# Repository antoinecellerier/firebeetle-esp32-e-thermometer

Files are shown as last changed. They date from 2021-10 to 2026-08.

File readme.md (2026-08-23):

A low power ESP32 based thermometer with an ePaper display

| Prototype | Custom board |
|---|---|
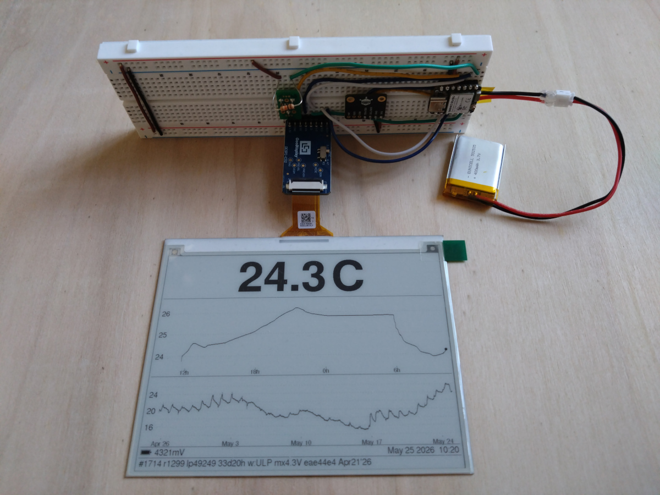
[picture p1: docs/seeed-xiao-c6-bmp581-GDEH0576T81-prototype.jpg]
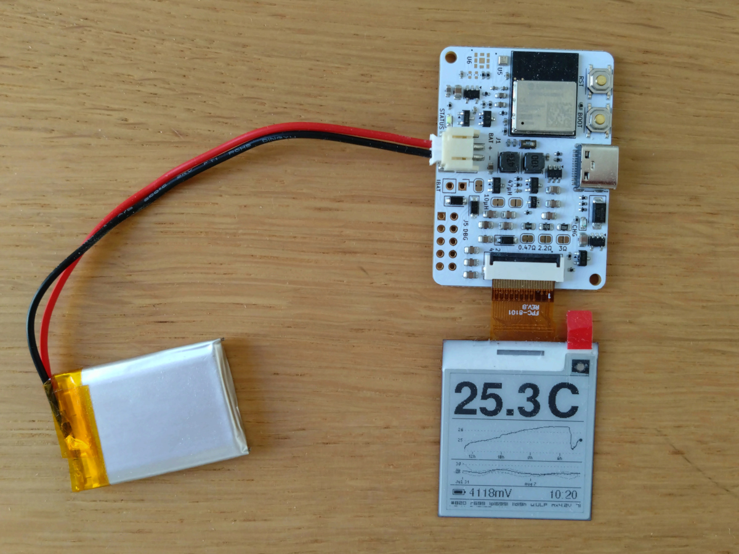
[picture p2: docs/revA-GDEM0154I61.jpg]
|||

See [docs/wiring.md](docs/wiring.md) for prototype wiring information and [hardware/thermometer-c6/](hardware/thermometer-c6/README.md) for the custom board. More pictures [lower down](#prototypes-in-action).

# Power consumption

Measured with a Nordic PPK2 on pure ESP-IDF firmware; full traces, dates and
methodology in [docs/notes.md](docs/notes.md). Figures are config-specific —
panel, sensor and board all matter.

**Read the node tag on every figure.** `@3V3 rail` is the load alone, with the
board's input tree bypassed; `@4V2 bat` is the whole deployment path, regulator
and charger leakage included. They are not interchangeable, and the battery
figure is not simply the larger one.

| Setup | Deep-sleep floor | Sensor wake | Wake + refresh |
|---|---|---|---|
| Firebeetle ESP32-E + BMP390L + GDEH0154Z90 via DESPI-C02 (FDN340P gate) | 19–20 µA `@3V3 rail` | ULP bit-bang I2C every 5 s, avg ≈0 | ~112 mC `@3V3 rail` (was ~600 mC before light sleep — the Z90's ~21 s refresh used to spin-wait) |
| XIAO ESP32-C6 + BMP581 + GDEH0576T81 via DESPI-C02 (FDN340P gate) | 15.5–16 µA `@3V3 rail` | LP core I2C every 60 s: ~1 mA × 3 ms | ~45 mC `@3V3 rail` — **superseded, re-measure** (see below) |
| XIAO ESP32-C6 + BMP581 + GDEW029I6FD via Seeed ePaper Driver Board (no gate) | ~25 µA `@3V3 rail`<br>**21.7 µA `@4V2 bat`** | LP core I2C every 60 s: ~1 mA × 3 ms | 12.2 mC `@3V3 rail`<br>**10.05 mC `@4V2 bat`** |
| thermometer-c6 rev A + BMP581 + GDEM0154I61 (on-board gated booster) | **18.3 µA `@4V2 bat`** | LP core I2C every 60 s | **~24.3 mC `@4V2 bat`** |
| thermometer-c6 rev A + BMP581 + GDEH0576T81 (on-board gated booster) | **19.05 µA `@4V2 bat`** | LP core I2C every 60 s | **36.77 mC `@4V2 bat`** |

The XIAO's GDEH0576T81 figure is **superseded**: it was taken while the panel ran
its coldest waveform LUT, which cost 48% of panel busy time. The last row is the
deployment configuration on the corrected waveform — daily budget and derivation
in [docs/notes.md](docs/notes.md).

A buck draws *less* current at 4.2 V than its load does at 3.3 V, which is why
~25 µA at the rail reads 21.7 µA at the battery (~90 % efficient). An LDO runs
the other way, ~1.15× the charge for the same work — so the custom board beating
the XIAO by 3 µA at the same 4.2 V is a real win, not a topology artefact. Its
wake figures include LED blinks, left on for observability. Blank cells are
unmeasured, not zero; both are on the PPK2 backlog.

The main CPU only wakes on a ≥0.1 °C delta or a safety-net tick, so a display
refresh is the dominant event on a typical day. At one refresh per hour that puts
long-term averages in the **~16–51 µA band depending on rig and refresh cadence**
— load-only runtime of roughly **1–3 years on a 400 mAh LiPo**, with the
deployment configuration measured at the bottom of that band (~2.3–3.8 C/day,
~380–620 days; derivation in [docs/notes.md](docs/notes.md)). But at this
current level LiPo self-discharge (a few %/month ≈ 15–25 µA equivalent) rivals
the load itself, so **expected runtime is on the order of a year**, and a
2600 mAh 18650 will age out before the load meaningfully drains it. Not yet
confirmed against a full-length run.

Two gotchas worth surfacing (the adapter-leakage ones are under Hardware below):
- **XIAO ESP32-C6 battery operation has a hard floor at ~3.6 V**: its 3.3 V rail is a pure buck (SGM6029C), which below VOUT + ~245 mV starves its bootstrap and lets the rail sag ~a VTH below VBAT — deep sleep survives, but wakes collapse into 0.5–0.9 A brownout-restart storms. Firmware shuts down at 3.7 V (~12–15 % of Li-ion capacity abandoned); full regime map in [docs/notes.md](docs/notes.md). LiFePO₄ cells (3.2 V nominal) are unusable on this board. The custom board uses an LDO and shuts down at 3.5 V instead.
- **Don't use the Seeed ePaper Driver Board's JST battery connector**: its ETA9740 charger/boost idles at ~330–500 µA — ~20× the whole system's sleep floor, flattening a 400 mAh cell in ~7 weeks doing nothing — and it double-converts BAT→5 V→3.3 V. Solder the battery to the XIAO's underside BAT pads instead, JST empty, switch off.

The Arduino-era ~20 mA deep-sleep USB CDC gotcha is gone: the pure-IDF
USB-Serial-JTAG console doesn't hold the port active.

For context: the original 2021 prototype (wake + refresh every 60 s, no ULP) ran a 2600 mAh cell flat in 8.5 days at ~12.6 mA average — the ULP/LP-core redesign is ~700× more efficient.

# Hardware

Looking to replicate this? Easy to start with options are tagged **[start with this]** below.

## Controller boards
- thermometer-c6 — the custom board this project builds towards, replacing the
  dev-board rigs below: ESP32-C6-MINI-1 + BMP581, a universal 24-pin FPC panel
  interface with the Good Display booster on-board and P-FET-gated, USB-C charging,
  an LDO 3.3 V rail, a GPIO-switched battery divider and a 32.768 kHz crystal.
  Schematic, PCB and rationale: [hardware/thermometer-c6/](hardware/thermometer-c6/README.md)
- Seeed Studio XIAO ESP32-C6 https://wiki.seeedstudio.com/xiao_esp32c6_getting_started/ **[start with this]**
- (Early 2021 prototype) Firebeetle ESP32-E https://wiki.dfrobot.com/FireBeetle_Board_ESP32_E_SKU_DFR0654
  - ESP32 datasheet https://www.espressif.com/sites/default/files/documentation/esp32_datasheet_en.pdf
  - ESP32-WROOM-32E datasheet  https://www.espressif.com/sites/default/files/documentation/esp32-wroom-32e_esp32-wroom-32ue_datasheet_en.pdf
  - TP4056 battery charger IC (onboard) https://dlnmh9ip6v2uc.cloudfront.net/datasheets/Prototyping/TP4056.pdf https://www.best-microcontroller-projects.com/tp4056.html

- ESP32 getting started https://docs.espressif.com/projects/esp-idf/en/latest/esp32/get-started/index.html
- ESP32 power consumption https://diyi0t.com/reduce-the-esp32-power-consumption/

## Temperature sensor (multiple options)
- BMP390L I2C interface:
  - datasheet https://www.bosch-sensortec.com/media/boschsensortec/downloads/datasheets/bst-bmp390-ds002.pdf
  - breakout board https://wiki.dfrobot.com/Fermion_BMP390L_Digital_Barometric_Pressure_Sensor_SKU_SEN0423
- BMP581 / BMP585 I2C interface (Bosch next-gen pressure sensors, ~0.5 µA deep-standby)
  - BMP581 https://www.bosch-sensortec.com/products/pressure-sensors/bmp581/
  - BMP585 https://www.bosch-sensortec.com/products/pressure-sensors/bmp585/
  - Fermion breakouts:
    - SEN0667 (BMP581) https://wiki.dfrobot.com/sen0667/ **[start with this]**
    - SEN0666 (BMP585) https://wiki.dfrobot.com/sen0666/
- (Early 2021 prototype) DS18B20-PAR OneWire interface
  - datasheet https://datasheets.maximintegrated.com/en/ds/DS18B20-PAR.pdf

## Display (multiple options)
- Good Display GDEW0154M09 black and white, 200x200, 1.54" fast full refresh https://www.good-display.com/product/206.html
- Good Display GDEW0213M21 black and white, 212x104, 2.13" DES screen https://www.good-display.com/product/354.html
- Good Display GDEW029I6FD black and white flex, 296x128, 2.9" (UC8151D, partial updates) https://www.good-display.com/product/209.html
- Good Display GDEM0154I61 black and white flex, 200x200, 1.54" (driven via GDEY0154D67 SSD1681 driver) https://www.good-display.com/product/535.html
- Good Display GDEH0576T81 black and white, 920x680, 5.76" HD (SSD2677, partial updates) https://www.good-display.com/product/702.html **[start with this]**
- (Early 2021 prototype) Adafruit 1.54" Tri-Color eInk / ePaper 200x200 Display with SRAM - SSD1681 Driver
https://www.adafruit.com/product/4868
https://learn.adafruit.com/adafruit-1-54-eink-display-breakouts?view=all
  - uses Good Display GDEH0154Z90 https://www.good-display.com/product/285.html

Good Display panels are driven through one of two adapters (same Good Display reference booster on both — panel compatibility notes in [docs/wiring.md](docs/wiring.md)):
- Good Display DESPI-C02 (switchable RESE 0.47/3 Ω) https://www.good-display.com/product/516.html
- Seeed ePaper Driver Board for XIAO (fixed RESE 0.47 Ω, ETA9740 charger — see gotcha above) https://www.seeedstudio.com/ePaper-breakout-Board-for-XIAO-V2-p-6374.html — wiki: https://wiki.seeedstudio.com/xiao_eink_expansion_board_v2/ **[start with this]**

The DESPI-C02's boost converter leaks ~534 µA in deep sleep, which an FDN340P P-channel MOSFET on the adapter's 3.3 V line eliminates; the Seeed board's ungated standby measured only ~9 µA, so it runs without a gate.

## Other components
- FDN340P P-channel MOSFET (SOT-23) — power-gates DESPI-C02 3.3 V during deep sleep
- AO3400A N-channel MOSFET (SOT-23) — switches the XIAO C6 battery voltage divider so it doesn't draw ~10 µA continuously

## Battery
- Current builds: PR502535 single-cell LiPo pouch, 400 mAh https://www.gotronic.fr/art-accu-lipo-3-7-vcc-400-mah-pr502535-5812.htm **[start with this or equivalent]**
- Original prototype: RS Pro 18650 26H Li-ion, 2600 mAh https://fr.rs-online.com/web/p/batteries-taille-speciale/1449406/

## Prototypes in action

### 2026 - ultra low power custom board

Custom rev A board (with BMP581), GDEM0154I61 & 400mAh battery

Thermometer C6 rev A board & GDEM0154I61 (2026)

Custom rev A boards (with BMP581), GDEH0576T81 & 400mAh battery

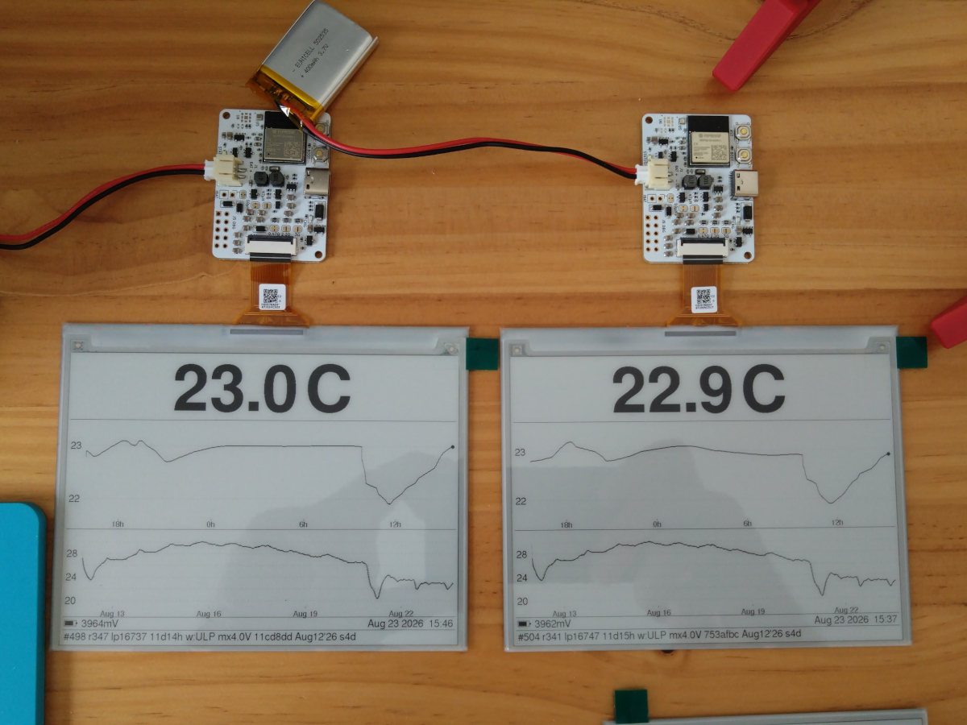
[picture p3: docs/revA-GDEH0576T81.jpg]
Thermometer C6 rev A boards 2 and 4 & GDEH0576T81 (2026)


### 2026 - ultra low power prototypes

Seed Xiao C6, BMP581, GDEH0576T81 & 400mAh battery

Seeed Xiao C6, BMP581 & GDEH0576T81 (2026)

Seeed Xiao C6, e-Paper Driver Board, BMP581, GDEW029I6FD & 400mAh battery

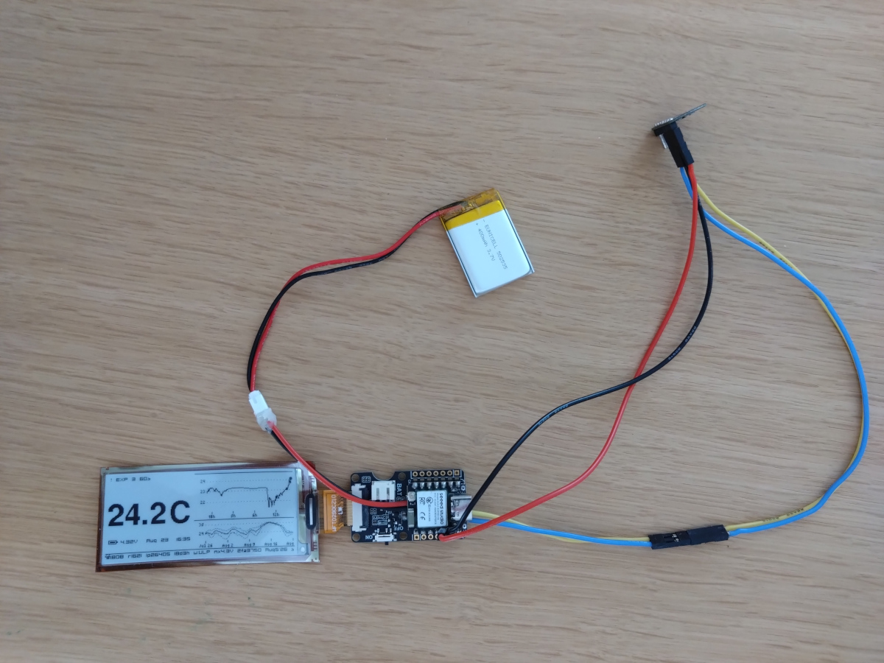
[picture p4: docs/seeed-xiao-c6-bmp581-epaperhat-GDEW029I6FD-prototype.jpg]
Seeed Xiao C6, e-Paper Driver Board, BMP581 & GDEW029I6FD (2026)


Firebeetle ESP32-E, BMP390L, GDEH0154Z90 & 400mAh battery

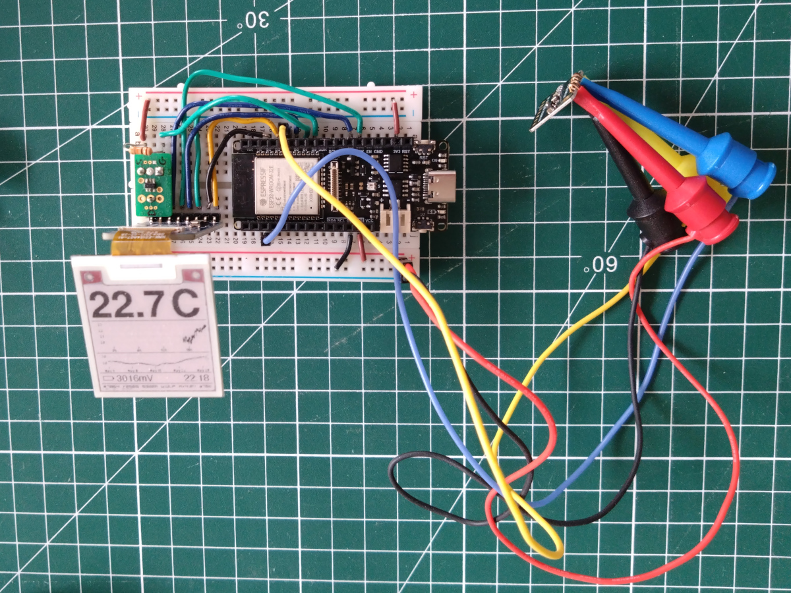
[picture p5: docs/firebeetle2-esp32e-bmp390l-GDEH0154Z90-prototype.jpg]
Firebeetle ESP32-E, BMP390L & GDEH0154Z90 (2026)


### 2021 - first prototype
Firebeetle ESP32-E, DS18B20, GDEW0213M21 & 2600mAh battery

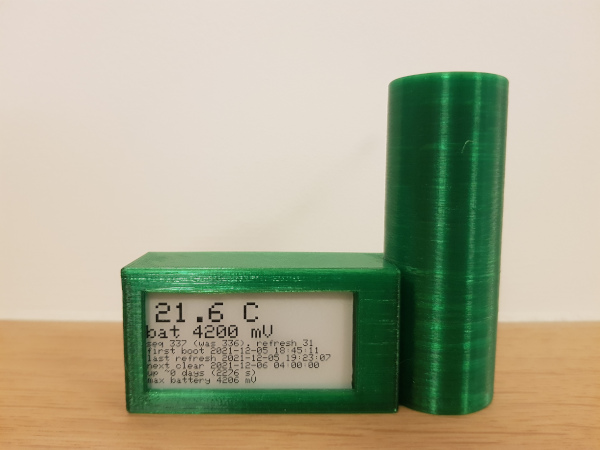
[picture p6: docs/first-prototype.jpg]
Assembled first prototype (2021)


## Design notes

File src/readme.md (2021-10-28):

A low power FireBeetle ESP32-E based thermometer with an Adafruit ThinkInk 1.54" ePaper display

# Hardware

## Controller board
- Firebeetle ESP32-E https://wiki.dfrobot.com/FireBeetle_Board_ESP32_E_SKU_DFR0654
- ESP32 datasheet https://www.espressif.com/sites/default/files/documentation/esp32_datasheet_en.pdf
- ESP32-WROOM-32E datasheet  https://www.espressif.com/sites/default/files/documentation/esp32-wroom-32e_esp32-wroom-32ue_datasheet_en.pdf
- TP4056 battery charger IC https://dlnmh9ip6v2uc.cloudfront.net/datasheets/Prototyping/TP4056.pdf
 https://www.best-microcontroller-projects.com/tp4056.html

- ESP32 getting started https://docs.espressif.com/projects/esp-idf/en/latest/esp32/get-started/index.html
- ESP32 power consumption https://diyi0t.com/reduce-the-esp32-power-consumption/

## Temperature sensor
- DS18B20-PAR datasheet https://datasheets.maximintegrated.com/en/ds/DS18B20-PAR.pdf

## Display
- Adafruit 1.54" Tri-Color eInk / ePaper 200x200 Display with SRAM - SSD1681 Driver
https://www.adafruit.com/product/4868
https://learn.adafruit.com/adafruit-1-54-eink-display-breakouts?view=all

## Battery
- RS Pro 18650 26H Li-ion Battery Pack https://fr.rs-online.com/web/p/batteries-taille-speciale/1449406/

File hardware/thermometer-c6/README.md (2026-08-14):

# thermometer-c6 — custom ultra-low-power e-paper thermometer board

Custom PCB replacing the XIAO-C6/FireBeetle dev-board rigs. ESP32-C6-MINI-1 +
BMP581 + universal 24-pin EPD interface with on-board gated booster, USB-C
charging, LDO power tree. Design driven by the PPK2 measurement campaign in
[`docs/notes.md`](../../docs/notes.md) (repo root).

Thermometer C6 rev A board & GDEM0154I61 (2026)

**Status: rev A built and working.** Ordered 2026-07-20
([`archive/order-2026-07-20/`](archive/order-2026-07-20/); landed €273.93 ≈
€68.50/assembled board, breakdown in [`ORDERING.md`](ORDERING.md)). Board 1
passed bring-up Phases 0–2 on 2026-07-29 ([`BRINGUP.md`](BRINGUP.md)): first
render, LP-core survival, and a measured 18.3µA @ 4.2V deployment-path sleep
floor over a full field interval (docs/notes.md 2026-07-29) — vs 21.7µA at
the same 4.2V on the XIAO buck rig, validating the LDO tree. **Phase 3 is under
way on board 2, not board 1**: the GDEH0576T81 panels arrived 2026-08-11 and
board 2 took one plus a battery, so the phase is no longer gated on board 1
leaving its soak (still running since 2026-07-31; harvest before resetting it).
Closed on board 2 that day: the deployment configuration's power figures
(19.05µA floor, 36.77mC wake+refresh `@4V2 bat`), the boost rails under the
heaviest waveform the panel can be given (no sag — this is the evidence the
rev B bridge deletion was waiting on), the VBAT_ADC point (−24mV at 4.2V, 2mV
from board 1), the battery-floor sweep, and the WiFi resync charges. Board 2
went straight to flash on the strength of board 1's pass, worked first time,
and is both the bench board and now the Phase 3 vehicle; boards 3–4 are still
in the bag. The board is 48×35mm
2-layer, hand-routed, DRC-clean at full severity; fab export is `make fab`
(gerbers/drill + CPL/BOM zip, git-hash+date stamped, gated by
`verify/check_fab.py`); pre-order schematic sign-off (requirements proven
against primary sources, findings + dispositions):
[`SCHEMATIC-VERIFICATION.md`](SCHEMATIC-VERIFICATION.md).

## Why these choices (measurement rationale)

| Decision | Measurement behind it |
|---|---|
| LDO (not buck) 3.3V rail | XIAO's SGM6029C buck: razor-sharp dropout cliff at 3.545V → 0.5–0.9A brownout storms; forces 3.70V firmware shutdown, wasting ~12–15% of pack (notes.md 2026-07-05) |
| P-FET-gated EPD booster | DESPI-C02 leaks ~534µA with panel asleep; FDN340P gate mod → ~18µA (notes.md) |
| Switched 100k/100k battery divider | Always-on 200k divider ≈ 10µA (~⅔ of the sleep floor); 1M/1M biases the C6 SAR ADC low (~300ns sample window) (wiring.md) |
| High-side divider switch | Low-side switch leaves the sense node at VBAT through the top 100k → pin ESD diode clamps into 3V3 above ~3.7V (~5µA at 4.2V) |
| Load-sharing USB path | Without it, no-battery USB operation is limited to the 100mA charge current — EPD refresh peaks at ~465mA |
| Reverse-battery P-FET (Q6) | JST vs Adafruit pigtail polarity is a real supply-chain trap; MCP73831 abs-max is −0.3V — one AO3401A makes it survivable |
| EPD gate soft-start (R24/C28) | GPIO14 slamming Q2 on charge-shares 10µF against the rail faster than the LDO loop — ~100µs ramp kills the brownout risk |
| VBUS sense (R22/R23 → GPIO4) | Firmware needs to know USB is present: VBAT_ADC reads the charger CV node while charging, and SoC logic must ignore it; zero draw with USB absent |
| Jumper-selected inductor (JP5/JP6) | 10µH proven on all panels; 47µH per the GDEH0576T81 datasheet (with 2.2Ω RESE) — jumpers sit on the switch-node side so the unselected coil idles on the DC rail |
| 32.768kHz crystal | C6 on internal RC runs hours fast over weeks (memory: project_c6_clock_drift) |

## Reference transcription: DESPI-C02 V1.0 (Good Display, 2018-07-06)

Transcribed from `hardware/DESPI-C02_SCH V1.0.pdf` (visual + embedded netlist),
2026-07-07. This is the booster we replicate (with EPD_VCC gating added).

### 24-pin 0.5mm FPC panel pinout (P1, "FPC24(0.5MM)")

| Pin | Name | DESPI connection | Pin | Name | DESPI connection |
|---|---|---|---|---|---|
| 1 | NC | — | 13 | SCLK | host SPI SCK |
| 2 | GDR | Q1 gate + R1 10k→GND | 14 | SDI | host SPI MOSI |
| 3 | RESE | Q1 source + Rsense→GND | 15 | VDDIO | 3.3V |
| 4 | VGL | C1 4.7µF/25V→GND | 16 | VCI | 3.3V |
| 5 | VGH | C2 4.7µF/25V→GND | 17 | VSS | GND |
| 6 | TSCL | — (touch variant only) | 18 | VDD | C7 1µF/50V→GND |
| 7 | TSDA | — (touch variant only) | 19 | VPP | C8 1µF/50V→GND |
| 8 | BS | R4 3Ω→GND (= tied low, 4-wire SPI) | 20 | VSH | C9 4.7µF/25V→GND |
| 9 | BUSY | host | 21 | PREVGH | C5 4.7µF/25V→GND + D3 cathode |
| 10 | RES | host + R5 10k→3.3V pull-up | 22 | VSL | C10 4.7µF/25V→GND |
| 11 | D/C | host | 23 | PREVGL | C11 4.7µF/25V→GND + D1 anode |
| 12 | CS | host | 24 | VCOM | C12 1µF/50V→GND |

### Booster topology (all diodes MBR0530; orientation by function, not pin #)

- L1 10µH/1A: 3.3V → SW node
- Q1 Si1308EDL N-FET: gate=GDR (R1 10k bleed to GND), drain=SW, source=RESE
- RESE → Rsense → GND. DESPI: slide switch selects R3 0.47Ω or R2 3Ω.
  **This board: three parallel legs, each Rsense in series with a solder
  jumper: 0.47Ω (default-bridged) / 2.2Ω / 3Ω.**
- D3: anode=SW, cathode=PREVGH (boost rectifier)
- Negative charge pump: SW → C3 4.7µF/25V → X node; D2 anode=X, cathode=GND;
  D1 anode=PREVGL, cathode=X
- 3.3V rail bulk: C4 4.7µF/25V. (On this board the whole block hangs off the
  gated EPD_VCC rail, and the RES pull-up goes to EPD_VCC — never 3V3.)
- There are **no** PREVGH↔PREVGL/VCOM bridge caps in the real reference
  (the abandoned draft in `hardware/kicad/` invented them).

## ESP32-C6 pin map

| GPIO | Function | Notes |
|---|---|---|
| 0 / 1 | XTAL_32K_P / N | FC-135 32.768kHz + 20pF; R9 10M bias DNP — the C6's 32k oscillator amplifier runs at very low gm, so startup margin depends on crystal ESR spread (≤70kΩ allowed, rises when cold) and stray C; the parallel bias resistor (Espressif HDG checklist) gives the inverter a DC feedback path if a given board/batch won't start |
| 2 | VBAT_ADC (ADC1_CH2) | sense node of switched divider; 0V when divider off |
| 3 | VDIV_EN | 100k pull-down → divider hard-off in deep sleep |
| 4 | VBUS_SENSE (100k/100k from VBUS) | USB-presence detect; divider is dead (0V, zero drain) with USB unplugged |
| 5 | spare → J5 debug header | strap-adjacent (SDIO clock-edge only at default eFuses) — keep high-Z |
| 6 / 7 | LP I2C SDA / SCL | fixed by silicon; BMP581; 4.7k pull-ups to 3V3 |
| 8 | spare → J5 | STRAP: must be free to pull high for download boot — header only |
| 9 | BOOT button | strap, its intended use; 10k pull-up |
| 12 / 13 | USB D− / D+ | native USB-Serial-JTAG via USBLC6-2SC6 |
| 14 | EPD_PWR_EN (P-FET gate) | chosen because it is NOT in the SDIO strap group (GPIO18–23 can toggle during early boot, esp-idf #11975); 10k pull-up → panel off at reset/sleep |
| 15 | Status LED | safe: JTAG_SEL strap ignored at default eFuses |
| 16 / 17 | UART0 TX / RX → J5 | module pins TXD0/RXD0 |
| 18–21 | EPD MOSI/SCK/CS/DC | SDIO-group boot toggles drive an unpowered panel — harmless |
| 22 | EPD RST | 10k pull-up to **EPD_VCC** (gated) |
| 23 | EPD BUSY (input) | |

## Debug header J5 (2×5, DNP — GND-first, no VBAT)

The silk carries only a `DBG` marker (no room for a per-pin legend at ≥0.8mm),
so the pinout lives here. Standard 2×5 numbering, pin 1 = the marked corner:

| Pin | Signal | | Pin | Signal |
|---|---|---|---|---|
| 1 | GND | | 2 | +3V3 |
| 3 | EN (reset) | | 4 | DBG_TX (UART0 TXD0, GPIO16) |
| 5 | DBG_RX (UART0 RXD0, GPIO17) | | 6 | VBUS_SENSE (GPIO4) |
| 7 | DBG_IO5 (spare GPIO5) | | 8 | DBG_IO8 (spare GPIO8, strap) |
| 9 | GND | | 10 | GND |

DNP by default — solder a header only if you need wired debug/UART. **BOOT is
not on J5** (it's the SW2 button only); only EN is exposed here.

## Charging rule (product decision, 2026-07-07)

**Charge indoors only (0–45°C).** The MCP73831 has no thermistor input;
charging LiPo below 0°C plates lithium. The board carries this on back silk
(`CHARGE INDOORS 0-45°C`). Related: don't leave USB permanently attached — the
charger float-cycles the cell between ~3.95V and 4.2V indefinitely.
Firmware should also refuse to advertise "charge OK" below 0°C using the
BMP58x temperature (belt and braces; it cannot stop the charger).

## Inductor solder jumpers (JP5/JP6) — bridge exactly one

| Bridge | L | Pair with |
|---|---|---|
| JP5 (default) | L1 10µH | RESE 0.47Ω or 3Ω — the proven DESPI-C02 config for all six panels |
| JP6 | L2 47µH | RESE 2.2Ω (JP3) — the GDEH0576T81 datasheet booster spec |

## RESE solder jumpers (JP2/JP3/JP4) — bridge exactly one

| Bridge | Rsense | Panel family |
|---|---|---|
| JP2 (default) | 0.47Ω | GDEW/GDEY (UC81xx): GDEW0154M09, GDEW0213M21, GDEW029I6FD, GDEM0154I61; proven with GDEH0576T81 too (DESPI-C02 heritage) |
| JP3 | 2.2Ω | GDEH0576T81 per its datasheet (bridge JP6 to select L2 47µH with it) |
| JP4 | 3Ω | GDEH/GDEM SSD16xx: GDEH0154Z90 (tri-color), GDEH0154D67, GDEH0213B73, GDEH029A1 |

## Bench procedures

- **PPK2 source-mode power, deployment path (used for all published board-1
  figures)**: feed J1 through a Dupont-into-JST harness, JP1 untouched. Q6
  and the MCP73831 VBAT-pin leakage are in the measurement by construction —
  true battery-terminal figures. `tools/ppk2.py` rail id: `reva-j1` (also
  what `ppk2.py sweep` sweeps for the battery-floor regime map).
- **IBAT break — battery-current (series) measurement**: cut JP1 open and
  insert a PPK2 (or any ammeter) across J2 (the 2-pin header silk-labelled
  `IBAT`, DNP by default — solder one in). Battery in JST as usual. JP1
  ships as a factory copper bridge: knife-cut it the first time, re-close
  with solder afterwards (wicking only applies to a soldered re-bridge).
- **PPK2 source-mode at J2**: feed J2 pin 2 + GND, JST empty, JP1 open.
  Pin 2 is VBAT — the charger output node, not VSYS (VSYS has no TP or
  header; probe D2's cathode pad). Powers the LDO tree + charger but
  excludes Q6. `tools/ppk2.py` rail id: `reva-j2`.
- **Do NOT back-feed the 3V3 test pad**: RT9080 abs-max forbids VOUT > VIN
  + 0.3V, and its EN=0 active-discharge (~80Ω) would fight the source.
  TP4 (3V3) is probe-only.
- Charge current: R3 10k → 100mA (0.25C for a 400–500mAh pouch). 4.99k →
  200mA if a bigger pack is fitted.
- C29 (10nF ADC reservoir on VBAT_ADC) is populated by default: enable the
  divider ~5ms before reading (τ = 50k × 10n = 0.5ms).
- BMP58x INT pins are unconnected: firmware must configure int_en=1,
  int_od=0, pad_int_drv=0 per the Bosch datasheets.
- Battery thresholds are board-scoped in Thermometer.cpp: **3550 warn /
  3500mV shutdown** (applied 2026-07-31 from the sweep + BOD-probe
  measurements, notes.md 2026-07-30 — droop at the refresh peak ≈300mV, so
  3500 keeps ~200mV of rail margin over the C6's 3.0V spec floor). That
  recovers most of the ~25% of pack capacity the buck-era 3700mV cutoff
  stranded; the cold and real-cell BOD-probe runs decide whether 3450
  (~5-8% more, OCV estimate) is safe.
- The first-article measurement list lives in [`BRINGUP.md`](BRINGUP.md)
  Phase 3 (VGH/VGL spec at refresh, EPD_VCC soft-start ramp, 3V3 sag →
  threshold re-derivation, boost ILIM transient, 32k crystal cold start,
  SS14 warm-floor leakage, VBAT_ADC sweep, charging self-heat). The 32k crystal
  is proven running warm on board 1 (no RTC fallback warning); cold start
  remains open.
- While charging, the board self-heats slightly — BMP581 temperature reads
  high until it cools; log accordingly.

## BOM

Generated at `bom/thermometer-c6-bom.csv` (JLCPCB columns) from circuit.py.
Notable parts: ESP32-C6-MINI-1-N4 (C5736265), RT9080-33GJ5 (C841192),
MCP73831-2 (C424093), Si1308EDL (C469327, low stock — fallback Si1304BDL
clone C7419947), MBR0530 TWGMC (C5204746), FPC-05FB-24PH20 dual-contact
(C2856831), SWPA4030S100MT (C38117), FC-135 (C32346), BMP581 (C5362283 —
**restocked at LCSC as of 2026-07-17** (3,675 pcs); the fab BOM populates
U5 by default. Re-verify stock at order time like everything else).

DESPI-C02 §4.5 requires an FPC socket with "contact at up side or both
side" — hence the dual-contact FPC-05FB (the bottom-contact-only
FPC-05F-24PH20 C2856805 must NOT be substituted). **Rev B anti-regression
note — this became a measured requirement on 2026-08-11, not a paper one.**
The GDEH0576T81's FPC carries its contacts on the REAR face (away from the
screen); every other panel bench-tested here — GDEM0154I61, GDEY0213M21,
GDEH0154Z90, GDEW029I6FD — has them on the FRONT. A single-side socket would
therefore have worked on every panel used during bring-up and failed on the
one panel this board is being built for. It is exactly the line item a
cost-down pass reads as unnecessary margin; it is not. J4 uses the hand-drawn
`local:XUNPU_FPC-05FB-24PH20` footprint, transcribed from the XUNPU
FPC-05FB-NPH20 manufacture drawing (pads 0.3×1.2 @0.5mm, tabs 2.0×1.8 at
±7.3/+1.625 center-to-center) and cross-checked against the EasyEDA/JLC
C2856831 land pattern — the two agree exactly. The FPC-05FB is a rear-flip
connector: the SMT contact tails / pad row sit at the REAR (actuator) face,
and the mouth / cable entry is on the far side, 4.95mm from the pad centers
(body depth 5.40 = the XUNPU drawing; VERTEX_POINT-only STEP bbox,
`out/j3-land/` §7 2026-07-20 — the earlier 6.55 came from bounding-boxing
raw CARTESIAN_POINTs, which include LINE/AXIS2_PLACEMENT_3D entities that
own no geometry). On the board J4 is placed at rot 90 with the tail/pad
column WEST (x41.45) and the mouth EAST at x46.40, so the panel cable
approaches from the east edge. The mouth sits 1.60mm inboard of the edge
rather than flush — harmless for an FPC (the cable bottoms out inside the
housing either way) and it leaves the body fully supported. Pad 1 = panel circuit 1 sits at the NORTH end (the footprint pads are
numbered to keep pin 1 north despite the rear-flip geometry; the pin-1 silk
dot marks it). Pin-1 direction is verified against the DESPI-C02 manual
photos (P1 silk: "1" and "24" end markers, "24" at the P1-refdes end); note
the DESPI "P1" silk next to the pin-24 marker is the connector refdes, not
pin 1.

## Alternate sensor: BMP585 (U6, DNP by default)

The board carries footprints for BOTH BMP581 (U5, LGA-10 2×2) and BMP585
(U6, LGA-9 3.25×3.25, media-resistant — suitable for outdoor/weather-exposed
builds; gel-protected port under the metal lid, keep the Ø2.2mm opening
unobstructed in the enclosure). Same LP I2C bus, same 0x47 strapping
(CSB+SDO→VDDIO), same register map — the firmware BMP58x driver reads the
chip-ID (0x50=581, 0x51=585) and works with either unchanged.
**Populate exactly one**: both strap to address 0x47.
BMP585 = LCSC C18184976. Its datasheet
requires a 10Ω supply series resistor only for supply ramps <10µs — not
applicable here (always-on 3V3 rail, never GPIO-gated).

## Regenerating

```
make check   # generate + ERC + netlist golden check + invariants + footprints
make pdf     # out/thermometer-c6.pdf for review
```

The `.kicad_sch` is generated by `generator/generate.py` from
`generator/circuit.py` (nets/parts) + `generator/layout.py` (placement and
drawn wire routes) — edit those, never the .kicad_sch. Connectivity is
verified three ways: generator geometric checks (cross-net coincidence =
build error), `kicad-cli` ERC at zero tolerance, and exact netlist matching
against circuit.py (anonymous `~` nets matched by pin set).

## Open items (user sign-off) — all dispositioned

1. **BMP581 sourcing** — RESOLVED 2026-07-17: restocked at LCSC (3,675
   pcs); the ordered boards populate U5 BMP581. The BMP585 (C18184976)
   remains the U6 populate-one alternate (outdoor/media-resistant builds,
   or if the 581 dries up again).
2. **Si1308EDL stock thin** — RESOLVED by the order: C469327 is on the
   boards; the fallback Si1304BDL-clone C7419947 was never needed.
3. **Reverse-polarity protection** — RESOLVED: Q6 AO3401A P-FET at the
   JST is fitted (see "Why these choices"); a reversed cell is blocked,
   MCP73831's −0.3V abs-max is respected. Proven on board 1: body diode
   0.4259V diode-mode pass ([`BRINGUP.md`](BRINGUP.md) Phase 0). Keyed JST
   + silk remain the first line of defense.
4. **EPD SPI/control series resistors omitted** — CLOSED by construction,
   no veto: boards fabbed without them, firmware floats the pins when the
   panel is gated off (src/Display.cpp), first render passed on board 1.
   Disposition recorded in [`SCHEMATIC-VERIFICATION.md`](SCHEMATIC-VERIFICATION.md).
5. **JST-PH polarity** — RESOLVED 2026-07-29 on hardware: DMM on the loose
   plug, red wire / + contact mates with J1's `+`-marked pad
   ([`BRINGUP.md`](BRINGUP.md) Phase 0). JST vs Adafruit convention still
   differs — re-check any new pigtail.
6. **FPC footprint** — DONE and hardware-verified: hand-drawn
   `local:XUNPU_FPC-05FB-24PH20` (see BOM section), respun 2026-07-19
   after a numeric STEP proof (`out/j4-proof/`), body depth corrected to
   5.40 on 2026-07-20. Placement verified pre-order (75/75 placements,
   [`archive/order-2026-07-20/`](archive/order-2026-07-20/)); J4 pin-1 north
   / mouth-east confirmed by continuity on board 1
   ([`BRINGUP.md`](BRINGUP.md) Phase 0).
7. **32k crystal populated by default** — CONFIRMED: on the ordered boards
   and proven oscillating on board 1 (no RTC fallback warning in the boot
   log); cold start remains a [`BRINGUP.md`](BRINGUP.md) Phase 3 item.
8. **Old Copilot draft** — MOOT as originally written: `hardware/kicad/`
   was never merged and exists only on the unmerged branch
   `hardware/custom-esp32c6-pcb`. Nothing in the tree to delete; the
   remaining call is whether to delete that branch.

## Follow-up phases

- PCB layout (2-layer) — **DONE**: booster switch loop tight, RESE sense
  short, no-copper zone under BMP581, antenna keep-out per Espressif HDG,
  JLCPCB gerbers/drill + CPL/BOM via `make fab` (order per
  [`ORDERING.md`](ORDERING.md)).
- Firmware — **DONE**: `THERMOMETER_C6_BOARD` variant (`thermometer_c6_*`
  envs in platformio.ini): EPD on GPIO18–23 + gate GPIO14 with float-on-off,
  battery divider GPIO2/3, VBUS sense GPIO4 (suppresses SoC shutdown on USB),
  LED GPIO15, 32k crystal via `sdkconfig.defaults.thermometer_c6`.
- Fab order — **DONE** (2026-07-20,
  [`archive/order-2026-07-20/`](archive/order-2026-07-20/); landed cost
  breakdown in [`ORDERING.md`](ORDERING.md) §8).
- Bring-up Phases 0–2 — **DONE** on board 1 (2026-07-29,
  [`BRINGUP.md`](BRINGUP.md)); measured numbers in the
  [`docs/notes.md`](../../docs/notes.md) power logbook.
- **NEXT** (hardware): [`BRINGUP.md`](BRINGUP.md) Phase 3 first-article
  measurements. Board 1 has been on battery soak since 2026-07-31 and most of
  Phase 3 waits on it. Boards 3–4 need bringing up, but not the full Phase 0–1
  checklist — board 2 skipped it and worked; only board 4's flagged U5 skew
  wants the Phase 2 sensor detect run early.

## Routed-copper census (rev A final vs the pre-connector-fix board)

`python3 verify/copper_stats.py --vs 9100758` — baseline `9100758` is the last
commit before the J4 mouth-east respin, the J3 datum/land fork and the R2.2
corners. Tracks and vias only; pours are regenerated fill, not authored copper.

```
segments   977 ->  906     -71  (-7.3%)
vias       189 ->  154     -35 (-18.5%)
F.Cu mm  756.1 -> 643.5  -112.5 (-14.9%)
B.Cu mm  840.6 -> 736.2  -104.4 (-12.4%)
total   1596.6 ->1379.7  -216.9 (-13.6%)
nets shorter 40   longer 2   ~unchanged 18   (of 60)

vias by region   FPC/east x>36  36 -> 27      USB/north y<9  51 -> 28
                 west x<20      84 -> 72
```

Putting both connectors on their true datums made the board measurably
simpler rather than merely correct: the USB/north region shed 45% of its vias
and CHG_STAT/EPD_SCK/VBUS/VBAT each lost 12–19mm. Routing style is
deliberately free-angle (≈48% of copper length off the 45/90 grid) — that is
a choice, not drift.

## Rev B candidates

Deliberately NOT taken for rev A — each is real but none justifies a respin
of a board that is otherwise order-ready.

- **Panel readback (SDO) — open, and per-controller.** Whether the panel can
  answer the host at all depends on its controller, not on this board, so there
  is no single answer to carry forward.
  **UC8151 works on the wiring as built**: probed 2026-08-05 on board 2 with a
  GDEY0213M21, `0x70` → `01 0e`, `0x71` → `13 13`, `0x40` → `d2 00`, each byte
  identical whether the input was pulled up or down (i.e. actively driven), while
  foreign SSD168x commands floated — that contrast is the control.
  **SSD2677 (the T81) is untested, and no longer "unlikely".** An earlier note
  here said it could not reply because the FPC carries no SDO. That was wrong:
  `SSD1677.pdf` names `SDI`/`SDO` as separate **chip** pins in 4-wire mode, but
  the T81 module bonds a single `SDA` to FPC pin 14 — exactly like every other
  panel here, none of which exposes an SDO either. Its module datasheet calls that
  pin an input and documents no read procedure, which was equally true of the M21
  before the M21 answered. **Probe a T81 before concluding anything.**
  **It has never been asked, only never listened to.** `_Init_Full` reads the
  controller temperature to pick a waveform LUT and gets 0, but GxEPD2's
  `_readData()` samples the line in software and works only in bit-banged mode,
  and this build runs hardware SPI — so no wiring conclusion follows from the 0.
  **This stopped being a board question on 2026-08-11.** The LUT consequence is
  fixed in firmware (upstream's guarded 20–30 °C fallback, then the BMP581 value
  fed in directly), and feeding a calibrated ambient reading beats any readback
  of a self-heating die — so neither 3-wire mode (a 9-bit protocol GxEPD2's
  4-wire path does not implement) nor an SDO on the FPC buys anything a rev B
  should pay for. A probe is now worth running for the cross-check alone:
  `display_probe_readback()` behind `EPD_PROBE`.
  **What is readable is narrow, and per-controller.** On the UC8151 only three
  registers answer — `0x70` REV, `0x71` FLG, `0x40` temperature — and they answer
  identically before and after GxEPD2's init. `0x61` TRES and `0x00` PSR **float**,
  so resolution cannot be read back: the datasheet calls TRES a host-set override
  anyway, and probing before init confirmed it is not merely being overwritten.
  Resolution would in any case only ever **falsify** a match, never confirm one —
  two different 200x200 panels agree on it. The one panel-intrinsic value on offer
  is `0x70`'s `LUT_REV`, sourced from OTP address `0x001`, since a waveform LUT is
  tuned to its glass. Caveat before trusting it as an ID: our bytes (`01 0e`) do
  not match the datasheet's documented `CHIP_REV` of `1101b`, so the framing (a
  dummy first byte on OTP reads, or bit alignment) is unresolved — the values are
  stable and repeatable, so they serve as an opaque fingerprint, but should not be
  reported as "the chip revision" until that is settled. And nothing here
  transfers: an SSD168x command set floats entirely on a UC8151, so every panel
  family needs its own probe table.

- **Shrink the board east (48×35 → 47×35 or further).** J4's mouth is at
  x46.40, already 1.60mm inboard of the east edge, and there is no copper
  east of x46.0 (easternmost feature: the GND via at (45.60, 28.25)). The
  binding constraint on the 48.0 edge is **H1**, not J4: a ⌀2.2 hole at
  (45.8, 2.2) with the R2.2 corner arc concentric with it, giving a uniform
  1.100mm ring of FR4 around the corner. Shrinking means moving H1 west with
  the edge and re-centring both east corner arcs — the FR4 ring survives at
  1.100mm, but H1's ⌀4.993 screw-head keepout then overlaps Q1's courtyard
  by 0.806mm. No fab saving (1680 → 1645mm² is the same JLC tier), so this
  is only worth doing as part of a placement pass that gives Q1 somewhere to
  go. Study, scripts and renders: `out/east-shave/`.
- **Q1 clears H1's ⌀4.993 screw-head keepout by only 0.105mm** on the
  current board (nearest Q1 courtyard corner (43.345, 3.062) is 2.602mm from
  H1's centre). Independent of any shrink; worth a deliberate look in a rev B
  placement pass.
- **USB connector-segment symmetry.** `USB_D+`/`USB_D-` (U3→U1) are matched
  to 0.024mm, but the connector segment is not: D+ is daisy-chained *through*
  B6 to A6 (a series node, not a tap) while D- gets a balanced tee, so
  end-to-end skew is +2.31mm (B-row mated) or +5.21mm (A-row). 1.90mm of
  that is pure USBLC6 pinout — pins 1 and 3 sit 1.90mm apart on the same
  SOT-23-6 edge — and would vanish for free by swapping which (symmetric)
  channel carries which polarity. Irrelevant at the C6's 12 Mbps full speed
  (~31ps against an 83,333ps bit period, 4–20ns edges); it would start to
  matter only if this path ever carried High Speed.
- **Sensor placement against the board's heat sources — open, and not the swap
  it first looks like.** Edge-to-edge courtyard gaps:

  | heat source | → U5 (fitted) | → U6 (DNP alt) |
  |---|---|---|
  | U1 ESP32-C6 module | 2.25mm | 4.25mm |
  | U2 RT9080 LDO | 4.90mm | 3.00mm |
  | U4 MCP73831 charger | 36.8mm | 38.0mm |

  Populating U6 instead of U5 gains 2.0mm from the module and gives back 1.9mm
  to the LDO, so as a thermal move it is close to a wash — the obvious "put the
  default sensor at the far site" is not obviously an improvement.

  Which source matters depends on the mode, and duty cycle dominates the
  arithmetic (all figures below are calculated, none measured):
  - **Charging**: (5.0−3.7)V × 100mA ≈ **130mW continuous** at U4 for the whole
    CC phase — much the largest steady source, and 37mm from both sites, so it
    reaches the die as whole-board bulk warming through the pour rather than as
    a local gradient. **Sensor placement cannot fix this one**; a thermal moat,
    a lower charge current, or suppressing/flagging readings while charging are
    the levers.
  - **Deployed on battery**: the CPU is awake ~1s per wake, so ~100mW while
    awake time-averages to single-digit mW, and the LDO is sub-mW. Nothing here
    needs fixing — this is the mode the device actually lives in.
  - **Parked on USB** (the new service window, `docs` in `BRINGUP.md` Phase 3):
    the CPU is continuously awake, ~100mW at 2.25mm, plus ~50mW at the LDO
    (1.7V drop at ~30mA) 3–5mm away. This is the mode where local placement
    would actually pay, and it is a bench mode, not a deployment one.

  The no-pour keep-outs under both sensors already remove the plane coupling
  (Bosch thermal-fidelity guidance) but buy no distance.

  **There is no usable measurement yet.** Board 1's 33.9°C-vs-29.8°C is not
  evidence: it mixes bench sun, USB self-heat and the operator's fingers on the
  board (it decayed afterwards). Get a clean equilibrium delta per mode before
  anyone moves a footprint — `BRINGUP.md` Phase 3.

  If placement is revisited, the target is a site far from **both** U1 and U2 —
  the south/south-west edge — not U6's slot. Note a literal U5/U6 coordinate
  swap is infeasible anyway: U6's courtyard is 3.5mm square against U5's 2.2mm,
  and the northern slot has 0.45mm of headroom with the antenna keep-out and C12
  boxing it in, so it wants a re-flow of the sensor picket (U5/U6 +
  C12/C13/C26/C27), which is also what would let both move away from the LDO.
  Rev A can still bound the U1-proximity term on its own: the sites are
  populate-exactly-one and the driver reads the chip ID (0x50/0x51), so building
  one of boards 2–4 with U6 gives an A/B on the same rig (confounded by the
  different package and die-to-pad path). Needs a BMP585 (C18184976) in the next
  order.
- **No GND reference under the USB path.** Opposite-layer pour coverage is
  16.8% / 0.0% / 2.4% / 0.0% across the four USB nets against 28%/40%
  board-wide — the 0.5mm zone clearance starves the pour out in the dense
  x18–27, y6.7–15 window. The long D+ vertical crosses six foreign nets on
  B.Cu in 4.9mm and the two western signal vias have no GND stitch within
  4mm. Acceptable at full speed and the EPD boost switching nodes are not
  among the crossings, but it is the condition the path runs in.
- **Add key presses on silkscreen.** It would make it obvious how to recover.
  Especially: download mode, restarting firmware, as those are not softare
  defined. The shutdown sequence would be interesting as well but might not be
  a good idea as it could change.

### Cost reduction (researched 2026-07-22)

Baseline: the €204.94 qty 5 PCB / 4 assembled itemised quote in ORDERING.md
§8. The order landed at €273.93 (€211.93 JLC invoice 2026-07-27 + €62.00
DHL) ≈ €68.50/assembled board — breakdown in ORDERING.md; the per-unit
analysis below reasons from the quote. Three structural facts frame
everything: **Economy PCBA is unreachable
regardless of PCB options** (U1 and U5 are Standard-PCBA-only parts, both
locked; Economy is also single-sided-placement, ≤50pcs), **X-Ray is
mandatory** for U5's LGA and U1's shield (tiered per inspected piece —
$1.57/pc at 1–10; the €11.46 ≈ 2 parts × 4 boards — so it scales with
quantity, it is not a flat order fee), and **no wireless SoC or
environmental sensor exists in the JLC Basic tier at all** (verified
2026-07-23: Basic-filtered library probes for ESP32/ESP8266/nRF/BL602/
W800/CH57x/CC25xx/RTL87xx all return zero) — so feeder-fee optimisation is
small-bore and the real levers are POFV, quantity, and BOM-line count.
Tier/stock facts below re-verified 2026-07-23 against JLC's own part API
(`getComponentDetail`); fee-policy facts against jlcpcb.com's live
assembly-price page. The order dialog remains ground truth at order time.

- **Drop POFV in a rev B re-route: −€44.07/order, the single largest line.**
  Not a touch-up: a full via audit of the committed board found **81 vias in
  solderable pads** (independently reproduced 2026-07-23 with a pcbnew
  script: 84 via centres in mask-open SMD pads, 81 excluding the JP2/3/5
  copper-jumper pads) — via-in-pad is the board's core 2-layer escape
  strategy.
  ~50 have a legal dog-bone spot against today's copper (FPC-east fanout
  column, central EPD-driver discretes, all GND stitches); **26 are
  hard-boxed** with no clear spot within 1mm — dominated by 12 ESP32-C6 QFN
  pins (0.4mm pads narrower than the 0.6mm via), the 32k crystal pair, the
  sensor pins, and the USB-C VBUS/CC joints. J4 (0.5mm FPC) and U5 (LGA)
  are already via-in-pad-free, so nothing is geometrically impossible.
  Opportunity cost: days — grow the outline (free up to JLC's 100×100mm
  tier), re-place the west/QFN cluster, re-route essentially from scratch,
  full-severity DRC again, and a fresh first-article risk. Best bundled
  with the Q1/H1 placement pass above and the production-copper trim below
  (the freed bench-pad corridors are exactly where the dog-bones must go).
  Before committing to it, confirm POFV is a flat charge vs qty (quote at
  5/10/20) — if flat, large orders amortise it and weaken the case. The
  scaling is not documented anywhere public (checked 2026-07-23: JLC's
  extra-charges article doesn't list POFV; the only official pricing fact
  is that POFV is free on 6–20-layer boards, paid on 2/4-layer), so the
  quote calculator is the only oracle.
- **Panel-lock BOM collapse: −€3–9/order.** Locking the panel family to the
  proven 10µH/0.47Ω config deletes L2 (47µH, Extended), R15 (2.2Ω) and R16
  (3Ω) plus their placements; JP2–JP6 are copper-only and can stay.
  Opportunity cost: the board loses the GDEH0576T81-datasheet booster
  option (47µH + 2.2Ω RESE) and the 3Ω SSD16xx leg — fine iff the panel
  choice is final; the copper jumpers keep a hand-solder escape hatch.
  **The evidence this was waiting on landed 2026-08-11: no sag.** PREVGH
  (C5) +20.031 V and PREVGL (C11) −19.380 V, means repeating to 20 mV and
  73 mV across refreshes, both flat for the whole ~3.03 s drive of the
  **LUT 235 waveform** — the heaviest the T81 can be given — on the factory
  JP2/JP5 bridges with nothing reworked. A pump short of the load would
  decay across that window; neither rail does. With GDEM0154I61,
  GDEY0213M21 and now the T81 all working on the universal config, the
  datasheet pair is margin nothing has needed. Numbers and the two limits
  (measured ahead of the panel's internal regulation; 10 Hz sees nothing
  under ~100 ms) in `../../docs/notes.md`.
- **MBR0530 → B5819W (C8598) confirmed-Basic swap: −~€2.75/order.** Same
  SOD-123 package, 40V/1A vs 30V/0.5A. Verified 2026-07-23 via the JLC
  part API: **Basic tier, 621k stock, $0.029** (MBR0530 C5204746 confirmed
  Extended). Vf 600mV@1A vs 500mV@500mA costs a hair of refresh
  efficiency; reverse leakage is irrelevant (the whole booster hangs off
  gated EPD_VCC). Caveat: the −€2.75 assumes the per-Extended-line feeder
  billing the 2026-07-20 quote exhibited — under JLC's *documented*
  Standard-PCBA policy ($1.50 × every unique line, Basic included) the
  swap is feeder-neutral and saves only pennies of part cost. Resolve the
  feeder question (ORDERING.md §3/§4) before counting this saving.
- **C98192 (4.7µF/50V, 9 placements, one Extended line) → C440198
  candidate Basic swap: −~€2.75/order, same caveat.** There is no Basic
  4.7µF ≥50V 0805 (verified 2026-07-23; the only Basic 4.7µF 0805 is
  25V), but **C440198 10µF 50V X5R 0805 is Basic** with 2.4M stock.
  Doubling the pump/reservoir caps (C16–C24) and the VBUS-side C5/C6
  needs booster re-validation (startup surge, pump timing) — try only
  with a bench board to compare against, and mind X5R DC-bias derating
  at the ~22V rails is similar for both parts.
- **Production-copper trim (dev board → production board): −~€1–6/order,
  but mainly routing room.** The board already carries its debug features
  as DNP/copper-only (J5, J2, JP1–6, all TPs, R9, U6), so they cost
  nothing at assembly. What a production variant can still cut: SW1/SW2 →
  tweezer-shortable pads (keeps the unbrick path — USB-Serial-JTAG download
  works but the device deep-sleeps ~99% of the time, so a physical
  BOOT-at-power-on path is worth keeping in some form) and D3 (status is
  the EPD's job). Keep D1: CHG_STAT reaches no GPIO, so it is the only
  charge indication. The real value is deleting TP/J5/J2/U6 copper in the
  same pass — TP7 alone pinches the B.Cu channel south of the booster to a
  0.30mm slot, and the bench pads impose 2.1mm HV keepout walls — which is
  exactly the room the POFV dog-bones need. Opportunity cost: the PPK2
  bench procedures above stop working on that variant; only strip after
  the rev-A first-article campaign is done.
- **Quantity is the dominant per-unit lever, no design change needed.**
  ~€78/order is fixed (setup 22.32, feeders 46.75, stencil 7.17, confirm
  fees 1.30); X-Ray (€11.46) is tiered per inspected piece so it shrinks
  per-board with volume but never disappears. At qty 4 assembled that is
  ~€20–23/board of pure overhead. Qty 15–20 takes unit cost from ~€51 to
  ~€20–25 with the design untouched (modulo how POFV scales — see above).

Ruled out, with reasons (don't re-research):

- **SoC alternatives — U1 stays.** Requirements bar (docs/notes.md): hold
  the 14–16µA system deep-sleep floor, sample I2C every 60s in deep sleep
  at ~50nA average without booting the HP core (LP core), 32.768kHz XTAL,
  WiFi. ESP32-C3/C2/ESP8685/ESP8266/BL602/W800 all fail the LP-sampling
  bar (no LP/ULP coprocessor; ESP8266 also ~20µA floor) and save ≤€1.
  Nordic nRF52x has best-in-class sleep and a CPU-off TWIM sampling path
  but is BLE-only — fails WiFi outright. Bare ESP32-C6FH4 saves ~$0.5 and
  costs antenna design + modular RF certification. No wireless part is
  Basic tier, so there is no feeder-fee escape either.
- **Sensor alternatives — U5 stays.** BMP581 is ~$1.44 at LCSC ($2.35–3.03
  through JLC assembly) — already the cheapest pressure-capable part that
  passes the power bar (~0.5µA standby, ~3µC/forced reading). BMP390L costs *more* (~$5) despite the
  existing driver; BMP280 saves pennies and is equally Standard-only.
  SHT40 is the standout if pressure were expendable (80nA, ~2.4µC, ±0.2°C,
  ~$1.3) but its Economy-capability is moot (U1 forces Standard) and it
  drops pressure. AHT20/21 fail per-reading energy (~80ms conversions);
  MCP9808 (~50µC/reading at 0.1°C res), STTS22H (1.75µA standby), LM75B
  (±2°C) all fail the bars. An NTC divider (~$0.01, GPIO-gated → zero
  standby, like the battery divider) passes the power bars trivially but
  is ±0.5–1°C uncalibrated (±0.2–0.3°C with single-point cal), needs C6
  SAR ADC characterisation to reach 0.1°C resolution, and drops pressure.
- **ENIG stays** (€14.84): the locked 0.5mm-pitch LGA and FPC sit at JLC's
  0.20mm HASL clearance floor, and dropping it cannot unlock Economy
  anyway. **X-Ray stays**: mandatory for LGA. **D1, USBLC6, Q6, Y1 stay**:
  charge indication, ESD, reverse-battery survival and timekeeping are
  functionality, and each saves pennies at best.

Net: cheap wins (panel lock + diode swap + production trim) ≈ €15–25/order
with rev-A-class effort; the POFV rev B adds ~€44/order more but is a real
re-layout; quantity halves unit cost on its own.

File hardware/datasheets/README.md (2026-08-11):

# Panel datasheets

Module- and controller-level docs for the e-paper panels the rigs drive. They
live here rather than under `../thermometer-c6/` because the panels are shared
across every rig — FireBeetle, XIAO, the Seeed hat and the custom board. That
board keeps its own parts' datasheets beside it, but **untracked** — including
the SSD1677 doc referenced below, which is not in the repo and has to be fetched
again from Solomon Systech.

| File | Panel | Controller | Rig |
|---|---|---|---|
| `GDEH0154Z90.pdf` | 200x200 tri-colour | SSD1681 | `firebeetle` |
| `GDEY0213M21.pdf` | 212x104 (as GDEW0213M21) | UC8151D | `revA-213m21` bench spare |
| `GDEW029I6FD.pdf` | 296x128 flexible | UC8151D | `xiao-hat` |
| `GDEH0576T81.pdf` | 920x680 | SSD2677 | `revA-bigscreen`, `xiao-bigscreen` |
| `UC8151D.pdf` | — | UC8151D chip-level | the two UC8151 panels above |

No chip-level SSD2677 doc. The SSD1677 datasheet is a relative, not the part, and
taking its pinout for the module's cost a wrong conclusion once (below).

## What they settle: panel readback

Whether a panel can answer the host is a property of its **controller**, not of
any board, so there is no single answer. Established 2026-08-05:

**Every one of these modules exposes a single serial data pin and no SDO** — M21
and I6FD call it `SDIN`, the Z90 and T81 call it `SDA`. Readback, where it
happens, is the controller driving that same pin back.

| Controller | Module data pin | Readback | Identifier |
|---|---|---|---|
| UC8151D | `SDIN`, single | **measured working** on board 2 | `0x70` REV → `LUT_REV` from OTP `0x001` |
| SSD1681 | `SDA`, single; 4-wire read procedure documented | expected working | **`0x38`: 10-byte User ID in OTP** |
| SSD2677 | `SDA`, single | **returns 0 over hardware SPI** (2026-08-11, board 2 + T81); panel capability still untested | unknown |

An earlier version of this table called the T81 doubtful "because the FPC carries
no SDO". That was wrong: `SSD1677.pdf` names `SDI`/`SDO` as separate **chip**
pins in 4-wire mode, but the module bonds a single `SDA` to the FPC, exactly like
the other three. The T81's position is therefore identical to the M21's before it
was probed — one data pin, a module datasheet that calls it an input and
documents no read — and the M21 answered anyway. Untested, not unlikely.

`0x38` matters most: the SSD1681 drives *both* 200x200 panels (the Z90 and the
GDEM0154I61 behind the GDEY0154D67 driver), so a User ID is the only thing that
tells them apart — resolution cannot, and resolution can in any case only
falsify a match, never confirm one.

**The T81 read is now known to return 0 on this rig — but that is a verdict on
the host, not on the panel.** GxEPD2's `_readData()` samples the data line from
software and is documented to work only in bit-banged mode; this build runs
hardware SPI, so nothing samples the line at all. Measured indirectly on
2026-08-11: `_Init_Full` selected the ≤5 °C waveform on a ~26 °C panel, which is
the `temp == 0` path and no other. So the panel has still never been asked; it
has only never been listened to.

That no longer costs anything, which is why the row above stops short of a
board-level conclusion. The waveform consequence is fixed twice over in firmware
— upstream guards the failed read with a 20–30 °C default (worth −48.4 % of panel
busy time, `../../docs/notes.md`), and feeding the BMP581 reading in is strictly
better than any readback: calibrated, ambient rather than a self-heating die, and
write-only so it needs no SPI-mode juggling. What a successful probe would still
buy is a cross-check of the controller's own sensor and an `SSD2677` row here
that says something. It is diagnostics now, not a fix, and it was never a board
change — see [`../thermometer-c6/README.md`](../thermometer-c6/README.md), Rev B
candidates.

## Caveats before trusting any of this

- **Module docs understate it.** GDEW0213M21 Table 3-1 lists only `SDIN` and
  documents write procedures only, yet the panel demonstrably reads back. The
  capability is the chip's; the module vendor does not promise it, so it could
  vary between batches.
- **Nothing transfers between families.** An SSD168x command set floats entirely
  on a UC8151 and vice versa — measured both ways. Every family needs its own
  probe table.
- **These PDFs carry a diagonal "GOOD DISPLAY" watermark** that text extraction
  interleaves into the tables as stray `OD`/`AY`/`PL`/`IS`/`D`/`G` tokens. It
  reads convincingly as a column — it briefly looked like an open-drain pin type
  on the T81's `SDA`. Check any pin attribute against the rendered page.
- **The UC8151 framing is unresolved.** Reads give a stable `0x70` → `01 0e`,
  but the datasheet's `CHIP_REV` is `1101b`, and it notes OTP reads return a
  dummy first packet. Usable as an opaque fingerprint; not as "the revision".

Firmware probe: `display_probe_readback()` in `src/Display.cpp`, behind
`EPD_PROBE`. It reads every command twice, against a pulldown and a pullup — a
floating line follows its pull, a driven one does not, so each run carries its
own control.

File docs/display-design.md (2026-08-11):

# E-Paper Display Design

## Overview

Dashboard-style layout with a large, distance-readable temperature as the primary element,
two trend charts (24-hour Catmull-Rom sparkline and 30-day spline curves), battery/time info,
and a compact debug footer. The layout adapts to all supported display sizes via proportional
zone computation -- no hardcoded coordinates per display.

## Display Sizes

| Panel | Resolution (after rotation) | Layout | Rotation |
|---|---|---|---|
| USE_290_I6FD (2.9") | 296x128 | Landscape | 1 |
| USE_213_M21 (2.13") | 212x104 | Landscape | 1 |
| USE_154_Z90 (1.54" 3-color) | 200x200 | Stacked | 2 |
| USE_154_M09 (1.54") | 200x200 | Stacked | 2 |
| USE_154_GDEY (1.54") | 200x200 | Stacked | 2 |
| USE_576_T81 (5.76") | 920x680 | Stacked | 0 |

## Layout Zones

The layout is determined by aspect ratio: `landscape = (width > height * 1.5)`.

### Landscape (296x128, 212x104)

```
+----------------------------------+------------------------------------------+
|                                  |  23 .....  .  .  .  .     .              |
|         22.3 C                   |                 .  . .  . . .            |
|                                  |  18                                      |
|                                  +------------------------------------------+
|                                  |  25  ~max~     ~avg(dotted)~    ~min~    |
|  [bat] 3.84V          13:42     |  16                                      |
+----------------------------------+------------------------------------------+
| #847 r203 12d w:ULP 4.20V Mar10                                            |
+----------------------------------------------------------------------------+
```

- **Temperature**: left 45% width, full content height
- **Sparkline**: right 55% width, top 62% of content height
- **Monthly chart**: right 55% width, bottom 38% (skipped if content height < 110px)
- **Info bar**: embedded at bottom of temp zone (compact Org_01 font)
- **Footer**: bottom 10px, full width

The temperature font is sized from this zone's dimensions, not picked by a
height threshold — see Typography.

### Stacked (200x200, 920x680)

```
+-------------------------------+
|           22.3 C              |
+-------------------------------+
| 23 .....  .  .  .     .      |
|              .  . . . .       |
| 18                            |
+-------------------------------+
| 25  ~max~  ~avg(dotted)~ ~min~|
| 16                            |
+-------------------------------+
| [bat] 3842mV          13:42  |
+-------------------------------+
| #847 r203 12d w:ULP 4.20V    |
+-------------------------------+
```

Stacked zone proportions (large display, remaining height >= 400px after info + footer):
- **Temperature**: 25%
- **Sparkline**: 42%
- **Monthly chart**: 33% (remainder)
- **Info bar**: 30px fixed
- **Footer**: 24px fixed

Stacked zone proportions (small display, remaining < 400px):
- **Temperature**: 38%
- **Sparkline**: 38%
- **Monthly chart**: 24% (remainder)
- **Info bar**: 22px fixed
- **Footer**: 12px fixed

## Typography

All text is rendered at `setTextSize(1)` -- no integer scaling, no aliasing artifacts.

The temperature font is **generated per panel**, not chosen from this table.
`scripts/generate_font.py` recomputes the point size from the temperature zone's
own dimensions — height constraint fills ~80% of the zone at ~1.4px per pt, width
constraint fits `XX.X C` at ~4.8px per pt, whichever is smaller, capped at 80pt by
`GFXglyph`'s `int8_t yOffset`. It emits `include/generated/font_config.h`, and the
renderer looks the panel up in it via `get_temp_font(w, h)`. Sizes that land on a
library font (9/12/18/24pt) reuse it; the rest are generated. So the point size for
a given panel is whatever the generator last computed — read `font_config.h`, don't
assume. `tools/sim` runs the generator with `--all` so one binary carries every
panel's font.

Everything else comes from this table:

| Element | Font | Condition |
|---|---|---|
| "C" suffix | Same font as temperature digits | always matches the big font |
| Sparkline Y labels | FreeSans12pt | large zones (chart_h >= 100) |
| Sparkline Y labels | TomThumb | small zones |
| Sparkline X labels | FreeSans9pt | large zones |
| Sparkline X labels | TomThumb | small zones |
| Monthly Y labels | FreeSans12pt | large zones (chart_h >= 80) |
| Monthly Y labels | TomThumb | small zones |
| Monthly X labels | FreeSans9pt | large zones |
| Monthly X labels | TomThumb | small zones |
| Info bar (battery, time) | FreeSans12pt | large (w >= 600) |
| Info bar (battery, time) | FreeSans9pt | normal (160 <= w < 600) |
| Info bar (battery, time) | Org_01 | compact (w < 160, landscape embed) |
| Footer | FreeSans12pt | large (zone w >= 600) |
| Footer | Org_01 | small |

## Data Points

### Temperature Zone
- Current reading centered with "C" suffix (same big font as digits, 12px gap)
- Vertically and horizontally centered in zone
- No trend arrow, no delta, no min/max -- just the number

### 24-Hour Sparkline
- Fixed 24h time window, readings plotted at true timestamps
- Catmull-Rom spline interpolation for smooth curves
- Line breaks at gaps > 4 hours
- Y-axis auto-scaled with 15% proportional padding (minimum 0.3), 1 degree C minimum range
- Current reading marked with filled dot (radius 4 large, 2 small)
- Thicker line (2px) on large displays (chart_h >= 100)
- Spline resolution: 16 steps/segment large, 8 medium, 4 small
- Adaptive gridline step: 1 degree when chart_h >= 100 and range <= 8, else 2; on small charts `max(2, range/2)`
- Dotted gridlines (8px spacing large, 5px small)
- X-axis labels at 6-hour wall-clock marks (0h, 6h, 12h, 18h), shown only when chart_h > 30

### 30-Day Monthly Chart
- Two rendering paths based on display width:
  - **Large displays** (chart_w >= 400, e.g. 920x680): hourly resolution showing all 720 HourlyEntry
    points as three Catmull-Rom splines — avg (solid thick), max (arc-length dotted), min (arc-length dotted).
    Daily temperature cycles and transient events are visible.
  - **Small displays** (chart_w < 400): daily summaries derived from hourly data at render time.
    Three splines — avg (solid thick), max (arc-length dotted), min (arc-length dotted) on large zones
    (chart_h >= 60); single avg spline on small zones.
- Arc-length dotted lines use `draw_spline_dotted` (~2px spacing) for envelope (min/max) curves
- Thick lines (2px) on large zones (chart_h >= 80)
- Skipped entirely if zone height < 20px
- Y range: overall min/max with 0.5-degree padding, 1 degree C minimum span
- Adaptive gridline step: same logic as sparkline
- Y labels suppressed near bottom edge to avoid overlap with X-axis date labels
- X-axis date labels every 7th day in "Mar 7" format (month abbreviation + day number)
- Date labels shown only when chart_h > 20 and total_pts > 7

### Info Bar
- Battery icon with proportional fill level (3000-4200mV range, nub on right end)
- Three tiers based on zone width:
  - **Compact** (w < 160, landscape embed): 12px wide icon, voltage as "X.XXV", Org_01 font
  - **Normal** (160 <= w < 600): 18px wide icon, voltage as "NNNNmV", FreeSans9pt
  - **Large** (w >= 600): 28px wide icon, voltage as "NNNNmV", FreeSans12pt
- Date and time right-aligned, longest variant that fits the space left by the
  battery text: `Mon D YYYY  HH:MM`, then `Mon D  HH:MM`, then `HH:MM` alone.
  The date is skipped entirely pre-NTP (year < 2024), so a bogus clock never
  prints a bogus date.
- Icon and text vertically centered in zone
- Low battery: icon and voltage drawn in EPD_RED (falls back to black on non-3-color panels)

### Footer
- Separated from content by 1px horizontal line
- Same field set on every display size. `build_footer_text()` is the source of
  truth — it has gained fields more than once, so read it rather than trusting a
  format string here. In emission order:
  - `#N` -- boot count
  - `rN` -- display refresh count
  - `lpN` -- LP core wake count (always present; structurally 0 on ULP FSM boards,
    which don't populate it)
  - `eN` -- LP error count, omitted when zero
  - `uN` -- ULP reinit count, omitted unless > 1
  - `Nd` or `NdMh` -- uptime in days (hours appended only when non-zero)
  - `w:X` -- wake cause: `ULP`, `TMR`, `USB`, or `?`. An unmapped cause prints the
    raw bitmap as `?<hex>` so a new wake source is identifiable off the panel
  - `mxV.VV` -- max battery voltage ever seen (as `mx%.1fV`)
  - `b27:N` -- bad pin27 count, omitted when zero
  - the git hash of the build
  - first boot date as `MonDD'YY`, omitted until NTP has synced
  - `sN` -- age since the last successful NTP sync (`45m`/`7h`/`21d`), which is how
    a silently failing resync shows up
- Narrow footers clip. `render_status_indicators()` measures the footer up to and
  including the hash, and re-emits the hash as a badge when that already overflows
  the zone — so the build stays identifiable even when the tail is cut. On 200x200
  the line ends around `mx`, which means the date and sync age are **not**
  panel-readable there; don't send a reader to the footer for them.
- FreeSans12pt when the footer zone is >= 600 wide, Org_01 otherwise

## Mock Data

Compile-time flag `MOCK_DISPLAY_DATA` fills history buffers with synthetic data.
Defined in `include/MockData.h` (shared between device and simulator):

- **24h sparkline**: Piecewise linear indoor profile (20 control points) with
  variable reading density -- clustered during morning warmup and evening cooldown,
  sparse during stable daytime periods. Small deterministic noise added.
- **30-day hourly**: 720 HourlyEntry values generated from a gradual spring warming
  profile (+0.08 degrees C/day) with a cold snap (days 12-16), weekend warmth bump,
  realistic ~3 degree C daily ranges. Includes in-progress hour accumulator.
- **DisplayStats**: Pre-filled with boot_count=847, refresh_count=203, 12-day uptime,
  ULP wake cause, 4200mV max battery.

## Architecture

```
include/
  Display.h            -- TempReading, HourlyEntry, DisplayStats structs
  DisplayRenderer.h    -- Layout/Rect structs, render function declarations
  MockData.h           -- Shared mock data generation (device + simulator)

src/
  DisplayRenderer.cpp  -- All rendering logic (shared by device + simulator)
  Display.cpp          -- GxEPD2 display driver wrapper, calls render_dashboard()
  Thermometer.cpp      -- RTC history management, data collection

tools/sim/
  sim_main.cpp         -- Host simulator, renders into a GFXcanvas16
  Makefile             -- Builds render_display binary
  stubs/               -- Host-side shims (Arduino.h/Print.h, the Adafruit bus
                          headers, and a generated/ that pins the rig)
```

`render_dashboard()` in `DisplayRenderer.cpp` is the single entry point. It takes an
`Adafruit_GFX&` reference, computes the layout via `compute_layout()`, then calls each
zone renderer in sequence: `render_temperature`, `render_status_indicators`,
`render_sparkline`, `render_monthly_chart`, `render_info`, `render_footer`. The device
passes the GxEPD2 display object; the simulator passes a GFXcanvas16 — 16-bit so the
tri-color red path is visible. Same rendering code, pixel-perfect output.

Individual zone renderers are also declared in `DisplayRenderer.h` for direct testing.

## RTC Memory Budget

`sizeof(time_t)` is 8 bytes on both ESP32 (Xtensa) and ESP32-C6 (RISC-V), which is
why the sparkline stores its own timestamp rather than a `time_t`.

**TempReading** = `uint32_t` (unix time, good until 2106) + `int16_t`, packed:
- Both platforms: 4 + 2 = 6 bytes per entry — 320 entries in the same 1920
  bytes that 192 entries needed with a `time_t` timestamp.

The sparkline buffer is a linear array (oldest first), not a ring. When full,
`TempHistory.h` drops the oldest point if it's outside the 24h window (the
common case in stable periods); otherwise it drops the interior point with the
smallest Visvalingam triangle area, so noisy periods lose redundant wiggle
detail instead of truncating the chart's 24h span.

**IMPORTANT:** RTC slow memory (8KB at 0x50000000) is shared between `RTC_DATA_ATTR`
variables and the ULP program/data. `ULP_DATA_BASE` must be set past the end of all
`.rtc.data`/`.rtc.force_slow` sections — the post-build script `post_build_check_rtc.py`
verifies this automatically.

**HourlyEntry** = 3 x `int16_t` = 6 bytes (both platforms).

**BMP390LCalib** = 3 x `float` = 12 bytes.

The two buffers dominate and are fixed by their own geometry: `temp_history[320]`
at 6 bytes each is 1920 bytes, `hourly_history[720]` at 6 bytes each is 4320. The
rest is scalars, and there are enough of them now — drift telemetry, crash
forensics, USB-window state — that enumerating them here only produces a total that
disagrees with the binary.

**For the actual figure, read the RTC column of `docs/footprint.md`**: it is measured
from `firmware.elf` per stage and per board, so it cannot silently drift. Adding an
`RTC_DATA_ATTR` variable is not free — it shifts `historical_data` and eats
`ULP_DATA_BASE` headroom, which has run tight on ESP32-E. `post_build_check_rtc.py`
prints the remaining margin on every build; `.claude/rules/rtc-state.md` has the rules
for changing any of it.

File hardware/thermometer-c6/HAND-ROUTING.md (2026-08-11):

# Hand placing & routing workflow (KiCad GUI → generator harvest)

The generated `thermometer-c6.kicad_pcb` is never hand-edited. All GUI work
happens on a copy; results flow back into `generator/pcb_layout.py` and are
re-rendered. Worklist: whatever `verify/drc_summary.py --gate` and
`verify/hand_diff.py` report. (It used to be `out/stragglers.txt`, but that file
is written only by the retired `make route`, and the board has been
0-unconnected since the J4 fanout harvest.)

**Division of labour:** steps 1–2 (and 4's GUI half) are the human part.
Steps 3, 5, 6 and the PLACE mirroring are mechanical — tell Claude which
nets you routed / which refs you moved and where the copy lives (default
`out/hand/`), and it ports everything back, gates, and commits.

## 0. Preconditions

```bash
make check          # must be fully green
make pcb            # fresh render of placement + checked-in routes
```

## 1. Make the working copy

```bash
make hand
```

Open `out/hand/thermometer-c6.kicad_pcb`. Same basenames = the GUI DRC
enforces the real rules (0.2mm netclass clearance, HV 0.3mm, 0.18mm inside
the `fpc-fanout` area, 0.5mm power widths). `out/` is gitignored.

The target copies the `.kicad_dru` along — **do not skip it.** Without it the
GUI, and any `kicad-cli pcb drc` run from that directory, silently drops every
scoped waiver rule and reports violations the real board does not have (68 vs
7, observed 2026-07-20).

It also symlinks `local.3dmodels/` into the copy, so the local STEP models
(MINI-1, USB-C, FPC, JST, both Bosch LGAs, the switch) render in the GUI's 3D
viewer. The board stores model paths as `${KIPRJMOD}/local.3dmodels/…`, and
`KIPRJMOD` resolves to whatever directory holds the `.kicad_pro` — so without
the link those parts show as bare pads in `out/hand/` while looking fine at
the top level.

`make hand` refuses if the existing copy is newer than the generated board,
since that means un-harvested GUI edits; `make hand FORCE=1` discards them.

## 2. Route in the GUI

- Targets: whatever the gate reports unrouted. Ignore GND ratsnest —
  it waits for the M6 pour.
- Route the NE-gate cluster (`EPD_CS`/`EPD_DC`/`EPD_RST`/`EPD_BUSY`/
  `~EPD_VPP`) in one sitting: the five contend for the same gate, partial
  harvests there invalidate each other.
- You may rip and re-route existing copper, but nothing regenerates it: since
  M5 `pcb_routes.py` **is** the copper, so anything you rip has to come back
  through the step 3 harvest. Treat *authored* copper as expensive to move (see
  `verify/net.py NET` — authored islands are listed with their `pcb_layout.py`
  line numbers).

## 3. Harvest tracks/vias back into the generator

Since M5 the whole board is hand-routed and `pcb_routes.py` is the copper
source of truth — harvest wholesale:

```bash
python3 generator/extract_tracks.py out/hand/thermometer-c6.kicad_pcb --all \
    -o generator/pcb_routes.py
python3 generator/pcb.py     # re-render, then gate (step 5)
```

Always use `-o` (atomic write) — **never a shell `>` redirect**, which
truncates `pcb_routes.py` before the harvester's own imports run.
Anonymous nets are renamed to their `~` names automatically (needs
`out/netlist.net`; run `make netlist` once if missing). Per-net mode
(`... NET [NET ...]`, prints entries for pasting) still exists for
surgical work.

## 3.5. Audit unharvested edits

`extract_tracks.py` mirrors only signal copper (GND excluded). Everything
else — placement, GND vias/tracks, silk, copper graphics, outline — is
hand-mirrored and easy to forget. Audit the whole round-trip:

```bash
python3 verify/hand_diff.py            # must exit 0 before the gate
python3 verify/hand_diff.py --apply    # mirror placement + STITCH vias
```

`--apply` writes the moved-footprint `PLACE` tuples and added/removed GND
`STITCH` vias into `pcb_layout.py` (unique line match required, atomic
write), then tells you to regenerate. GND tracks, silk, copper graphics and
signal-copper sync are report-only — harvest them per the report's hints.
hand_diff must exit 0 (fully mirrored) before step 5's gate.

## 4. Placement tweaks (two traps)

- Nothing harvests placement automatically. `hand_diff` catches this — its
  A section reports every moved/rotated/flipped footprint and `--apply`
  writes the `pcb_layout.PLACE` tuple for you. By hand the entries are
  `(x, y, rot[, "B"])` in **board-relative mm, origin (100,100)** — subtract
  100 from each KiCad-shown absolute coordinate; rotation is
  `SetOrientationDegrees` semantics (what the GUI shows).
- Authored TRACKS/VIAS are absolute coordinates and do **not** follow a
  moved component. hand_diff catches this too: its A section WARNs when a
  move orphans authored copper (a TRACKS vertex, VIA or STITCH via) inside
  the old courtyard. Moving anything inside a hand-authored cluster (FPC
  fanout, booster core, NE-gate copper, EPD_VCC spine) orphans that copper
  and it must be re-authored. Cheapest tweaks are in the all-A* west/center
  signal field; the east side is expensive.
- Known negative result: moving C10/R9 does NOT free `XTAL_32K_P` — its box
  is +3V3's authored elbow (PATHFINDER-NOTES Stage-2 acid test).

## 5. Gate every iteration

```bash
make check
python3 verify/hand_diff.py            # exit 0 = every GUI edit mirrored
python3 verify/drc_summary.py --gate   # REAL=0 required
python3 verify/check_pcb.py            # trunk width, keep-out intersects
```

Unconnected items must be GND-only (the M6 pour owns GND). Beware stale
`out/drc.json` — regenerate before reading it. (`make route` is retired:
it aborts on the HAND_ROUTED sentinel.)

## 6. Commit

Commit `pcb_layout.py` + regenerated `pcb_routes.py` + board file together
(one cluster per commit, imperative message). If a pass leaves dangling
authored copper on a *routed* net, the router bypassed your stub — delete it.

Then refresh the working copy from the freshly rendered board (step 1's `cp`
again) so the next GUI session starts from the generator's truth. Do it only
once hand_diff has nothing left to report but differences the harvest is
*meant* to absorb — pcb.py drops copper the GUI left redundant (a segment
lying wholly inside a longer collinear one on the same net/layer) and carries
any generator-side geometry fix you made on top of the harvest, and those two
are the only reasons the round-trip legitimately does not close.

## Debugging a stubborn net

`verify/reach.py NET W out.png` first (flood fill from the seed island —
shows exactly where it is walled in), then `who.py`/`gap.py`/`occupancy.py`
(the `pcb-edit` skill indexes them). Corridor truths live in LAYOUT-PLAN.md's M5
survey; router semantics (seeding, ordering, boxes) in ROUTER-NOTES.md.

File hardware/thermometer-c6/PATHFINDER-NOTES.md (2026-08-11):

# PathFinder experiment — results (branch `pathfinder-experiment`)

Negotiated-congestion router built per LAYOUT-PLAN §5 / the quirky-rabbit plan.
Developed in a worktree; **not merged, not adopted.** Greedy `route.py` is
untouched behaviourally (the refactor is verified byte-identical).

## What was built
- `route.py` refactor (committed): additive `cell_cost` A* hook + `route_one`
  extracted from `route_all`. **Greedy output byte-identical, same 12
  stragglers** — proven safe.
- `verify/drc_summary.py` (committed): text DRC digest; `--gate` classifies
  REAL (clearance/width/hole) vs DEFERRED (dangling/unconnected) vs WAIVED
  (M6 thermal / M7 silk). Baseline board: **REAL=0**.
- `generator/pathfind.py`: negotiated-congestion loop. Two-grid cost model
  (route-exact violation-proximity grid for A* pricing; territory grid for
  real-overlap detection), history, warm start, straggler-priority freeze,
  min-rip cleanup, placement-bottleneck report. `make route-pf`.

## Decisive diagnostic (route.py-exact hard legality)
- Each straggler routed **individually** against *authored copper only* (all 35
  free nets absent): **10 of 11 succeed**; only **XTAL_32K_P fails** — it is
  boxed by *immovable authored* copper (PWR_EN x17.75 column, +3V3 elbow) +
  cap placement. Exactly the LAYOUT-PLAN prediction. → XTAL needs Stage 2
  (movable authored copper) or a placement move; routing alone cannot fix it.
- Each straggler against *authored + the 35 settled nets*: only **1 of 11**
  (VBUS_SENSE) succeeds. → the other 10 are boxed by the *settled free-net
  copper*, i.e. corridor contention, not by each other.

## Stage-1 result (authored copper immovable): does NOT beat greedy
The board is at capacity with authored copper fixed. Every strategy lands at
>= greedy's 12:
- Global soft negotiation (40 iters): over-use plateaus ~13k; cleanup → ~15
  stragglers.
- Straggler-priority freeze: froze 10, free nets can't clear residual (the 10
  were routed simultaneously and overlap each other) → >= 12.
- Sequential-hard priority (stragglers placed first, hard, then free nets):
  only 5 stragglers place mutually-legal; then **6 free-net failures including
  +3V3, ~EPD_VGH, EPD_GDR** (stragglers-first starves the power/HV nets that
  greedy routes first). TOTAL = 12, and a *worse* set (breaks power).

**Conclusion:** with authored copper immovable the corridors cannot carry more
than the current 35 routed nets, regardless of order or negotiation. Each
straggler is routable alone; collectively they and the free nets contend for
the same saturated corridors. The win requires **Stage 2** (demote non-pinned
authored copper to movable — the anchor sweep) and/or **placement** changes
(XTAL's C10/R9 + cap column). Go/no-go criterion (a) "strictly more terminals
than greedy" is **not met** by Stage 1.

## Stage 2 (movable authored copper) — feasibility PROVEN
`--stage2` demotes anchored authored copper (the 28 nets authored AND in
ROUTE_PLAN, minus EPD_VCC) to negotiable; pinned = EPD_VCC's rigid structures +
the 13 pure-authored nets + pads/keepouts. `--anchor A` keeps anchored nets near
their authored geometry (cost A per off-home cell) to preserve intent + damp
thrash.

- **All 12 stragglers, including XTAL_32K_P, route simultaneously at iteration 0**
  (`unrouted=0`). A fully-routed board EXISTS with movable authored copper.
- Acid test: XTAL routes vs *EPD_VCC-pinned-only* and vs *all-except-+3V3*.
  So **XTAL is freed by re-routing +3V3's authored elbow — NOT a placement
  problem** (contra the earlier LAYOUT-PLAN note about moving C10/R9). The caps
  alone don't block it.
- Remaining gap: the iteration-0 solution is complete but *overlapping*;
  legalizing it (separating to DRC-clean) is a solver-convergence problem. The
  soft-negotiation loop reduces overlap slowly; a clean 0-straggler board needs
  either more solver work (better rip-up scheduling / hard-legal RRR) or using
  these now-known-feasible paths to guide manual harvest.

**Bottom line:** M5 IS solvable — the 12 are not individually impossible, they
are corridor-contended, and moving non-pinned authored copper resolves it.

## Legalization attempts — none cleanly converge on this saturated board
The Stage-2 solution is complete but overlapping; three strategies to legalize
it (separate to DRC-clean) all thrash:
1. **Global soft negotiation** (Stage 1 & 2): over-use plateaus (~11-16k cells),
   doesn't reach 0 within a practical iteration budget; ~1min/iter.
2. **Hard-legal rip-up-reroute** (`--rrr`): keeps the committed set mutually
   legal, routing one net at a time and ripping the committed nets it crosses.
   **Diverges** — committed shrinks 35→17, queue grows 11→28, rips climb past
   67. Root cause: a straggler crossing a densely-packed corridor overlaps
   *many* parallel nets at once, so it rips a whole corridor's worth; each
   ripped net, re-routed into the same saturation, rips more. History can't
   outpace the cascade. Tightening the rip cost / cost-cover didn't change the
   trajectory (the saturation, not the tuning, dominates).
3. **Canonical PathFinder** (`--allnets`): reroute EVERY net each iteration in
   fixed order (the textbook convergent method; the hot-subset above is a speed
   optimisation that can stall coordinated shifts). Blocked by **performance** —
   a congestion-priced (soft) A* explores ~7× more nodes than a hard route
   (0.8s vs 0.12s) and reroute-all is ~46 nets/iter, so an iteration is minutes
   and convergence needs dozens. Speed levers added + measured, both greedy-safe
   (defaults preserve byte-identical): `route_one(fallback_mm=)` bounds the
   board-wide fallback search; `astar(hweight=)` weighted A* cuts nodes 3-5×
   (hw 2.0 → soft route 0.15s ≈ hard). Even so, dense reroute-all stays
   multi-minute/iter (many nets fall to the wide fallback once congestion prices
   their old path out).

**Assessment:** the *algorithm* is validated (Stage 2 proves a legal solution
exists; canonical negotiated-congestion is the right convergent method), but a
**practical** auto-legalizer for a board this dense needs a compiled/vectorised
router core (the pure-Python soft A* is the wall) and/or a coordinated multi-net
shift primitive (move a corridor's nets together by a lane). That is a large,
uncertain effort; the new `hweight` / `fallback_mm` knobs are reusable
regardless.

**Pragmatic path** (reliable, uses the proof): targeted manual harvest — author
the specific authored-copper moves the feasibility proof identifies, starting
with re-routing +3V3's elbow to free XTAL (high-confidence 12→11), one cluster
per `make route`, the workflow the NE-gate harvest already used.

## Reproduce

`make route` is retired — it aborts on the `HAND_ROUTED` sentinel. Reproducing
this needs `FORCE_REROUTE=1`, which **overwrites `generator/pcb_routes.py`**,
i.e. destroys the board's copper. Throwaway worktree only.

```
make route                                    # greedy baseline: 12, byte-identical
python3 generator/pathfind.py --iters 40      # Stage 1 (authored immovable)
python3 generator/pathfind.py --stage2 --anchor 0.1 --iters 30   # Stage 2
python3 verify/drc_summary.py --gate
```
Wrap perf-critical runs with `tlpctl launch --profile performance --`.
Diagnostics were run inline (git history / session); the routability probes and
the Stage-2 `unrouted=0` are the load-bearing evidence.

## Freerouting round-trip (2026-07-11) — external router, same 12 stragglers

`generator/freeroute.py` (`make freeroute`) exports a variant board to
Specctra DSN, post-processes it (0.25mm default width; `power` class 0.5mm;
`hv` class 0.3mm clearance; optional `(type fix)` on authored copper), runs
the Freerouting jar batch-mode, imports the `.ses` and DRC-summarizes the
result under the real `.kicad_dru`. KiCad's DSN export carries the antenna
keepout, the sensor via-keepouts and the GND pour (as a plane), so the
constraint fidelity is decent; only the fpc-fanout 0.18mm relaxation and the
per-area width rules are inexpressible in DSN.

Configurations tried (Freerouting 1.9.0, the version reputed to route better
than the 2.x line):

| config | result |
|---|---|
| A: full board, authored fixed | routes NOTHING new — 1.9 batch mode **skips any net containing a fixed wire** (verified: identical DSN ± fix marking flips exactly those nets), and broke EPD_VCC by ripping it |
| B: authored-only board, authored fixed | 15min41s, 31 of ~47 free nets unrouted (fix-skip poisoned all authored-copper nets) |
| A relaxed to 0.18mm clearance everywhere | no change — clearance was not the blocker |
| A all-rippable (best config) | 11.76s, otherwise DRC-clean, but **the exact baseline 12 straggler terminals remain unconnected**; partial stubs/dangling vias left on the knot nets; USB_D− and ~EPD_VPP not attempted at all |
| Freerouting 2.2.4 (any config) | `java.lang.StackOverflowError` even with `-Xss64m` — unbounded recursion on this input; unusable |

**Assessment:** Freerouting's free-angle rip-up, even with authored copper
rippable (Stage-2-level freedom), gives up on the corridor knot in seconds —
its batch rip-up depth is far shallower than what the contention needs, and
it found none of the coordinated moves the Stage-2 proof identifies (e.g. the
+3V3 elbow re-route). Third independent router to stall on the same 12
terminals; nothing worth harvesting (its rework of the routed nets is
free-angle churn with no straggler gain). Reinforces the **targeted manual
harvest** as the pragmatic path.

## Simplification probes (2026-07-11 evening) — where the density actually binds

Three DSN-space experiments quantify what makes the board hard (all Freerouting
1.9, batch, `-mp 100`; DSNs derived from `a.dsn` by script):

- **2.2.5-SNAPSHOT (2026-07-02 build)**: NPE in ShapeTree during fanout pass 3
  (`Storable.compareTo … "this.object" is null`). With 2.2.4's StackOverflow,
  the whole 2.x line is unusable on this input; 1.9 is the only viable jar.
- **No debug header** (`a-noJ5.dsn`: J5 deleted from placement + pins, its
  nets' wiring stripped so they re-route fresh): clears exactly J5's own three
  straggler terminals (EN.J5.3, DBG_IO5, VBUS_SENSE west leg) plus most of the
  west funnel — but the NE-gate cluster (CS/DC/RST/BUSY/VPP), XTAL_32K_P
  (105 wires of thrash before giving up), SCL's last 0.23mm and USB_D− are
  untouched. The header is real load but NOT the bottleneck.
- **Bare board** (`a-bare.dsn`: ALL wiring stripped — placement only, the
  "could FR have routed this board from scratch" test): 29m47s, ~24 signal
  nets unconnected, dominated by the J4/FPC ecosystem (every EPD rail + SPI
  line + the fanout-adjacent HV nets) plus power trunks. **The hand-authored
  copper is load-bearing**: the 0.18mm fanout relaxation is inexpressible in
  DSN, and FR cannot escape the 0.5mm-pitch connector under 0.2/0.3 rules.

**Spacing verdict:** spreading components would not rescue automation — the
two hard chokes are pitch-fixed (J4's 0.5mm FPC fanout; U1's NE castellated
pin gate), not inter-cluster spacing. Density between clusters is what FR
already handles (west funnel cleared once J5's load left).

## Resolution (2026-07-12): M5 closed by complete GUI hand-routing

The user hand-routed the ENTIRE board in the KiCad GUI (all non-GND nets,
DRC-clean, board grown 48×35 → 49×36, ~36% of segments rerouted vs the
autorouted baseline). Every knot the three routers stalled on fell to
interactive rip-up with human judgment. The copper was harvested wholesale
into `generator/pcb_routes.py` (HAND_ROUTED sentinel; `extract_tracks.py
--all -o`); route.py/pathfind.py remain for archaeology and a hypothetical
from-scratch re-route only. As-routed snapshot: [`archive/`](archive/). Follow-on
analysis: `verify/topo.py` + `out/topo/REPORT.md` (pour-damage ranking,
antenna-strip audit, power-via audit).

Also for the record: cluster-scoped Opus agents with the corridor facts DID
make real progress where batch autorouters could not (~EPD_VPP, EN, XTAL —
12→9 in one round, commits b51af3a/1db17ea/1773b61, all since superseded by
the hand routing). The binding lesson stands: on a board this dense the
productive split is human rip-up in the GUI + scripted harvest/gating, not
better autorouting.

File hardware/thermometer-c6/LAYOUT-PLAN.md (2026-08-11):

# thermometer-c6 — PCB layout → JLCPCB order (completed phase; historical)

**Both phases closed.** The PCB was finished and ordered 2026-07-20; the boards
landed 2026-07-29 and board 1 is in service. Kept as the record of how the
layout was planned and what was decided. The live checklist is
[`BRINGUP.md`](BRINGUP.md).

Written as self-contained instructions for a fresh session, which is why it
still reads in the imperative.

## 0. What this is / current state

Custom ESP32-C6-MINI-1 e-paper thermometer board in
`hardware/thermometer-c6/` — replaces the XIAO/FireBeetle dev-board rigs.
1S LiPo + RT9080 LDO tree, P-FET-gated on-board Good-Display EPD booster
(solder-jumper RESE 0.47/2.2/3Ω and L 10µH/47µH), universal 24-pin 0.5mm
FPC for all six owned panels, MCP73831 charger with load-sharing USB-C,
reverse-battery FET, high-side-switched battery divider, BMP581 with
BMP585 alternate footprint (populate exactly one), 32.768kHz crystal,
PPK2 series-measurement break. Design rationale, ESP32-C6 pin map, jumper
tables and bench procedures: **read [`README.md`](README.md) first**. Extra
background:
memory file `project_custom_board.md`, expert-review outcomes in git log
(`d842fee`, `f25903e`).

**Schematic + BOM phase is DONE and verified**: `make check` green = ERC
zero violations at all severities, exported netlist exactly matches
`generator/circuit.py` (named + anonymous `~` nets), 50 hand-written
invariants, footprints resolve, zero label-over-wire/body overlaps
(build-fatal), zero wire crossings, zone frames auto-fit.

**PCB phase is DONE**: layout, routing, GND pour + stitching, silkscreen and
the `make fab` export are all complete (milestone history lives in the git
log; ordering in [`ORDERING.md`](ORDERING.md)). The board is 48×35mm,
2-layer, DRC-clean at full severity, every net routed. M5 closed 2026-07-12 via **complete GUI
hand-routing by the user** (after three autorouters — greedy A*, PathFinder
negotiation, Freerouting — all stalled on the same 12-terminal knot; see
PATHFINDER-NOTES.md). The copper now lives wholesale in
`generator/pcb_routes.py` (HAND_ROUTED sentinel; `make route` refuses to
touch it; as-routed snapshot in [`archive/`](archive/)). Copper edits go
through the GUI round-trip in [`HAND-ROUTING.md`](HAND-ROUTING.md) or direct
polyline edits in `pcb_routes.py`,
gated by DRC (`verify/drc_summary.py --gate` + `verify/check_pcb.py`). The
M5-state sections and corridor surveys below are HISTORICAL archaeology.
The topology-driven simplification (report `out/topo/REPORT.md`, tool
`verify/topo.py`), the GND pour and the fab export are all done.

How this project works (do not break it):
- The `.kicad_sch` is GENERATED. Single source of truth =
  `generator/circuit.py` (components/nets/NC/LCSC) + `generator/layout.py`
  (schematic placement, wires, labels, power symbols, PWR_FLAG anchors).
  Never hand-edit the `.kicad_sch`. After any change: `make check`.
- Schematic changes → also update `verify/invariants.py` when intent
  changes, and README tables.
- Per-zone visual review recipe (200 DPI crops from the PDF):
  `make pdf`, then for a zone with origin (ox,oy) and size (w,h) from
  layout.ZONES:
  `pdftoppm -r 200 -png -x $((int((ox-10)*7.874))) -y ... -W ... -H ...
  out/thermometer-c6.pdf zone` (scale = 200/25.4 px/mm); Read the PNG,
  fix in layout.py, regenerate. Iterate until clean.
- Commits: directly on master, imperative present tense, no prefixes.

Decisions already made by the user (do not re-ask): indoor-only charging
0–45°C (goes on silkscreen), BMP581/585 populate-exactly-one, JP5 10µH
default / JP6 47µH (pair with JP3 2.2Ω for GDEH0576T81), 100mA charge
current, ~400–500mAh pouch, target fab JLCPCB. (Assembly tier: **Standard**, not
economy — ENIG and POFV each disable economy and U1 + U5 are Standard-only
parts. Settled in [`ORDERING.md`](ORDERING.md) §3; the draft above assumed
economy before that was known.)

Deliverables this phase: `thermometer-c6.kicad_pcb`, JLCPCB fab zip
(gerbers+drill), assembly BOM + CPL CSVs, updated README + this file.

## 1. Pre-layout tasks

**All three done.** The XUNPU footprint is committed in `local.pretty/` and
hardware-verified on board 1; the outline came out 48×35mm with R2.2 corners;
the Makefile has `drc` and `fab`.

1. **Draw the XUNPU FPC-05FB-24PH20 footprint** (`local.pretty/`) from the
   XUNPU drawing (LCSC C2856831 datasheet). The schematic currently points
   at the Hirose FH12-24S footprint as a stand-in — pinout identical,
   mechanicals differ. Verify contact orientation supports top/dual contact
   (DESPI-C02 spec §4.5) and pin-1 direction against a physical panel cable.
2. **Decide board outline** — suggest ~45×35mm 2-layer, 1.6mm, ENIG or HASL:
   fit ESP32-C6-MINI-1 antenna overhang on one short edge, FPC + jumpers on
   the opposite edge, USB-C on a long edge. 2× M2 mounting holes minimum.
   Check the MINI-1 antenna keep-out (Espressif HDG: antenna section
   overhangs or has ≥15mm keep-out, no copper any layer under antenna).
3. **Layout approach**: do the PCB interactively in KiCad (Update PCB from
   Schematic). Scripting placement like the schematic is possible via the
   pcbnew API but not worth it for a one-off — keep determinism at the
   schematic/netlist level and gate the PCB with DRC + the checklists below.
   Add to Makefile: `kicad-cli pcb drc --exit-code-violations` and
   `kicad-cli pcb export gerbers/drill/pos`.

## 2. Placement plan (blocks map ~1:1 to schematic zones)

- **EPD booster (zone G) — the only genuinely sensitive block.**
  Boost switching loop (L1/L2 → Q3 drain, Q3 source → RESE legs → GND →
  back to EPD_VCC caps) as tight as possible; C16 pump cap adjacent to the
  switch node; D4/D5/D6 short. RESE legs: the three resistors + jumpers
  right at Q3's source with a short, wide, shared GND return — RESE is a
  current-sense node (keep the jumper copper wide; joint mΩ vs 0.47Ω).
  Storage caps (C17/C18, panel caps) near the FPC pins they serve.
- **FPC connector**: panel caps (C19–C25) directly behind their pins;
  PREVGH/PREVGL are ±20V-class — 0.3mm+ clearance from logic.
- **BMP58x**: both footprints side by side, away from the LDO/charger heat
  (opposite corner from USB), per datasheets: **no vias/traces/mask under
  either sensor**, no copper pour beneath, slot or edge placement helps
  thermal fidelity; BMP585's Ø2.2mm port must map to an enclosure opening.
- **Battery/power (zones A/B/C)**: JST + Q6 + JP1/J2 grouped at board edge;
  MEAS jumper/header accessible with the board mounted. LDO input caps at
  VIN pin; 22µF close. Charger + USB-C grouped; USBLC6 next to the
  connector, D± as a matched-ish short pair (USB FS is forgiving).
- **Divider (zone I)**: 100k/100k + FETs near the ADC pin side of the
  module; keep the sense node short (it is 50k Thevenin).
- **Crystal**: FC-135 + caps tight to GPIO0/1 corner of the module, ground
  guard, away from SPI lines.
- **Test points/jumpers all on ONE face** (probing convenience), TP labels
  on silk.

## 3. Routing rules

Intent, not mechanism. The clearances DRC enforces (0.2mm netclass, not the
0.15 board minimum), the min-width DRU rules, the geometry traps and the
router's ordering semantics are in [`CLAUDE.md`](CLAUDE.md) — that is the operative
reference, and it is loaded automatically.

- 2 layers: top = components + signal, bottom = as-unbroken-as-possible GND
  pour stitched with vias; pour top where free.
- Power widths: VBAT/VSYS/3V3/EPD_VCC ≥ 0.5mm (465mA bursts); booster
  switch node short and modest width (voltage node); RESE return wide.
- EPD SPI: plain 0.25mm, keep away from the booster loop and antenna.
- LP I2C (GPIO6/7): short, away from switching nodes.
- USB D±: short pair, no stubs, reference plane under.
- VBAT_ADC is a 50k Thevenin node: short, and away from the EPD HV nets and
  the switch node.
- No traces under the MINI-1 antenna region, either layer.

### M5 state: 12 stragglers after the NE-gate harvest (2026-07-10)

The NE-gate discovery below is HARVESTED (committed): DBG_TX climbs 45
degrees into its via from the y27.55 slot; VBUS_SENSE lost its fan-in via
entirely (J5.6 is entered from below off a between-the-rows F run its west
leg reaches over the south corridor); SCK, MOSI, EPD_PWR_EN, ~EPD_VDD and
most of XTAL_32K_P are now authored end to end (see the comment blocks in
pcb_layout.py); XTAL_32K_P is boxed in ROUTE_PLAN like BOOT. `make route`
now writes out/stragglers.txt and prints only the delta (fixed/new/re-placed
nets); `verify/net.py NET` dumps one net's authored+routed state.

Structural facts that fell out of the harvest (do not re-derive):
- West-to-east crossings for late signals: the EPD_VCC spine (x21.95,
  y14.45..23.65 + its top via ~y14.15) has exactly two doors -- the
  y12.75..13.65 debug-band latitude (full: TX/RX/IO8 at 0.45 pitch) and the
  y24.3 slot + its single x21.15..21.3 descent lane (MOSI's, authored).
  EPD_PWR_EN therefore crosses UNDER the VBAT wall at y26.1 on B and
  bridges back over it on F, twice (its authored course).
- The east edge carries exactly ONE net (SCK): VBAT's x45.75 B column
  walls B from y4.6 to 28.9, and the J4 pad row + one descent seal F.
  MOSI's J4.14 leg goes through the pocket to the staircase via instead.
- The NE corner notch (between Q1's VSYS yard, VBAT's hook and H1) fits
  one F crossing + one via: SCK's (44.3,4.5).
- ~EPD_VDD never enters the pocket: its C21.1 feed is an all-F authored
  link down x36.65 (between C18 and C21.2), and J4.18 joins over y19.55.
- XTAL_32K_P's C10.1/R9.1 island remains THE straggler of this cluster:
  PWR_EN's forced x17.75 column + the +3V3 elbow (via (20.5,18.05) + diag)
  + the C10/C11 cap column seal every bridge to the Y1 tree that A* or
  authored copper could take (all candidate slots enumerated and dead by
  0.01..0.15mm). Candidates if it must die: move C10+R9 (cascades into
  XTAL_32K_N's authored cell), or PathFinder-class rip-up routing.

Remaining 12: ~EPD_VPP->C22.1, EPD_CS->island@15.0,8.1, EPD_DC->J4.11,
EPD_RST->R17.2 + U1.28, EPD_BUSY->island@40,15.1, USB_D-->U1.17 (its old
x20.35/y8.4 crossing died with SCK's y7.75 band -- needs a fresh course to
U3.6), XTAL_32K_P->island@18.4,20.7 (above), SCL->island@15.9,15.6,
EN->J5.3, DBG_IO5->island@15.0,19.9, VBUS_SENSE->island@14.2,19.9.
The NE gate cluster (CS/DC/RST/BUSY/VPP) is unchanged from before the
harvest; the west-funnel trio (EN.J5.3/IO5/VBUS_SENSE-west) still waits on
the third south-funnel lane. `make route` prints the live list; trust it.

### M5 state: 12 stragglers (historical; superseded by the harvest above)

Since b5dfecf (all committed): the VBUS_SENSE divider moved beside Q1
(R22/R23 at 42.3/43.5, 6.3 -- at the old spot the mid-node was walled on
every side: VBUS fanout on F, D7 + EPD_VCC's rigid Q2.3 channel on B; the
node now exits east on F into the east-edge margin, and the J5.6 leg
routes down the x46.55 B column east of VBAT's leg). The C9/R6 yard is
fully authored -- EN's U1.8 drop + all-F C9.1->R6.2 link at y22.3,
VBUS_SENSE's x14.9 and IO5's x15.5 B descents crossing under it -- because
greedy neighbours (VDIV_EN's Q5.1 diagonal, EN's own sweep, +3V3's R6.1
feed) otherwise squeeze one another out in whichever order they run; see
the yard comment block in pcb_layout.py. VBUS_SENSE routes LAST of the
signals (most-adaptable net; routed earlier its west leg sweeps the
south-edge lanes EN's J5.3 and IO5 need). DBG_TX now runs the y28.1 seam.

New review tooling (verify/, all support the mid-pass obstacle state via
`PCB_NO_ROUTES=1 ... --upto=NET`, which is THE way to debug a straggler:
a net's true obstacle set is authored copper + nets EARLIER in ROUTE_PLAN):
- `reach.py NET W OUT.png [crop] [--seed=N] [--upto=NET]` -- flood-fill
  with A*'s exact move rules from island N; prints REACHED/UNREACHED per
  island and the closest-approach chokepoint. The single most useful tool.
- `probe.py NET W --upto=NET SEED x,y ...` -- per-cell trk/via blockage +
  flood membership (SEED = island index or "x,y,F|B").
- `who.py NET W --upto=NET x,y [radius]` -- every copper element near a
  point with distances and trk/via margins (Chebyshev-correct for
  diagonals).
- `gap.py NET W --upto=NET seedA seedB` -- narrowest gap between two
  islands' flood regions: where one authored bridge would connect them.

Router semantics found this phase (also see CLAUDE.md traps):
- stamp_seg rasterizes DIAGONAL segments as squares: a 45-degree lane
  shadows sqrt(2)x its inflation -- ~0.64mm per side against a 0.25 track,
  ~0.88mm against a via centre. H/V segments stamp exact. Prefer H/V
  authored copper beside via windows.
- A* cannot place a via within Chebyshev 0.8mm of an existing via centre
  or 0.55mm of any hole (stamp_hole). Authored vias bypass route.py and
  answer only to DRC, so an authored 0.8mm pair is fine -- but it pins A*
  out of the whole neighbourhood.
- Re-placement dominos: 0.025mm at one via window can reroute a net into
  a 60mm loop three nets later (+3V3's R6.1 window at (16.1,20.8) -> XTAL
  around the west+south edges -> SDA/EN dead). Diff the villain nets'
  routes between passes; the failure list names victims, not culprits.

**NE-gate discovery (not committed -- next chunk's starting point).** With
(a) DBG_TX climbing 45 degrees straight into its via, no y28.75 row
segment (keeps the y28.5..29.35 under-band open from the neck), and
(b) VBUS_SENSE's fan-in via at (35.17,28.75) + an L-drop entering J5.6
from below (south through the J5.2/J5.4 channel, east between the pin
rows), the router SOLVED six of the hard NE nets in one pass:
- EPD_SCK: via-in-pad (15.9,7.75), B y7.75 east to x24, dodges NORTH of
  the Q2.3 channel via y4.75, joins the y4.1 north-edge lane, F down the
  x47.6 east-edge column into J4.13. (The negative-table y7.75 attempt
  failed because it was AUTHORED straight through the channel longitudes;
  routed, it ducks to y4.75 first.)
- EPD_MOSI: south crossing -- via (20.1,14.55), B x21.3 descent BESIDE the
  C14 spine (0.65 west), east y24.3 between C14 and the VBAT wall, F over
  the pocket, B diagonal to its staircase via (43.4,18.55).
- USB_D+: the east-pad-row strip as designed (vias 15.75/18.4/18.9, B
  y14.3 and y12.1 bands to U3).
- EPD_CS, EPD_DC, ~EPD_VPP, EPD_RST->R17.2 also routed.
Cost in that pass: USB_D- (MOSI's x20.1 F vertical takes its x20.35
column), SDA x3, VDIV_EN->Q5.1, EN x3 -- net 14. The harvest plan is to
author those discovered paths one cluster at a time (SCK first, shifted
so D-'s column survives), re-running the west-side fixes that already
worked once per re-placement wave.

Remaining 12: the six NE-gate terminals (SCK->U1.25, CS->island@15.0,8.1,
DC->J4.11, RST->R17.2 + U1.28, BUSY->island@40.0,15.1), USB_D+->U1.18,
~EPD_VPP->C22.1, SCL->island@15.9,15.6, LED_STATUS->R8.1,
DBG_IO5->island@15.0,19.9, VBUS_SENSE->island@14.2,19.9 (U1.9 leg only).
IO5's and VBUS_SENSE's remaining legs are the same structural problem:
three west-to-pocket crossers (EN's J5.3 sweep is the third) into two
south-edge funnel lanes; the seam/under-band rework above is the intended
third lane.

### M5 state at b5dfecf: 13 stragglers (historical)

The corridor survey below is superseded where noted; the two-corridor
geometry itself still holds. Authored since (all committed): TP7 (33.4,24.7),
TP9 (36.35,10.5) kissing the RESE column, R7 (9.0,6.4), the sensor corner
rot-90 rebuild with C12/C13/C26 out of the picket strip; end-to-end B.Cu
lanes for DBG_TX/RX/IO8 (y12.75..13.65 band under the module, dive cascade
past the +3V3 elbow, descents x30.2/30.65/31.75, pocket floor to the J5
fan-in vias); BOOT's crossing (via x10.3, B.Cu leg onto R7.2); XTAL_32K_N's
U1.13 hop; +3V3's J5.2 feed along the south edge; SCL anchors at U5.2 and
U1.16. `make route` prints the live list; trust it, not this paragraph.

**The rule that fell out of this phase:** an authored lane needs clearance
only against other *authored* copper — routed nets re-place every pass. The
exceptions are routed structures with a single legal window, which are
de-facto rigid: EPD_VCC's Q2.3 escape (the B.Cu channel over TP8 at
~x29.9..30.15 y7.9..9.2 plus its diagonal to R17 — the ROUTE_PLAN comment's
"only escape is north"), EPD_VCC's C14 spine (the x~21.95 B.Cu vertical the
C14 window forces, top via copper down to y14.45 — crossing its longitude
below that evicts EPD_VCC into the pocket as a 0.5mm wall), and EPD_VCC's
authored staircase diagonal (x−y=26.55), which seals J4.12/13/14's stubs
from the NE: approach them only from the SW.

**Pocket floor slots** (0.45 pitch between EPD_PREVGL's HV diagonal and the
via row): 26.15 IO8 / 26.6 kept free for ~EPD_VPP / 27.05 RX / 27.55 TX /
28.1 seam. The five J5 fan-in vias all sit at y28.75, which leaves no
through-lane between the row and VBAT's y29.75 lane (0.45mm gap, a lane
needs 0.65) — this is what still blocks VBUS_SENSE and DBG_IO5.

Remaining 13, with fix directions:

- **VBUS_SENSE ×2, DBG_IO5** — re-stagger the authored J5 fan-in via row:
  the vias are authored geometry; give the VBUS/IO5 vias their own y (longer
  F.Cu drops) so each has a private approach instead of fighting the
  y28.75 line and the TX/IO8 tails.
- **NE gate cluster** (EPD_SCK→U1.25, EPD_CS→island@15.0,8.1, EPD_DC→J4.11,
  EPD_RST→R17.2/U1.28, EPD_BUSY→island@40,15.1, USB_D+→U1.18) — the U1 NE
  gate (x15.3..18, y7.5..10.4) cannot carry MOSI+SCK+CS+DC at once. Needs a
  coherent authored escape set (via-in-pads exist for CS/DC/BUSY; add RST at
  (13.4,8.05) — BOOT's authored crossing already keeps clear of it — and one
  for SCK) plus east lanes that respect the rigid EPD_VCC structures. MOSI
  currently loops the NE successfully; its authored staircase via
  (43.4,18.55) dangles until this is reworked.
- **SCL→island@15.9,15.6** — the west path to the authored U1.16 anchor.
  SDA crosses the module on the F.Cu paddle seam at x14.85; SCL needs a
  parallel seam (paddle pad grid spans x9.1..14.5, y11.25..16.65 in a 3×3;
  the inter-pad F.Cu seams are the candidates, minus TX/RX's B verticals at
  x11.0/11.8 which don't block F).
- **~EPD_VPP→C22.1** — slot 26.6 is reserved but unused; the block is at its
  C22 exit or the J4.19 end. Re-derive with occupancy against the routed
  board.
- **LED_STATUS→R8.1** — the west B.Cu descent died with the debug verticals.
  Candidates: F flank east then around, or move D3/R8 (the step-4
  investigation of what D3's placement costs was never done).

Negative results (each one `make route`; do not repeat):

| change | stragglers | what it broke |
|---|---|---|
| debug nets early in `ROUTE_PLAN` | 20 | `DBG_IO8` takes U1's east flank → `USB_D±`, `XTAL_32K_P`; `EN`→J5.3, `+3V3`→J5.2 |
| authored `L2.1`↔`C14.1` link | 17 | re-seeds `EPD_VCC` → `EPD_CS`, `EPD_DC`, `EN` |
| `EPD_VCC` terminals, L2 before C14 | ≥21 | `DBG_TX`, `EN`×2, `XTAL_32K_P` |
| authored U1 escapes, UART north of the row | 18 | `BOOT`→`SW2` (SW2 sits directly north) |
| debug bands at y16.45..17.35 | 21 | crystal cell (XTAL via halos at y17.55) + SDA/SCL diagonals + CS/DC via displacement |
| debug bands crossing x21.95 below y14.45 | 25 | evicts EPD_VCC's C14 spine → 0.5mm pocket wall → J4 five + TX/RX loop the board edge |
| debug band/descent ending x30.7..31.4 | +5 | evicts ~EPD_VGH's x31.05 weave → F.Cu SE sweep → `VCOM`×2, `VSL`, `VDD`, `PREVGH` |
| authored pocket tails east of x34 | 25 | panel-cap service area starved (`VDD`'s C21 via zone, `VCOM`→C25/TP10) |
| SCK authored: y7.75 band + x32.3 column | 26 | crossed EPD_VCC's Q2.3 channel → `EPD_VCC`×6, `MOSI`, `USB_D-`, `EN`×2, `VBUS` (reverted) |

### M5 corridor survey (historical; U1 escapes and TP7 now done)

Every debug signal (`DBG_TX/RX/IO5/IO8`, `VBUS_SENSE`) has to cross the board
from U1 to J5's authored via row, and only two B.Cu corridors can carry a
bundle. Widths below are free *centres* for a 0.25mm lane, from
`verify/occupancy.py`'s bitmaps; they move only when authored copper moves.

**North corridor — open, 5 lanes.** Walled north by `~SW_10U`'s 45° B.Cu
diagonal and south by `VBAT`'s B.Cu lane at y25.15. It tapers west-to-east as
it follows the diagonal: 8.25mm at x24.5, 3.90mm at x28.0, **2.55mm at its
x29.0 neck** (y22.30..24.85), then the pocket at x31+ opens to 14mm. Enter it
from the north around x22.5..24.75, never from the field. (In practice the
committed debug lanes bypass it via the x30.2..31.75 descents; the corridor
band remains available.)

**The field west of x22.6 is one lane, structurally.** `C14.1` can only be
entered by a via — `~BAT_IN`'s 0.5mm F.Cu lane runs along C14's north edge,
that lane's leg down its west, `C14.2` sits east — and `verify/freespot.py`
says C14 has no other legal window. That via's F.Cu annulus must clear
`~BAT_IN`, so its centre is at y ≥ 23.65; its B.Cu halo then ends at 24.275,
and VBAT's lane starts at 24.575. **0.30mm.** `EPD_VCC`'s spine to `L2.1` and
`C14.1` is load-bearing and lives there; do not try to shorten it (see the
island-seeding rule in [`CLAUDE.md`](CLAUDE.md)).

**South corridor — 4 lanes (TP7 moved).** F.Cu down the **x17.10..19.15**
column (4 lanes now that R7 is gone — the only place a bundle crosses VBAT's
B.Cu wall), vias to B.Cu at y ≥ 28.65 (clear of TP1's pad), east at
y28.50..31.00 under the test-point row, climb at x25..26.5, the neck at
**x28.5 (1.75mm, y26.65..28.40)** between `J2.1`'s through-hole and VBAT's
diagonal, and out into the pocket. EN's J5.3 leg uses it today.

## 4. Silkscreen (required text)

- "CHARGE INDOORS ONLY 0–45°C" near USB-C.
- Battery polarity + at JST (verify against the user's pigtails!).
- Jumper tables abbreviated: JP2 0.47R / JP3 2.2R / JP4 3R "bridge ONE";
  JP5 10µH / JP6 47µH "bridge ONE"; "JP6+JP3 for 5.76in T81".
- J2 = PPK2 (wick JP1); J5 pinout labels; TP names; U5/U6 "fit ONE".
- GIT hash / rev + board name.

## 5. Ordering (JLCPCB)

Fab export is `make fab`: it renders a git-hash+date-stamped standalone
board, runs a full-severity DRC, exports JLCPCB gerbers + drill + CPL + BOM,
zips them, and gates the whole bundle with `verify/check_fab.py`. The order
checklist — board options, stock re-verification, the rotation/polarity
preview walk, and archiving — lives in **[`ORDERING.md`](ORDERING.md)**
(single home; don't duplicate the stock notes here).

## 6. First-article bench checklist (PPK2)

**Superseded by [`BRINGUP.md`](BRINGUP.md)**, which is the checklist that was
actually run and carries the results. This draft is kept for the reasoning
behind each item; where the two disagree, BRINGUP wins. In particular item 1
was done through J1 rather than J2, and item 5's two open questions are both
answered — C29 is populated, and the threshold was re-derived to 3550/3500 mV
from a measured ~300 mV refresh-peak droop, not the ~3.4–3.5 V guessed here.

1. Smoke: bench-supply via J2 (VBAT side), current-limited 50mA, no panel.
2. Sleep floor vs the 15.5–19µA dev-rig baselines; hunt surprises (SS14
   reverse leakage at temperature — swap to PMEG6010 class if hot floor
   drifts; MCP73831 BAT leakage).
3. EPD_VCC ramp with soft-start (R24/C28): scope for rail dip at gate-on;
   panel refresh energy vs DESPI numbers, both RESE/L configs.
4. 32k crystal: confirm oscillation + cold start (freezer test); populate
   R9 10M only if marginal; consider 7pF FC-135 variant if batch-marginal.
5. VBAT_ADC accuracy vs DMM across 3.3–4.2V; decide C29 populate; re-derive
   the firmware shutdown threshold (~3.4–3.5V; 3700mV is a buck-era number).
6. USB: enumerate, charge at 100mA, VBUS_SENSE reads, load-share handover
   (plug/unplug scope on VSYS), no-battery USB operation incl. refresh.
7. Reverse-battery test on a sacrificial JST pigtail (it should just block).
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

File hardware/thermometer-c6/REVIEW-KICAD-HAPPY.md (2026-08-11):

# thermometer-c6 Design Review (kicad-happy)

> Newest review first. **Run 2 (2026-07-20)** re-ran the full suite at commit
> `e567982` after the J3/J4 respin. The original pre-order review (**Run 1**,
> 2026-07-17) is preserved unchanged below.

---

# Run 2 — Incremental Respin Review (2026-07-20)

**Commit:** `e567982` (clean tree, verified) · **Tool:** kicad-happy @ `f765dc0`
(identical to Run 1 — not updated, so results are directly comparable) · **Run
dir:** `out/kicad-happy/2026-07-20_0355` (gitignored) · **Prior run diffed
against:** `2026-07-17_1727` (d609762/7b587b7).
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

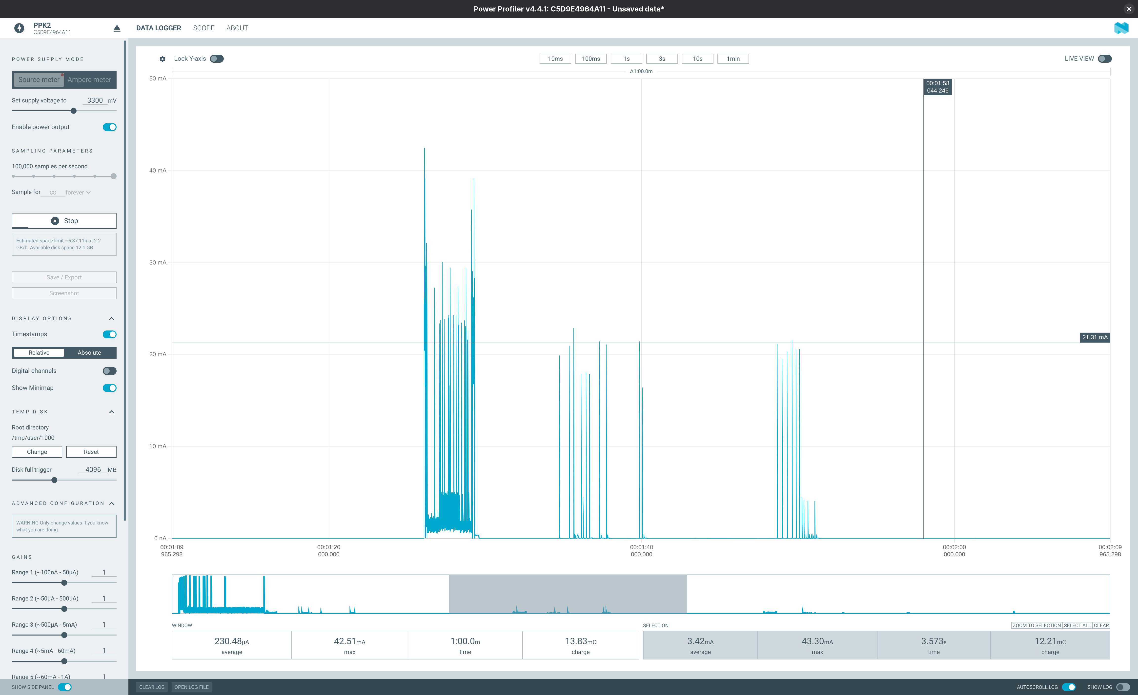
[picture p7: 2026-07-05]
docs/xiao-seeed-esp32c6-seeed-epd-board-GDEW029I6FD-1min-overview.png

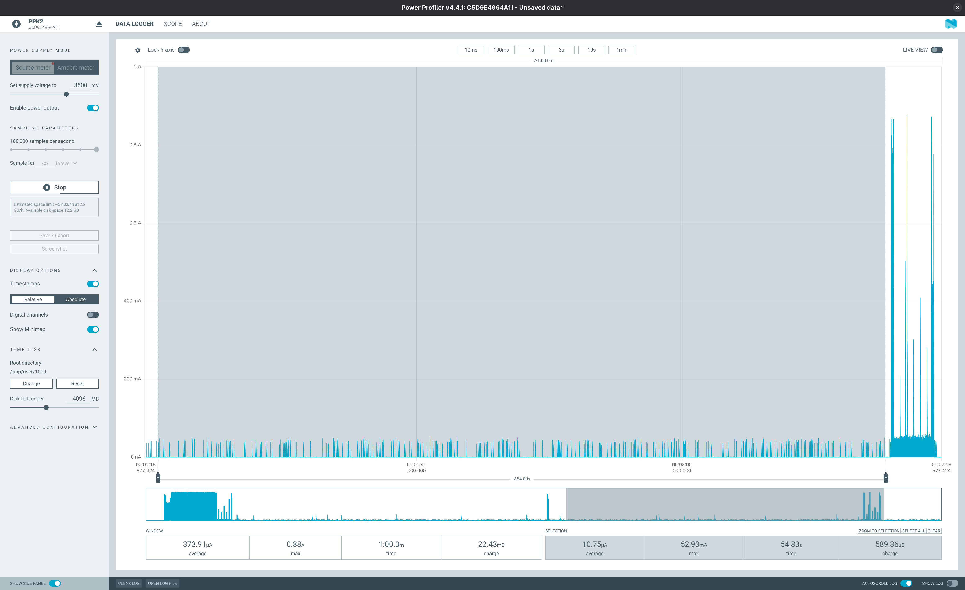
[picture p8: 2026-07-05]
docs/xiao-c6-bat-pads-3V5-sag-and-burst-storm.png

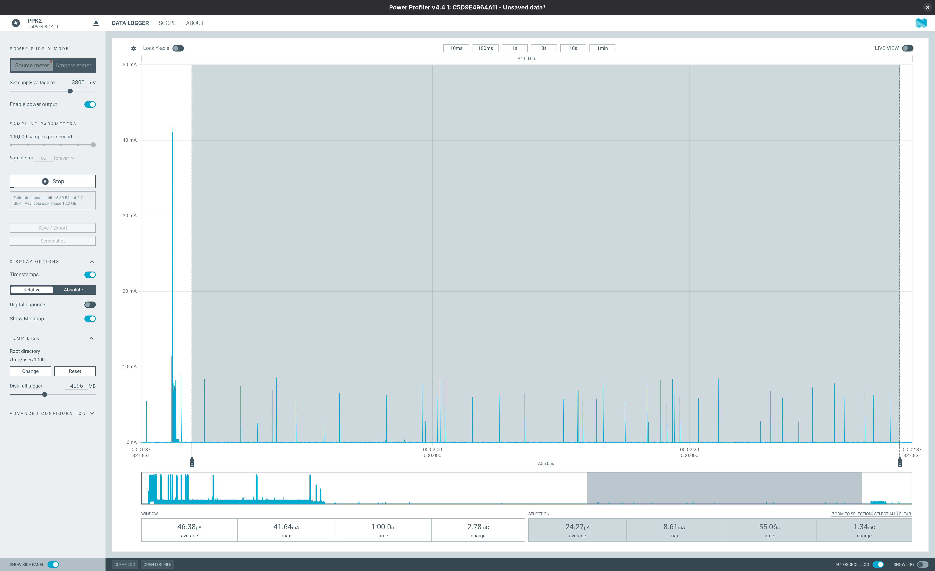
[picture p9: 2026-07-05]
docs/xiao-c6-bat-pads-3V8-floor.png

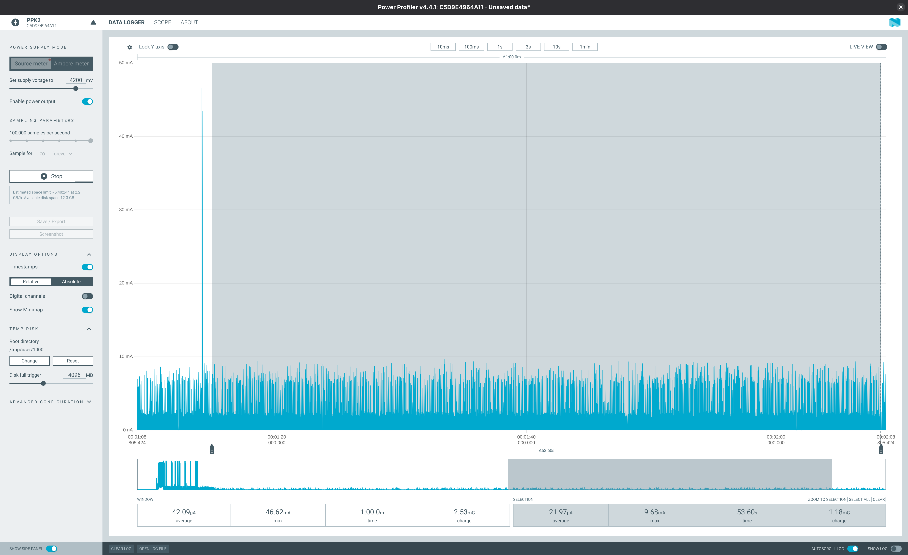
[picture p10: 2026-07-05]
docs/xiao-c6-bat-pads-4V2-floor.png

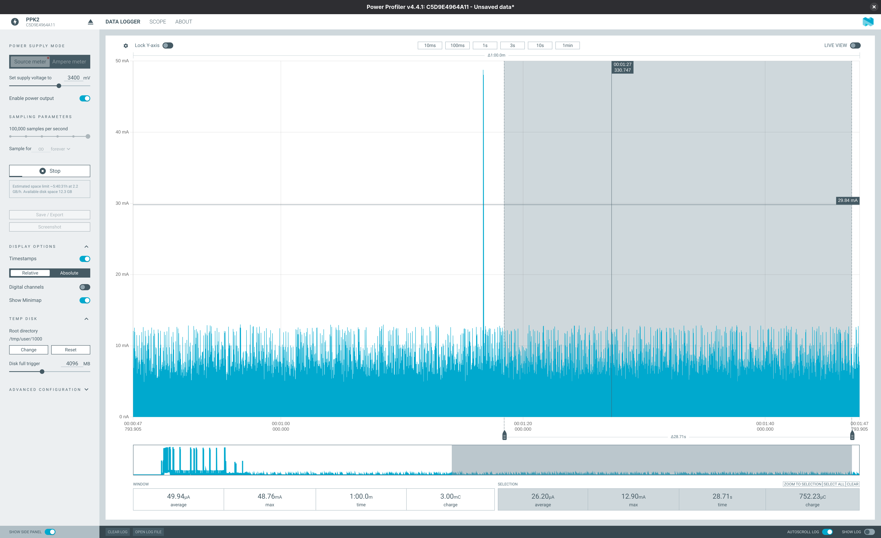
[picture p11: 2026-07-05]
docs/xiao-c6-bat-pads-3V4-continuous-burst.png

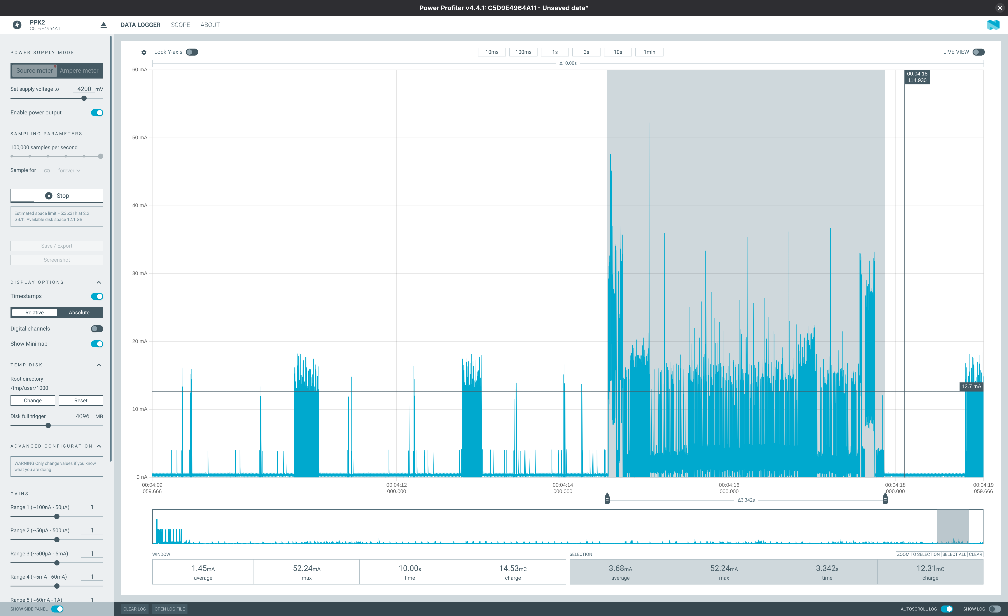
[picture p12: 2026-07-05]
docs/xiao-seeed-esp32c6-seeed-epd-board-GDEW029I6FD-eta9740-4V2-refresh.png

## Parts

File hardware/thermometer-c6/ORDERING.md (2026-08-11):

# Ordering — thermometer-c6 at JLCPCB

Order checklist for the `make fab` bundle. The fab pipeline (render → DRC →
gerbers/drill → CPL/BOM → zip → `verify/check_fab.py`) is the mechanism;
this file is the human procedure around it. Settled fab decisions live in
[`CLAUDE.md`](CLAUDE.md) ("Settled decisions — don't re-ask").

## 1. Generate & upload

- [ ] Check out the ordering commit on a **clean tree** and run `make fab`.
      A dirty tree is refused so the `rev A <hash> <date>` silk stamp names the
      exact committed source (`FAB_FORCE=1` overrides but makes the stamp a lie
      — don't ship one).
- [ ] Upload `out/fab/thermometer-c6-gerbers-<hash>-<date>.zip` (12 files:
      9 gerbers + drill + drill-map + job) to the JLCPCB quote page.

## 2. Board fabrication options

- [ ] Dimensions **48×35mm**, **2 layers**, **1.6mm**, outer copper **1oz**,
      qty **≥5**, solder mask **white** with black silk (deliberate,
      2026-07-20), TG **≥135**.
- [ ] **Surface finish: ENIG.** Chosen for flat pads under the 0.5mm-pitch
      LGA-10 sensor and the 0.5mm FPC — the board sits at JLC's 0.20mm HASL
      clearance floor, so HASL bumps are a risk there.
- [ ] **Via Covering: "Epoxy Filled & Capped" (POFV) — REQUIRED.** The
      via-in-pad escapes depend on it; the 0.3mm via drills are within JLC's
      fill limit.
- [ ] **Mark on PCB: keep "Remove Mark"** (2026 UI: a strict two-way choice
      vs "2D barcode (Serial Number)"; removal is now free and the default —
      the legacy "Order Number (Specify Position)" flow no longer exists).
      Leave the 2D-barcode serial option unset (it needs a reserved 2×10mm
      solid silk square this board doesn't have). The board carries **no
      order-mark token**: JLC support confirmed 2026-07-20 that the
      specify-position service "is already unavailable", so the
      `JLCJLCJLCJLC` back-silk string was deleted from
      `generator/pcb_layout.py` rather than shipped as a stale artifact whose
      only two outcomes were "silently scrubbed" or "printed literally".

## 2b. Confirmations raised for the 2026-07-20 order — all resolved
##     (drafted 2026-07-18; the order was paid 2026-07-20 and the boards landed
##     2026-07-29. Dispositions actually taken: `archive/README.md`, "Known
##     items carried into the order")

- [x] **JLCJLCJLCJLC token under "Remove Mark" — RESOLVED 2026-07-20, token
      DELETED.** Support's answer was that the order-number-at-a-specified-
      position service "is already unavailable", i.e. the token could never do
      its job — leaving it risked only the literal string printing on back
      silk. The `SILK` entry was removed from `generator/pcb_layout.py`; the
      board now ships with no order mark. Nothing left to confirm.
- [x] **J4 GEOMETRY + ROUTING DONE (respin
      2026-07-19, depth corrected 2026-07-20).** Numeric STEP analysis
      (`out/j4-proof/` + the manufacturer drawing
      `datasheets/XUNPU_FPC-05FB-NPH20.pdf`) proved the FPC-05FB's SMT tails
      are at the REAR (actuator) face; the old placement (tails on the east pad
      column) pointed the mouth WEST into the board so the panel cable could
      not mate. J4 is re-placed mouth-EAST, contact-tail/pad column WEST
      (x41.45), footprint pads renumbered so pad 1 = panel circuit 1 stays at
      the NORTH end (circuit.py and the README FPC pin table unchanged).
      Body depth is **5.40** and the mouth sits **4.95mm** east of the pad row
      at x46.40 — 1.60mm inboard of the edge, not flush. (The earlier 6.55/6.6
      figures came from bounding-boxing raw CARTESIAN_POINTs, which include
      LINE/AXIS2_PLACEMENT_3D entities owning no geometry; VERTEX_POINT-only
      gives 5.40, matching the XUNPU drawing exactly — `out/j3-land/` §7.)
      The 24-pin fanout is **re-routed and complete**: 0 unconnected, DRC
      REAL=0 DEFERRED=0 WAIVED=0 at full severity. JLC's preview model showed
      the true orientation all along (tails with actuator); the land pattern was
      the error.
      **Resolved:** the CPL rotation delta stayed `0`/`confidence: low` and was
      covered by Confirm Parts Placement + the DFM gate rather than a preview
      re-walk (`archive/README.md`). J4 pin-1 and mouth-east are now
      hardware-verified on board 1 by continuity (`BRINGUP.md` Phase 0).
- [x] **J3 DATUM + LAND + ROUTING DONE
      (respins 2026-07-19 + 2026-07-20).** The 2026-07-19 pass (`out/j3-proof/`)
      fixed the ORIENTATION: the old rot-0 placement sat the HRO USB-C mouth
      facing SOUTH into the board with the solder tails at the north edge — an
      unpluggable connector, masked by a 3D model mis-registered 180°. J3 was
      re-placed mouth-NORTH (rot 180). The 2026-07-20 pass fixed the DATUM and
      the LAND, and both were wrong:
      * **Datum** (`out/j3-datum/`, datasheet content-stream parse + 1200dpi
        raster + STEP, three methods agreeing to ≤0.005mm). HRO's `5.79` is
        measured **PCB EDGE → ⌀0.60 NPTH post CENTRELINE**, not to the pad row,
        and `4.18` is **shell-slot centre to shell-slot centre**. The front
        shell slot therefore belongs **2.11mm** from the edge, not 0.695 — J3
        was **1.415mm too far north**. Fixed: `PLACE["J3"]` y 1.745 → 3.160.
      * **Land** (`out/j3-land/`, solder foot isolated from the STEP by
        colour + planarity + z=0, measured 0.850mm). The stock KiCad land left
        only **+0.080mm heel** protrusion (below IPC-7351B *Least* 0.25, and
        negative under the tolerance stack) while spending +0.520 on toe. The
        footprint is now a project fork,
        `local:USB_C_Receptacle_HRO_TYPE-C-31-M-12`, with the SMT row shifted
        0.170mm toward the mouth and the NPTH posts 0.65 → 0.60mm (HRO's own
        value — it is what makes the shift legal at the 0.25mm `hole_clearance`
        rule). Result: heel **+0.250** / toe **+0.350**, 100% of the 0.200mm
        heel-fillet zone covered.
      The `edge-clearance-usb-c` DRU rule and its `drc_summary` waiver are
      **DELETED**. They existed only to waive 2 `copper_edge_clearance` errors
      caused by the front shell pad hanging 0.105mm OFF the board edge — a
      symptom of the placement error, not a property of an edge-launch part.
      The edge web is now 1.510mm and full-severity DRC is REAL=0 **WAIVED=0**
      with no J3 exception. `check_pcb.py` §9b now asserts the whole datasheet
      chain (front slot 2.110 from the edge, 4.180 slot span, 3.650 to the NPTH,
      4.925 to the pad row) plus "no shell pad overhangs the edge", so a datum
      regression fails the gate instead of being waived.
      The cut copper is **re-routed and complete** — VBUS, D+ and D− to the
      y7.035 pad row, plus EPD_BUSY, EPD_RST and the VSYS north crossing the
      datum-correct body sits on. Board-wide: 0 unconnected, 0 dangling, DRC
      REAL=0 DEFERRED=0 WAIVED=0 at full severity, schematic parity 0.
      **Preview walked 2026-07-20 — placement CONFIRMED, the render is a JLC
      model artifact, and JLC support confirmed it.** Their 3D preview draws
      the whole J3 model — housing, solder tails AND shell legs together —
      about 1.3mm off the land pattern, so the tails miss the pads and the
      legs miss the holes. That is a rigid-body displacement of the model,
      which is exactly the (0, −1.050, 0) correction `pcb_layout.MODELS_3D`
      already applies to seat this EasyEDA STEP (its origin is the
      front-shell reference, not the land centroid); JLC's viewer applies no
      such correction. Cross-checked by parsing the shipped gerber+drill zip
      directly: front shell slot 2.110 from the edge (HRO 2.1078), rear 6.290
      (6.2794), NPTH 5.760 — and the intended mouth overhang is **0.490** =
      HRO's own 2.600 − 2.110. `check_pcb.py` §9b(b) pins the front slot
      absolutely at 2.110 ±0.05, so a datum error of this size would fail the
      gate by ~25×; it passes.
      **JLC chat 2026-07-20 (agent Oscar), verbatim:** *"you can proceed to
      order … sometimes our system's 3d model have issue causing the part
      misalign … our engineer will manually correct it for you"*, and *"if
      there is any issue our engineer will inform you via email"*. Asked
      whether misalignment has to be flagged explicitly or is caught anyway:
      *"yes it will be pause if issue were found … our engineer will review
      for you first … if there is any issue it will pause and send you email
      … **it will not proceed without your confirmation**"*. So DFM review is
      a hard gate on their side, not an opt-in. That closes the residual
      pick-and-place-origin question as far as a frontline answer can.
      Keep the J3 clause in the PCBA Remark (§3) and Confirm Parts Placement
      = Yes anyway — they cost nothing and leave a paper trail, and the
      remark explicitly asks them NOT to silently adjust the placement.
      **Resolved:** the rotation delta stayed `0`/`confidence: low`, covered by
      Confirm Parts Placement + the DFM gate (`archive/README.md`). The
      X-rays show J3's 0.5mm row resolving individually with no bridging, and
      board 1 enumerates over USB.
- [x] **D1 CPL DELTA RESET (respin 2026-07-20).** The mouth-north J3 USB
      reroute re-placed D1 (**CHG** LED) rot 90 → 180, voiding its 2026-07-18
      LED_0603 preview verification; its CPL delta was reset to 0 (unverified)
      via a `REF_ROTATION_OVERRIDES["D1"]` entry.
      **Resolved without a re-walk:** its `0` was directly preview-verified
      2026-07-18 (cathode cue S), and a rotation delta corrects a
      footprint↔library convention offset, so it is independent of the
      placement change that voided the annotation (`archive/README.md`).
- [ ] **Feeder count:** Feeders Loading fee bills 17 × ~€2.75 while the BOM
      has 16 Extended lines — ask which parts are counted (≈€2.75 delta).

## 3. Assembly options

- [ ] **Standard PCBA, top side only.** Economy is impossible for this board:
      ENIG and POFV each disable it, and U1 (ESP32-C6-MINI-1) + U5 (BMP581)
      are Standard-only parts (verified against a live quote 2026-07-18).
      All assembled parts are on F.Cu by construction (TPs/jumpers are
      copper-only, headers are DNP).
- [ ] Upload `out/fab/thermometer-c6-bom.csv` + `out/fab/thermometer-c6-cpl.csv`.
      **75 placements / 37 BOM lines.**
- [ ] **Confirm Parts Placement: Yes** (first order with this CPL — their
      engineer sends placement imagery for approval before assembly; ~+1 day).
- [ ] **PCBA Remark** — NOT free: filling it in adds an Advanced Options line
      `PCBA remark: "Quote after review"`, excluded from the displayed total
      and charged after their engineer reads it (observed 2026-07-20). Worth
      it for the U5 no-wash instruction. Paste:
      "U5 (BMP581) is a vented barometric pressure sensor — do not wash the
      board, no coating/ink over U5; standard reflow per Bosch guidelines is
      fine. Bake Y1/MSD parts at your discretion if floor life requires.
      J4 (C2856831 FPC-05FB-24PH20): mount with the contact-tail/cable-entry
      side toward the board edge. **Pin 1 is the filled silk dot beside the
      north end of the pad row** — there is no '1' glyph (the footprint marks
      it with an `fp_circle` at local (5.75, −2.6), directly beside pad 1 at
      local x +5.75).
      J3 (C165948 USB-C): please place J3 to the LAND PATTERN, not to the
      model body. In your placement preview the J3 model — body, solder tails
      and shell legs together — renders about 1.3mm off the pads and holes.
      J3 is an edge-launch part, so I do intend a small housing overhang past
      the north board edge; I make it 0.49mm, with every pad and shell slot
      still on the board, and I make the front shell slot 2.110mm from that
      edge per the HRO TYPE-C-31-M-12 drawing. If your DFM check reads any of
      that differently, please tell me before assembly rather than adjusting
      it."
- [ ] Expect one feeder-loading fee (~€2.75) per Extended BOM line — 16 lines
      as of 2026-07-18; only D3 (white C2290) and the 10k (C25744) have Basic
      same-footprint options, the rest have none (audited 2026-07-18). If JLC
      auto-substitutes the 10k with an Extended part (stock), re-match in the
      BOM review page to any in-stock **Basic** 10k 0402 — candidates
      C25744 (1%) / C60490 (1%) / C25531 (±5%; tolerance fine for all seven
      positions — pull-ups, gate series/bleed, and MCP73831 PROG where ±5%
      = 95–105mA). 2026-07-18 all three were out of JLC assembly stock at once
      and every in-stock 10k 0402 was Extended; **2026-07-20 C25744 is back in
      stock**, so the BOM's own part should go through as Basic and this
      contingency likely never fires. If it is gone again by order time, accept
      the auto-substitute (e.g. C174175) and eat the ~€2.75 feeder fee.
      Third-party part browsers show LCSC retail stock, not JLC assembly stock
      — **confirm C25744 in the BOM dialog itself**, which is the only view
      that reflects assembly availability.

## 4. Stock re-verification (before quoting)

Re-check LCSC/JLC stock — several parts run thin:

- [ ] U1 ESP32-C6-MINI-1-N4 **C5736265**
- [ ] Q3 Si1308EDL **C469327** (thin — fallback Si1304BDL clone **C7419947**)
- [ ] 10k **C25744** — back in stock 2026-07-20; re-confirm in the BOM dialog
      (alt **C60490**, then **C25531** ±5% Basic — see §3)
- [ ] **U5 BMP581 C5362283 — if out of stock, populate U6 BMP585 instead:**
      in `generator/circuit.py` set U5 `dnp=True` and U6/C26/C27 `dnp=False`
      (populate-exactly-one — both strap I2C 0x47), `make check`, commit, then
      re-run `make fab`. The BOM/CPL pick up the swap automatically.
      (In stock 2026-07-23: 6,563 pcs on JLC assembly, $2.35–3.03.)

Cost-reduction checks from the 2026-07-22 research (see README "Rev B
candidates → Cost reduction"; tiers/stock re-verified 2026-07-23 against
JLC's part API — the BOM dialog is still ground truth at order time):

- [ ] **Try matching D4–D6 MBR0530 → B5819W C8598** in the BOM dialog —
      confirmed Basic 2026-07-23 (621k stock, $0.029, SOD-123, Vf
      600mV@1A). One Extended feeder line saved *if* feeders are billed
      per Extended line (see below). Leakage/Vf deltas are fine for the
      gated booster.
- [x] **Tiers verified 2026-07-23 (JLC part API)**: C98192, C5204746,
      C469327 (stock 6,445 — thin), C2856831 all **Extended**. No Basic
      4.7µF ≥50V 0805 exists (the only Basic 4.7µF 0805 is 25V — too
      marginal for the ~22V EPD rails); nearest Basic alternative is
      **C440198** 10µF 50V X5R 0805 (2.4M stock) — a candidate line-kill
      needing booster re-validation, see README.
- [ ] **Check the feeder-fee model on the next itemised quote**: JLC's
      live assembly-price page (updated 2025-09-01) documents Standard
      PCBA at **$1.50 per unique line, Basic included** (Economic: $3 per
      Extended line, Basic free) — yet the 2026-07-20 quote billed
      17 × €2.75, which matches the $3/Extended model, not the documented
      one. The "2025-12-19 rate cut" turned out to be a third-party page
      edit, not a JLC announcement. Which model actually bills decides
      whether Basic swaps save feeder money at all — ask support which 17
      parts were counted.
- [ ] **Quote POFV at qty 5/10/20** once, to learn whether the €44.07 is
      flat per order (amortises with volume) or scales — this decides how
      urgent the POFV-free rev B re-route is. Not documented anywhere
      public (2026-07-23: JLC's extra-charges article omits POFV; only
      documented fact is POFV is free on 6–20-layer, paid on 2/4-layer),
      so the quote calculator is the only oracle.
- [x] **X-Ray fee decoded 2026-07-23**: tiered per inspected piece
      ($1.57/pc at 1–10, $0.79 at 11–50, …), identical Economic/Standard;
      €11.46 ≈ 2 parts (U1 shield + U5 LGA) × 4 boards × $1.57. Mandatory
      for LGA/QFN/shield packages — not removable, but it scales with
      quantity rather than being a flat order fee.

## 5. FPC connector warning

- [ ] J4 must be **C2856831 (XUNPU FPC-05FB-24PH20, DUAL contact)**. The
      bottom-contact sibling **C2856805** looks identical in search results and
      does **NOT** work with the panel cable — never substitute.

## 6. Rotation/polarity verification (MANDATORY)

- [ ] In JLC's component-placement preview, walk `out/fab/rotation-checklist.md`
      row by row (22 orientation-critical parts). **The preview is ground
      truth** — the correction table in `generator/fab_cpl.py` is a first guess,
      and the SOT-23 family carries a known community-table conflict.
- [ ] On a mismatch: adjust the part's delta in `fab_cpl.py`, mark the entry
      `verified:`, re-run `make fab`, re-upload the CPL. If **all** parts are
      uniformly rotated or offset, suspect origin handling, not per-part deltas.
- [ ] Top-priority rows: **U5** (rotated LGA is invisible after reflow), **J4**
      pin 1, **U1** antenna WEST, and all FETs.
- [ ] Answer any JLC engineer polarity-confirmation email against the same
      checklist.

## 7. Archive after submitting

- [ ] Copy the exact uploaded zip + CPL + BOM + the ticked
      `rotation-checklist.md` into `archive/order-<YYYY-MM-DD>/`.
- [ ] Append a provenance entry to [`archive/README.md`](archive/README.md):
      commit hash, stamp, JLC order number, and the options chosen (ENIG /
      POFV / order-number position).
- [ ] Commit.

## 8. Quote history

Record every itemised quote here — earlier rounds were only ever remembered as
a bare total (~€205), which made "did that change?" unanswerable.

### 2026-07-20, bundle `87f5d93` — €204.94, qty 5 PCB / 4 assembled

| line | € | note |
|---|---|---|
| **PCB** | **64.49** | |
| — Via Covering (POFV) | 44.07 | the single largest cost on the board |
| — Surface Finish (ENIG) | 14.84 | |
| — Via Plating Method | 2.92 | |
| — Special Offer | 1.75 | |
| — Confirm Production file | 0.91 | |
| **Standard PCBA** | **140.46** | |
| — Components (35 items) | 49.62 | 37 BOM lines, 35 unique parts — see below |
| — Feeders Loading | 46.75 | **= 17 × €2.75 exactly** — the open feeder question |
| — Setup Fee | 22.32 | |
| — X-Ray Inspection | 11.46 | mandatory (U1 shield + U5 LGA); tiered per piece ≈ 2 × 4 × $1.57 |
| — Stencil | 7.17 | |
| — SMT Assembly | 2.32 | |
| — Packaging | 0.43 | |
| — Confirm Parts Placement | 0.39 | wanted — see §3 |
| — Panel / Large Size | 0.00 | |
| **Advanced** | | |
| — Depanel + edge rail | 2.58 | opt-in; advanced options add a build day |
| Build time | 0.00 | PCB 3d, assembly 3–4d (2–3d would be +€43.01) |

Coupon €17.46 applied → €198.94. Weight 527.10g (5 boards + edge rails; JLC
grows the panel to 70×71mm because Standard PCBA needs ≥70mm a side).

**Shipping: the quoted estimate is a lie for this order.** The quote and cart
pages advertise "Global Standard Direct Line" (€1.31 / €9.72), but at
checkout that line is restricted to orders **under $150** — this order is
~€199, so it is not selectable and the real carrier costs more. Budget for
the actual checkout options, not the estimate. Splitting the order to get
under the cap is not worth it: the €22.32 PCBA setup fee is per-order.

**The 35-vs-37 gap is benign — resolved 2026-07-20 in the BOM tab.** JLC
reported "37 parts detected / 37 parts confirmed"; it bills 35 because two
pairs of BOM lines share one LCSC part and get merged: R18/R19/R22/R23/R5
with R20/R21 (both **C25741**), and SW1 with SW2 (both **C318884**). The ⚠
icons on those rows are merge notices, not problems. Checked the one that
would have mattered: R20/R21 are the VBAT_ADC divider and are spec'd 1% —
C25741 is `0402WGF1003TCE`, whose `F` code IS ±1%, so the merge does not
quietly downgrade battery-sense accuracy.

Deltas worth watching next round: the feeder count (17 billed vs 15 Extended
lines counted in the BOM tab 2026-07-20), and whether X-Ray and depanel are
optional.

Settled deliberately 2026-07-20, do not "correct" these: **white** solder
mask (not green) and **lead-free / high-temp** solder paste.

### Import charges — budget them, they are not on JLC's invoice

JLC invoice (2026-07-27): merchandise €209.27 (bare PCB €13.25 + 4×
assembled €49.01) + shipping €20.12 (DHL Express Worldwide, CPT) − coupon
€17.46 = **€211.93 paid**. DHL door bill: **€62.00** = €42.00 TVA (20% of
the €211.93 invoice total — checks exactly) + €20.00 clearance fee ("frais
additionnels de dédouanement", €16.67 + its own TVA). Actual customs duty:
€0 — EU tariff on populated PCBs is zero, so the entire door charge is VAT
plus the courier's fixed fee. **Landed: €273.93 ≈ €68.50 per assembled
board.**

Rule for future orders: anything over €150 gets import VAT collected by the
courier (20% of goods + shipping) plus a ~€15–20 disbursement fee — add
~22–25% to the checkout total to get the landed cost. Sub-€150 orders with
IOSS (LCSC/DigiKey style) prepay VAT at checkout and owe nothing at the
door, which is why small part orders never showed this. Splitting an order
under €150 to dodge the fee still loses: the €22.32 PCBA setup fee is
per-order (see shipping note above).

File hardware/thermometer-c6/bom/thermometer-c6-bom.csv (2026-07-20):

Comment | Designator | Footprint | LCSC Part #
10uF | C1,C14,C3,C7 | Capacitor_SMD:C_0603_1608Metric | C19702
20pF | C10,C11 | Capacitor_SMD:C_0402_1005Metric | C1554
22uF/25V | C2 | Capacitor_SMD:C_0805_2012Metric | C45783
1uF/50V | C21,C22,C25 | Capacitor_SMD:C_0805_2012Metric | C28323
10nF | C28,C29 | Capacitor_SMD:C_0402_1005Metric | C15195
100nF | C12,C13,C15,C4,C8 | Capacitor_SMD:C_0402_1005Metric | C1525
4.7uF/50V | C16,C17,C18,C19,C20,C23,C24,C5,C6 | Capacitor_SMD:C_0805_2012Metric | C98192
1uF | C9 | Capacitor_SMD:C_0402_1005Metric | C52923
CHG red | D1 | LED_SMD:LED_0603_1608Metric | C2286
SS14 | D2 | Diode_SMD:D_SMA | C2480
STATUS white | D3 | LED_SMD:LED_0603_1608Metric | C2290
MBR0530 | D4,D5,D6 | Diode_SMD:D_SOD-123 | C5204746
JST-PH-2 BAT | J1 | Connector_JST:JST_PH_S2B-PH-SM4-TB_1x02-1MP_P2.00mm_Horizontal | C295747
USB-C | J3 | local:USB_C_Receptacle_HRO_TYPE-C-31-M-12 | C165948
EPD FPC24 0.5mm | J4 | local:XUNPU_FPC-05FB-24PH20 | C2856831
10uH SWPA4030S | L1 | Inductor_SMD:L_Sunlord_SWPA4030S | C38117
47uH SWPA4030S | L2 | Inductor_SMD:L_Sunlord_SWPA4030S | C54731
Si1308EDL | Q3 | Package_TO_SOT_SMD:SOT-323_SC-70 | C469327
2N7002 | Q5 | Package_TO_SOT_SMD:SOT-23 | C8545
AO3401A | Q1,Q2,Q4,Q6 | Package_TO_SOT_SMD:SOT-23 | C15127
5.1k | R1,R2 | Resistor_SMD:R_0402_1005Metric | C25905
4.7k | R10,R11 | Resistor_SMD:R_0402_1005Metric | C25900
0.47R 1% | R14 | Resistor_SMD:R_0805_2012Metric | C2930220
2.2R 1% | R15 | Resistor_SMD:R_0805_2012Metric | C17521
3.0R 1% | R16 | Resistor_SMD:R_0805_2012Metric | C17660
100k 1% | R20,R21 | Resistor_SMD:R_0402_1005Metric | C25741
10k | R12,R13,R17,R24,R3,R6,R7 | Resistor_SMD:R_0402_1005Metric | C25744
1k | R4,R8 | Resistor_SMD:R_0402_1005Metric | C11702
100k | R18,R19,R22,R23,R5 | Resistor_SMD:R_0402_1005Metric | C25741
RESET | SW1 | local:SW_TS-1187A | C318884
BOOT | SW2 | local:SW_TS-1187A | C318884
ESP32-C6-MINI-1-N4 | U1 | local:ESP32-C6-MINI-1 | C5736265
RT9080-33GJ5 | U2 | Package_TO_SOT_SMD:TSOT-23-5 | C841192
USBLC6-2SC6 | U3 | Package_TO_SOT_SMD:SOT-23-6 | C7519
MCP73831-2 | U4 | Package_TO_SOT_SMD:SOT-23-5 | C424093
BMP581 | U5 | local:Bosch_LGA-10_2x2mm | C5362283
32.768kHz FC-135 | Y1 | Crystal:Crystal_SMD_3215-2Pin_3.2x1.5mm | C32346

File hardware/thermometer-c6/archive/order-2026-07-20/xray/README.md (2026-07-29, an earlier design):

# JLC first-article X-rays — 2026-07-27

`1.png`–`4.png` as received from JLC (order SMT026072062920). Four frames =
four distinct assembled boards (unique satellite-ball positions and placement
jitter per frame; frame↔board mapping unknowable).
[`annotated/`](annotated/) overlays every
top-side footprint's bounding box, projected from the board file — the
evidence for each part identification. `annotate.py` regenerates them.

## Frame↔board transform (measured, not eyeballed)

Footprint bboxes come from `thermometer-c6.kicad_pcb` via pcbnew (KiCad abs
minus the (100,100) origin). Frames map board-west to image-top:

    col = 1301 − 41.5·y + dx      row = 41.5·x + 307 + dy      [px, mm]

Scale 41.5 px/mm fitted on U5/J3/U1 anchors in `4.png`, then validated by all
~35 in-frame footprints landing on their blobs in all four overlays. Per-frame
offsets (dx,dy) vs `4.png` by normalized cross-correlation on two landmark
templates (crystal + U5 regions; agreement ≤3 px, NCC 0.88–0.98):
`3.png` (+290,+6), `2.png` (−90,+10), `1.png` (+279,−40). Frames pair into
two framings: {4,2} and {3,1} (H2 + the J2 rings enter frame only in {3,1}).

## Findings (all four boards)

| Part | Verdict |
|---|---|
| U5 BMP581 LGA-10 | 10/10 joints wetted, uniform, centered; no bridging |
| U1 MINI-1 | castellations evenly wetted all sides, no bridges, centered; center GND pads unreadable through module internals (fine — no thermal load); the 45°-rotated QFN is the C6 die inside the module |
| J3 USB-C | 12-pin 0.5mm row resolves pin-by-pin, no bridging; 4 shell through-legs filled |
| J1 JST-PH | pins + SM4 tabs wetted |
| SW1/SW2, Y1, L1/L2, U2–U4, Q*, D* | present, on-pad, nothing anomalous |
| U6 / J2 DNP | pads verifiably EMPTY in every frame |
| **J4 FPC-24** | **off-frame in all four images** — nearest edge (x=40.3mm) projects ≥400 px below the frame. The X-rays say nothing about J4; the Phase 0 optical bridge check is its only inspection |

Incidental observations:

- Satellite solder micro-balls (~50–100µm) near U5 on 2–3 boards, at a
  different spot each time → BRINGUP.md Phase 0 loupe item.
- The faint ~0.9mm round blob top-right in `4.png`/`2.png` is NOT on a board:
  it sits at board-relative (x≈−6.1, y≈−2.8)mm — off the NW corner, on the
  panel rail/carrier — and tracks the board across the two framings exactly
  (absent from {3,1} where that spot leaves the frame). Too faint to be
  solder at that diameter.

A correction the overlay pass caught: the clean 0.5mm row first attributed to
J4 is J3's (USB-C also has a 12-pin 0.5mm row; the shell through-legs and
tongue cutouts are the discriminators). X-ray confirms geometry only — it
proves neither LGA electrical contact nor passive values; BRINGUP.md Phases
0–2 remain the acceptance gate.

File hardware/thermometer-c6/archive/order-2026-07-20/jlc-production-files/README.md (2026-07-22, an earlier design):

# JLCPCB production files — order SMT026072062920 / PO 13106315A_Y9

Downloaded from the JLCPCB order page after CAM processing (2026-07-22),
for the rev A `3ed40fe` bundle uploaded 2026-07-20.

- `thermometer-c6-gerbers-3ed40fe-2026-07-20_Y9.zip` — JLC's production
  bundle: their CAM-processed layer files (`ok/` — panelized, Protel-style
  short names), the ODB++ job (`ok/*.tgz`), the order parameter dump
  (`YG/4te.json`, GBK-encoded), and two nested copies of the customer
  upload (`YG/*.zip`) which are **byte-identical** to
  `../thermometer-c6-gerbers-3ed40fe-2026-07-20.zip` (verified per file).
- `smt-preview-*.png` — JLC's panelized 2D assembly renders (top/bottom,
  with and without designator overlay). Render color is JLC's generic
  green; the ordered finish is white mask / black silk (deliberate, see
  ORDERING.md).

Pre-confirmation verification (2026-07-22): upload byte-identity; order
params vs settled decisions (2L FR-4 1.6mm 1oz, ENIG, resin-plugged vias,
white/black, no customer code, SMT QR codes on the breakaway rails only;
panel auto-extended to 70×71mm with 2mm board-to-rail gap — clears the
1.9mm J3 USB overhang); the 9 "Revised" designators (R2-R6, R12, R19,
R20, R22) are engineer placement nudges — part numbers and values match
our BOM exactly, all non-polarized 0402; placement walk of the three
unverified rotation-checklist entries: J3 mouth north over the edge,
J4 mouth flush east / pin 1 north, D1 cathode east (render polarity mark
matches the previously verified D3). Remaining checklist entries carry
their `verified` status from the 2026-07-18 three-pass preview walk
(unchanged CPL deltas).

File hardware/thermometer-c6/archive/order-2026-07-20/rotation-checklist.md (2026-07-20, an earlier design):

# Rotation verification checklist

One row per orientation-critical part (diodes, transistors, ICs, connectors,
switches). The JLCPCB 2D order preview is the **only** ground truth: after
uploading `thermometer-c6-cpl.csv`, compare each part's rendered orientation
against the "Expected orientation" cue below (a top-view compass bearing of the
part's pin-1 / cathode / antenna feature, board WEST = left).

On a mismatch: fix the part's `delta` in `generator/fab_cpl.py` (adjust the
matching `FAB_ROTATIONS` entry or add a `REF_ROTATION_OVERRIDES` key), mark that
entry `verified:` once it matches, re-run `make fab`, and re-upload the CPL. If
*every* part is rotated by the same amount, or shifted by a uniform X/Y offset,
suspect the origin/whole-board setting rather than per-part deltas.

| Ref | Value | LCSC | Footprint | KiCad rot | Delta (confidence) | CPL rot | Expected orientation in JLC preview | preview OK |
|---|---|---|---|---|---|---|---|---|
| D1 | CHG red | C2286 | LED_0603_1608Metric | 180 | +0 (low) | 180 | cathode band EAST | `[ ]` |
| D2 | SS14 | C2480 | D_SMA | 0 | +0 (verified) | 0 | cathode band WEST | `[ ]` |
| D3 | STATUS white | C2290 | LED_0603_1608Metric | 180 | +0 (verified) | 180 | cathode band EAST | `[ ]` |
| D4 | MBR0530 | C5204746 | D_SOD-123 | 90 | +0 (verified) | 90 | cathode band SOUTH | `[ ]` |
| D5 | MBR0530 | C5204746 | D_SOD-123 | 90 | +0 (verified) | 90 | cathode band SOUTH | `[ ]` |
| D6 | MBR0530 | C5204746 | D_SOD-123 | 0 | +0 (verified) | 0 | cathode band WEST | `[ ]` |
| J1 | JST-PH-2 BAT | C295747 | JST_PH_S2B-PH-SM4-TB_1x02-1MP_P2.00mm_Horizontal | 0 | +0 (verified) | 0 | pin 1 at NORTH | `[ ]` |
| J3 | USB-C | C165948 | USB_C_Receptacle_HRO_TYPE-C-31-M-12 | 180 | +0 (low) | 180 | pin A1 at SOUTH-EAST | `[ ]` |
| J4 | EPD FPC24 0.5mm | C2856831 | XUNPU_FPC-05FB-24PH20 | 90 | +0 (low) | 90 | pin 1 at NORTH | `[ ]` |
| Q1 | AO3401A | C15127 | SOT-23 | 90 | +180 (verified) | 270 | pin 1 (G) at SOUTH-WEST | `[ ]` |
| Q2 | AO3401A | C15127 | SOT-23 | 90 | +180 (verified) | 270 | pin 1 (G) at SOUTH-WEST | `[ ]` |
| Q3 | Si1308EDL | C469327 | SOT-323_SC-70 | 270 | +180 (verified) | 90 | pin 1 (G) at NORTH-EAST | `[ ]` |
| Q4 | AO3401A | C15127 | SOT-23 | 90 | +180 (verified) | 270 | pin 1 (G) at SOUTH-WEST | `[ ]` |
| Q5 | 2N7002 | C8545 | SOT-23 | 90 | +180 (verified) | 270 | pin 1 (G) at SOUTH-WEST | `[ ]` |
| Q6 | AO3401A | C15127 | SOT-23 | 90 | +180 (verified) | 270 | pin 1 (G) at SOUTH-WEST | `[ ]` |
| SW1 | RESET | C318884 | SW_TS-1187A | 0 | +0 (verified) | 0 | pin 1 at NORTH-WEST | `[ ]` |
| SW2 | BOOT | C318884 | SW_TS-1187A | 0 | +0 (verified) | 0 | pin 1 at NORTH-WEST | `[ ]` |
| U1 | ESP32-C6-MINI-1-N4 | C5736265 | ESP32-C6-MINI-1 | 90 | +0 (verified) | 90 | antenna overhang WEST edge; pin 1 SOUTH-WEST | `[ ]` |
| U2 | RT9080-33GJ5 | C841192 | TSOT-23-5 | 0 | +270 (verified) | 270 | pin 1 at NORTH-WEST | `[ ]` |
| U3 | USBLC6-2SC6 | C7519 | SOT-23-6 | 0 | +270 (verified) | 270 | pin 1 at NORTH-WEST | `[ ]` |
| U4 | MCP73831-2 | C424093 | SOT-23-5 | 0 | +270 (verified) | 270 | pin 1 at NORTH-WEST | `[ ]` |
| U5 | BMP581 | C5362283 | Bosch_LGA-10_2x2mm | 90 | +0 (verified) | 90 | pin 1 at SOUTH | `[ ]` |

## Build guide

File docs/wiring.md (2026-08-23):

# First complete prototype

- Firebeetle ESP32-E
- Display:
  - DESPI-C02
  - GDEW0213M21
- Sensor:
  - DS18B20-PAR
  - 4.7 kOhm resistance
- Battery:
  - RS Pro 18650 26H Li-ion Battery Pack (2.6 Ah)

| ESP32 | DESPI-C02 |
|---|---|
| 3.3V  | 3.3V |
| GND | GND |
| MOSI  | SDI |
| SCK   | SCK |
| 14/D6 | CS |
| 2/D9  | D/C |
| 25/D2 | RES |
| 26/D3 | BUSY |

| ESP32 | | DS18B20-PAR |
|---|---|---|
| 4/D12 | | DQ (middle pin) |
| 3.3V  | 4.7 kOhm | DQ (middle pin) |
| GND | | GND (left when looking at flat face) |

Assembled first prototype

# BMP390L + ePaper setup (ULP-capable)

- Firebeetle ESP32-E
- Sensor:
  - Fermion: BMP390L Digital Barometric Pressure Sensor (Breakout, SEN0423)
- Display:
  - DESPI-C02 + GDEW0213M21 (or 1.54" Z90c tricolor)

BMP390L is wired to GPIO0/GPIO4 (RTC I2C pins) so the ULP coprocessor
can read the sensor during deep sleep.

| ESP32 | BMP390L breakout |
|---|---|
| 3V3 | 3V3 |
| GND | GND |
| 0/D5 | SDA |
| 4/D12 | SCL |

# BMP58x (BMP581/BMP585) + ePaper setup (ULP-capable)

Drop-in replacement for BMP390L — same pins, same wiring. Only the I2C address
differs (0x47 vs 0x77), so both sensors can coexist on the same bus.

- Sensor:
  - Fermion: BMP581 Digital Barometric Pressure Sensor (SEN0667), or
  - Fermion: BMP585 Digital Barometric Pressure Sensor (SEN0666)

| ESP32 | BMP58x breakout |
|---|---|
| 3V3 | VCC |
| GND | GND |
| 0/D5 | SDA |
| 4/D12 | SCL |

Set `#define USE_BMP58x` in the rig header (`include/rigs/<name>.h`). The LP
core derives `LP_CORE_BMP58X` from the same selector, so there is no second
place to change.

## DESPI-C02 power gate (FDN340P)

The DESPI-C02 adapter board draws ~534 µA quiescent due to its boost converter.
A P-channel MOSFET on the 3.3V line cuts power during deep sleep.

```
3.3V ──────┬──────── FDN340P Source (pin 2)
           │
          10kΩ
           │
13/D7 ─────┴──────── FDN340P Gate (pin 1)

DESPI-C02 3.3V ───── FDN340P Drain (pin 3)
DESPI-C02 GND ────── GND (direct)
```

GPIO LOW → display powered on. GPIO HIGH / high-Z (deep sleep) → display off.

Firebeetle ESP32-E, BMP390L & GDEH0154Z90 (2026)

# Xiao Seed ESP32C6 + BMPxxx

- Xiao Seed ESP32C6
- Sensor:
  - Fermion BMP581
- Display + DESPI-CO2 + FDN340P
- Battery JST-2 PH-2P connectors on BAT - / +
- Current measurement - https://wiki.seeedstudio.com/xiao_esp32c6_getting_started/#reading-battery-voltage

## Sensor

| Xiao ESP32C6 | BMP581 breakout |
|---|---|
| 3V3 | VCC |
| GND | GND |
| LP I2C SDA (MTCK) | SDA |
| LP I2C SCL (MTDO) | SCL |

## Display

D9 (GPIO20) is also SPI MISO — SPI.begin() must be called with MISO=-1 before
GxEPD2 init to avoid the SPI peripheral stealing the D/C pin (e-paper is
write-only so MISO is not needed). Similarly D3 (GPIO21) is SPI SS; passing
SS=-1 prevents it claiming the BUSY pin.

| Xiao ESP32C6 | DESPI-C02 |
|---|---|
| 3.3V | 3.3V |
| GND | GND |
| MOSI/D10 (GP18) | SDI |
| SCK/D8 (GP19) | SCK |
| D6 (GP16) | CS |
| D9 (GP20) | D/C |
| D2 (GP2) | RES |
| D3 (GP21) | BUSY |

D7 (GP17) for the MOSFET Gate

## Battery voltage divider (GPIO-switched)

Seeed documents a 200kΩ/200kΩ (or 220kΩ) always-on divider, but that draws
~10µA continuously — almost doubles the deep sleep floor. A GPIO-switched
divider with an N-channel MOSFET eliminates quiescent draw entirely.

**Components:** 2× 100kΩ resistors + AO3400A (N-channel MOSFET, SOT-23)

```
Bat+ ─── 100kΩ ─── A0 (D0) ─── 100kΩ ─── AO3400A Drain
                                                │
                                             Source ─── GND
                                                │
                                        Gate ←── D1 (GP1)
```

- D1 HIGH → MOSFET on, divider active, A0 reads Vbat/2
- D1 LOW / deep sleep → MOSFET off, zero divider current
- R_source = 50kΩ → ADC settles in ~2µs, minimal averaging needed
- When MOSFET off, A0 floats toward Vbat through 100kΩ; leakage through
  the ADC's ESD clamp is ~(4.2−3.9V)/100kΩ ≈ 3µA — but only through the
  internal protection diode, negligible in practice

**Read sequence:** set D1 HIGH, delayMicroseconds(100), analogRead(A0) a
few times for noise averaging, set D1 LOW. Total on-time <1ms.

**Why 100kΩ, not 1MΩ:** with 1MΩ/1MΩ (R_source = 500kΩ), the ESP32 SAR
ADC sample window (~300ns) is far too short for the RC to settle — readings
are biased low, not just noisy, and averaging doesn't fix bias. 100kΩ/100kΩ
settles in ~2µs which is still longer than the sample window but close enough
that a few back-to-back reads converge. Adding a 100nF buffer cap at A0 would
allow higher resistance values (charges in 5×R_source×100nF) but adds a
component for no real benefit when the divider is switched off during sleep.

## Unused pins

Breakout:
VBUS
D4
D5

Under board:
MTDI
GND
EN
MTMS
3V3
BOOT

Seeed Xiao C6, BMP581 & GDEH0576T81 (2026)

# Seeed ePaper Driver Board for XIAO vs DESPI-C02 (compatibility notes)

Researched 2026-07-04. The Seeed board
([wiki](https://wiki.seeedstudio.com/xiao_eink_expansion_board_v2/), schematic in
`hardware/Seeed ePaper Driver Board for XIAO SCH v1.0.pdf`) is a faithful copy of
Good Display's reference booster, so Good Display panels are what it's implicitly
built for (Seeed's own panels are rebranded GD units).

**Identical to DESPI-C02:** 24-pin 0.5mm FPC with the standard Good Display
pinout, 3.3V logic/supply, same boost circuit down to the recommended parts
(10µH inductor, Si1304BDL MOSFET, MBR0530-class Schottkys — B0540WS on the
Seeed board, 4.7µF/50V boost cap).

**The one real difference — RESE:** DESPI-C02 has a 0.47Ω/3Ω select switch;
the Seeed board has a **fixed 0.47Ω** (R2, no alternate footprint). Good
Display warns a wrong RESE "will cause the e-paper cannot be refreshed"
(in practice a 3Ω panel on 0.47Ω often still refreshes, but with a stressed
booster / degraded image — out of spec). Per the DESPI-C02 spec
(`hardware/DESPI-C02 Connector Board for E-paper Display V1.1.pdf`):

- **0.47Ω (fine on Seeed board):** GDEW/GDEY series (UC81xx-driven), most
  newer panels, four-color panels — e.g. GDEW042T2, GDEW075T7
- **3Ω (mismatched on Seeed board):** mostly older GDEH/GDEM SSD16xx panels —
  GDEH0154D67, GDEH0213B73, GDEH029A1 — plus oddballs GDEW0583T7, GDEW075T8

Naming is not a reliable guide (two GDEW panels need 3Ω) — check the
panel datasheet's peripheral/reference circuit page for the RESE value
before plugging in.

Our panels, against that fixed 0.47Ω:

| Panel | Wants | On the Seeed board |
|---|---|---|
| GDEW029I6FD | 0.47Ω | fine — verified working 2026-07-05, first flash |
| GDEH0154Z90 | 3Ω (GDEH/SSD1681) | mismatched |
| GDEH0576T81 | 2.2Ω + 47µH inductor | out of spec (board is 0.47Ω + 10µH), untested |

**Don't use the JST battery connector.** The board carries an ETA9740 charger
(0.5A) + JST-PH + power switch, and that path was measured and ruled out —
solder the cell to the XIAO's underside BAT pads instead, leave the JST empty
and the switch off (`docs/notes.md`, 2026-07-05). The switch does **not**
isolate the ETA9740 from VDD_5V: its OUT pin is hardwired to the XIAO 5V pin,
so the IC powers up whenever USB is plugged in, whatever the switch position.

The board has no power gate (3V3 is hardwired to the booster and FPC), unlike
the DESPI-C02 which needs one. Measured, it doesn't want one either — its
ungated standby is single-digit µA, not the DESPI's ~534µA.

**Fixed pin mapping** (firmware must match; DESPI-C02 wiring is free-form):

| Signal | XIAO pin |
|---|---|
| RST | D0 |
| CS | D1 |
| BUSY | D2 |
| DC | D3 |
| SCK | D8 |
| MOSI | D10 |

This takes D0/D1, which the C6 battery divider above uses. Nothing ADC-capable
is left on the header — but the **underside pads are**: C6 ADC1 covers
GPIO0–6, so MTMS (GPIO4, ADC1_CH4) and MTDI (GPIO5, ADC1_CH5) are both free
here, since LP I2C sits on the other two pads (MTCK/MTDO = GPIO6/7).

So a battery divider is still possible on this board: sense on the MTDI pad,
AO3400A gate on D4 or D5 (free header pins), wired as the 100k/100k
GPIO-switched divider above. Not built. Firmware thresholds are board-split in
`Thermometer.cpp`; the XIAO's are 3800/3700 mV, finalised by the 2026-07-05
fine sweep — 3.7V is the lowest verified-healthy point and 3.6V is already
inside the buck's sag band.

## What was measured on this board

The 2026-07-04 verification list is closed. All of it — the ETA9740 JST path,
the battery-direct BAT-pads sweep and its buck-dropout regime map, the ungated
booster standby, and the three-way rail/JST/BAT-pads comparison — is in
[`docs/notes.md`](notes.md), 2026-07-05, with the source voltage recorded per
figure. The conclusions that change how you wire the thing are already above.

Two cautions from it worth carrying here:

- **Compare in mJ, not mC.** These three configs meter at different node
  voltages, so charge alone makes the wrong one look cheapest.
- **The buck's usable window ends around 3.6–3.7V**, which is a firmware
  threshold, not a wiring choice. Below it the XIAO's rail sags and wakes
  collapse into brownout storms.

Still open, both on the custom board rather than this one: a cold (~0°C) run
and a refresh on a real cell, which together decide the final shutdown
threshold — [`hardware/thermometer-c6/BRINGUP.md`](../hardware/thermometer-c6/BRINGUP.md)
Phase 3.

Seeed Xiao C6, e-Paper Driver Board, BMP581 & GDEW029I6FD (2026)

# Custom board (thermometer-c6 rev A)

Not covered here — this file is the dev-board prototype wiring. The rev A pin
map, jumper tables and bench procedures live in
[`hardware/thermometer-c6/README.md`](../hardware/thermometer-c6/README.md).

Thermometer C6 rev A board 1 & GDEM0154I61 (2026)

Thermometer C6 rev A boards 2 and 4 & GDEH0576T81 (2026)

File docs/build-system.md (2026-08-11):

# Build system

The tree is a standard ESP-IDF CMake project (`CMakeLists.txt` +
`src/CMakeLists.txt` + `components/`) that PlatformIO drives. Both boards build
`framework = espidf` on the official registry platform (`espressif32 @ ^7.0.1`,
ESP-IDF 6.0.1) — no Arduino framework, no platform fork, no pinned zip URL.
`idf.py -DIDF_TARGET=esp32c6 build` also works: fonts and the GIT_HASH stamp
auto-generate at cmake configure time, so outside PlatformIO the stamp is as of
the last configure rather than the last build.

CLAUDE.md keeps only the rules that destroy data or silently mis-build when
violated. Everything here is the *why* behind them, plus the traps that cost a
session to rediscover.

## libc is pinned to newlib

`CONFIG_LIBC_NEWLIB` is set deliberately. PlatformIO's `ulp.py` doesn't forward
`ADD_PICOLIBC_SPECS` to the LP-core sub-build, so IDF 6's picolibc default breaks
it. Revisit picolibc (~20% smaller binaries) when that's fixed upstream, or when
building exclusively with `idf.py`.

## Board macros

The macro names are Arduino-era leftovers, kept only to avoid churning every
`#if` in the tree; nothing Arduino remains. Where they come from is a rule, in
[`.claude/rules/build.md`](../.claude/rules/build.md).

## Vendored components

`components/gxepd2` and `components/adafruit_gfx` compile against
`components/arduino_shim`, a minimal Arduino API over IDF (GPIO, timing,
Print/Serial, SPIClass on spi_master).

Only the panels a rig header can select are compiled. **Add the panel
`.cpp` to `components/gxepd2/CMakeLists.txt` when enabling a new `USE_*` panel**,
or the link fails with a missing vtable rather than anything that names the panel.

`components/gxepd2/upstream` tracks
[`antoinecellerier/GxEPD2`](https://github.com/antoinecellerier/GxEPD2) branch
`t81-set-lut-temperature`: **stock upstream plus one additive commit** adding
`setTemperature()` to the T81 driver, so the host can choose the waveform LUT
instead of the driver reading a controller temperature it cannot get over
hardware SPI (`docs/notes.md`, 2026-08-11). Nothing else diverges — the 2026-08-11
migration that retired the old three-commit fork stands, and this rebases onto
any future upstream. **To build against stock upstream instead**, check the
submodule out at `origin/master` and pass `-DDISABLE_PANEL_LUT_TEMPERATURE`;
`display_set_lut_temperature()` then compiles to nothing and the panel keeps the
driver's fixed 20..30 °C fallback (verified 2026-08-11).

`components/hulp` (the ESP32-E ULP FSM library) registers empty on other targets.

## sdkconfig

Authored `sdkconfig.defaults` and `sdkconfig.defaults.<target>` are tracked;
generated `sdkconfig.<env>` files are gitignored. CPU is fixed at 80 MHz at build
time.

Worked example of why the authored/generated distinction matters (the rule is in
[`.claude/rules/build.md`](../.claude/rules/build.md)): `CONFIG_RTC_CLK_CAL_CYCLES=3000` on `thermometer_c6`
looks like a tuning decision, but it is the IDF default that follows from
selecting `EXT_CRYS`. Nobody here chose 3000.

## Partition table

Lives in `partitions.csv` (2048KB single app, no OTA; 1920KB `history` data
partition) and is referenced from BOTH `board_build.partitions` (PlatformIO
ignores the sdkconfig partition selection and always generates from this option)
and `CONFIG_PARTITION_TABLE_CUSTOM_FILENAME` (idf.py). Keep them pointing at the
same file.

`history` is at a fixed offset (0x10000) and must stay there. It comes before
`factory` so a future resize grows it upward and leaves written archive content
in place; moving its start orphans years of data. Changing the table relocates the
app, so that one upload must not be interrupted.

## Local artifacts

Everything the tools pull off a device lives under a single gitignored `local/`:

| Directory | Written by | Contents |
|---|---|---|
| `local/sweeps/` | `ppk2.py sweep` | one dir per run: raw captures, `report.md`, `summary.json` |
| `local/archives/` | `history.py backup` | `hist-<board>-<mac>-<date>.bin` partition images |
| `local/captures/` | `ppk2.py live --out/--raw-out`, Power Profiler exports | `ppk-*.csv`, raw bins |
| `local/scratch/` | by hand | ad-hoc bench files |

`tools/artifacts.py` resolves the root from the repo, **not from the CWD**, so an
artifact lands in the same place wherever the tool was launched from. Point
`$THERMO_LOCAL_DIR` at another disk when a sweep won't fit — a full one is a few
hundred MB and `ppk2.py` refuses to start when the target filesystem is short.

Two consequences worth knowing. Sweeps and captures are **cited from the
logbooks by relative path**, so pruning one breaks a doc reference — check
before deleting, and prefer dropping a run's `*.bin` + `.dec*` caches to
deleting the directory, since `report.md` and the `*.json` sidecars carry every
conclusion at 0.05% of the size. And `history.py backup -o` takes whatever path
you type, which is why `hist-*.bin` stays in `.gitignore` as a safety net.

## Header naming

**Never name a project header like an IDF-internal one.** IDF's mbedtls exposes a
private `common.h` that shadowed ours — hence `app_common.h`.

## Generated fonts

`include/generated/` is auto-generated by the font scripts and gitignored. Don't
edit it, and don't reference specific files under it from documentation.

## ULP builds

PlatformIO's espidf builder feeds **every** file in `ulp/` to the active ULP
toolchain. That is why `ulp/lp_core_main.c` is wrapped in `#ifdef __riscv`: on
ESP32-E the FSM pass preprocesses it to nothing, and HULP builds the FSM program
at runtime instead.

The ULP FSM word budget is checked at build time. `scripts/check_ulp_size.py`
preprocesses the program arrays with the real toolchain and fails the build past
`CONFIG_ULP_COPROC_RESERVE_MEM/4` = 128 words (currently 127/128). The runtime
loader also logs the count and degrades to safety-net wakes instead of aborting
if it ever misfits.

On ESP32-E, `CONFIG_ULP_COPROC_RESERVE_MEM=512` preserves the layout
`ULP_DATA_BASE` assumes.

## platformio.ini structure

Why base sections are plain sections rather than `[env:...]` is a rule, in
[`.claude/rules/build.md`](../.claude/rules/build.md). The consequence worth knowing separately: `build_flags`
is not inherited through `extends` the way you would expect, so each env
re-states its own. The comments in `platformio.ini` track which flags that
affects.

## PLATFORMIO_BUILD_FLAGS is part of the project checksum

`.pio/build/project.checksum` covers the environment variable too, not just
`platformio.ini`. Changing `PLATFORMIO_BUILD_FLAGS` between invocations
therefore invalidates the whole tree and PlatformIO **deletes every env's
`.pio/build/<env>` directory**, not only the one being built.

So a finished image does not survive building another env with different flags:

```bash
PLATFORMIO_BUILD_FLAGS="-DPPK2_DEBUG" pio run -e seeed_xiao_esp32c6_epaper_release
pio run -e dfrobot_firebeetle2_esp32e_debug   # <- wipes the C6 image just built
```

This bites hardest between building a measurement image and flashing it, since
the artifacts vanish with no error — the flash just fails on missing files. Pass
the same flags to every env in a batch, or finish the flash before building
anything else.

`scripts/prune_build_cache.py` keeps that cache bounded: SCons never evicts,
and every build pushes a fresh ~11MB `firmware.elf`. It ages entries out after
30 days unused, gated on a stamp file so it walks the cache at most weekly —
3.7µs on a gated build, ~50ms for a real pass over 12k entries. Age is a true
LRU because SCons `utime()`s an entry whenever it retrieves one. It only ever
touches files inside the 2-hex-char shard directories, which is what keeps the
SConsign DB and `config` at the cache root out of reach; deleting the SConsign
would cost every env its build state.

`build_cache_dir` (see `[platformio]`) makes recovering from a wipe cheap —
measured on `dfrobot_firebeetle2_esp32e_debug`, rebuilding a deleted env
directory drops from 110s to 47s with **zero** recompiles, the remainder being
the cmake reconfigure and copying the objects back. It does not stop the wipe,
so the hazard above is unchanged: what vanishes is still gone until rebuilt.

`PLATFORMIO_BUILD_SRC_FLAGS` is the better tool for a bench flag that only
`src/` reads — it keeps the framework objects out of the rebuild. It trips the
same checksum, so it does not avoid the wipe.

## Environments

Each carries a `custom_rig` naming the hardware it is built for, so the env is
the whole selection:

```
env                                            rig              board
dfrobot_firebeetle2_esp32e_debug / _release    firebeetle       ESP32-E (default env)
seeed_xiao_esp32c6_debug / _release            xiao-bigscreen   XIAO C6 + DESPI-C02
seeed_xiao_esp32c6_epaper_debug / _release     xiao-hat         XIAO C6 + Seeed ePaper board
thermometer_c6_debug / _release                revA-bigscreen   custom rev A board
thermometer_c6_bod_probe                       revA-bigscreen   rev A bench probe: brownout
                                                                raised to ~3.27V — never deploy
```

The rev A boards differ only by panel, so they share these envs and the default
suits boards 2-4. **Board 1 wears the 200x200 GDEY and needs
`RIG=revA-smallscreen`** — the one mismatch the rig cross-checks cannot catch,
since both rigs are valid for the env.

`scripts/upload_gate.py` closes it at upload time instead. HistoryStore stamps the
panel it was built for into the `history` partition header, and that partition
survives reflashing — so the gate reads 52 bytes back before writing anything and
refuses to flash a rig whose panel disagrees with what the board last ran. Only
the panel is checked: a wrong sensor or board macro still renders a frame and the
firmware badges it, whereas a wrong panel fails silently because the panel is
what breaks.

It skips itself, out loud, whenever the answer is not decisive — no archive yet,
unreadable header, no port — because a gate that blocks correct uploads gets
switched off. Overrides: `ALLOW_RIG_CHANGE=1` for a deliberate panel swap,
`SKIP_BOARD_CHECK=1` to skip the read entirely. Costs one esptool connect, which
resets the chip; the upload that follows would have anyway.

Testable with no board attached — it decodes a saved archive image and runs every
rig against it:

```bash
python3 scripts/upload_gate.py local/archives/hist-xiao_esp32c6-fffe16-2026-08-05.bin
```

## Rig selection

A rig is one hardware configuration: board + panel + sensor + the flags that
follow (`EPD_POWER_GATE`, `DISABLE_LEDS`). Each lives in a tracked
`include/rigs/<name>.h`; `include/rigs/_template.h` lists the options and the
add-a-rig checklist.

`scripts/pre_build.py` resolves `RIG` from the environment, else the env's
`custom_rig`, and writes `include/generated/rig_config.h` — a fixed-path,
two-line selector. Fixed on purpose: switching rigs changes that file's
*content*, not the project's file list, so the project checksum is undisturbed
and another env's finished `firmware.bin` survives. Varying
`PLATFORMIO_BUILD_FLAGS` instead would delete every env's build directory (see
above), and the LP core would not see the change at all — its sub-build
inherits no `build_flags` and reads the selector by relative include.

`include/generated/git_hash.h` exists for the same reason, and it is the more
expensive lesson: as a `-D` on the global SCons environment the commit hash
reached every ESP-IDF component's compile line, and SCons puts defines in the
build signature. Every commit — and every clean/dirty flip, so the first edit
after a commit and the revert after it — recompiled ~1100 framework objects.
As a header only the three sources that read it rebuild.
`include/git_hash.h` wraps it so `tools/sim` and `tools/hstest`, which pass
their own `-DGIT_HASH`, keep winning.

Each rig header ends in a cross-check that `#error`s when the rig and the env
disagree, so `RIG=firebeetle pio run -e seeed_xiao_esp32c6_debug` fails at
compile time rather than at the panel. `idf.py` needs `-DRIG=<name>` once; the
generated header persists for later bare `idf.py build` runs.

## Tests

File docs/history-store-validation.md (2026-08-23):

# Flash history archive — hardware validation log

What has actually been exercised on hardware for `src/HistoryStore.cpp`, and
how. Append a row per experiment; don't rewrite old ones. Host-only checks live
in `tools/hstest` and are not repeated here.

Rig unless stated otherwise: **FireBeetle 2 ESP32-E + BMP390L + GDEH0154Z90**,
`dfrobot_firebeetle2_esp32e_debug`, `/dev/ttyUSB0`, USB-powered.

Rows before 2026-08-05 record `local-secrets.h` contents because the panel and
sensor were hand-edited there per flash. Since then the env carries its rig
(`custom_rig` in platformio.ini, headers in `include/rigs/`), so naming the env
names the hardware and a rig/env mismatch is a compile error. What still
panic-loops at ~600ms — looking like a huge sleep floor on the PPK2, with a
stale e-paper frame (old GIT_HASH/time) as the tell — is the right env flashed
to the wrong physical board.

**Redact network names** (CLAUDE.md rule): write `<house-ap>`, `<hotspot>` even
when quoting a serial log. RSSI, channel, BSSID and reason codes identify nothing.

## Plan

Device-side steps from the implementation plan. Host-side equivalents already
pass in `make -C tools/hstest`.

| # | Experiment | Why it needs hardware |
|---|---|---|
| 1 | First boot on the new partition table | one-time format over the old app image; ~475 sector erases |
| 2 | Archive accumulates | real ULP wakes, real refresh cadence |
| 3 | `history.py backup` + `dump --csv` | real esptool over the CP2102/CH340 bridge |
| 4 | **Reflash test** | the whole point: history survives `pio run -t upload` |
| 5 | Power-cycle test | RTC gone, restore + `HOURLY_NO_DATA` gap |
| 6 | Cold-clock test | unsynced device records nothing, NOSYNC badge, bounded retries |
| 7 | Transport test | baud actually decisive on this board |
| 8 | `erase_flash` | clean start, no boot loop |
| 9 | PPK2 | append/base/erase costs vs the estimates — **DONE**, see below |

## Measured flash cost — PPK2 confirmed (2026-07-25, ESP32-E)

Full numbers and setup in [`docs/notes.md`](notes.md). Headline: **170.2 ms at 41.94 mA =
7.14 mC** per base snapshot (3300 mV), which is **0.1%** of this rig's
~7.1 C/day at the one-per-day snapshot cadence. Hourly would be 2.4%.

### What the RPO actually is

**One hour, for the hourly archive, and the journal alone delivers it.** An
hourly entry is programmed to flash as its hour finalizes — `journal_append()`
writes immediately, it is not deferred to the flush — so a reflash, panic or
battery pull costs at most the hour in progress. The snapshot cadence does not
enter into it.

The base snapshot covers what the journal does not, and that is a shorter list
than it first appears:

| Data | RPO | Journal-backed? |
|---|---|---|
| Hourly archive | **~1 h** | yes, directly |
| Drift samples | ~1 day (one per resync) | yes, `REC_DRIFT` |
| `resync_interval_s`, `resync_fail_count` | 24 h | no — but both re-derive after one sync |
| 24 h sparkline | 24 h | **no — base only** |
| Restore anchor | 24 h | **no — `history_store_restore()` bails without a valid base** |

So the snapshot is worth keeping for the anchor and the sparkline, not for the
archive. `HS_BASE_MAX_RECORDS = 24` keeps it at about a day. Note the sparkline
gains little from 24 specifically: it is a 24 h window, so a day-old snapshot
restores a chart whose every point has just aged out. Going finer would fix
that and cost proportionally more — not taken, since the sparkline refills
within a day of running.

The cadence used to be an accident: the only non-NTP trigger was a full journal
sector (256 records, 10.7 days), so it was whatever the adaptive resync interval
happened to be — 1 day on this rig only because its −5265 ppm drift pins the
interval at its floor, and up to the 28-day cap on a crystal-equipped board.
That made the board with the *better* clock the one that could not restore.
Cost of owning it there goes from ~0.7 to 7.1 mC/day — still 0.1%.

On-device timing of the flash calls alone, which is what the cadence work was
based on before the PPK2 pass:

| Phase | Time | Note |
|---|---|---|
| erase 2 sectors (8KB) | **104-125 ms** | ~53 ms/sector — set by the flash part, not by CPU speed |
| program 6.4KB payload | **25 ms** | one page-aligned write |
| read back + CRC32 | **7-8 ms** | |
| (marker also brackets) | ~13 ms | CRC32 over the payload + malloc/memcpy |

Writing the payload as three calls (header, RtcHistory, drift block) instead of
one cost **66 ms** rather than 25: the middle write started mid-page, so nearly
every 256-byte page took an extra program cycle. Batching into one page-aligned
write took 21% off the whole snapshot and is simpler code. Estimate before
measuring was 13 ms for this phase — off by 5x.

The estimate that preceded the PPK2 pass was 5.6 mC; actual is 7.14 mC, 27%
low. The assumed **current** was nearly right (40 vs 41.94 mA) — the error was
duration, because the on-device timing covered only the flash calls and not
everything the marker brackets.

Extrapolation from the erase rate: the one-time format is 480 sectors ≈ 26 s
(the log's "~24s" guess holds).

## Clean state (2026-07-25 16:55Z) — ready for the drift collection

Synthetic test data wiped and a plain build installed. Verified:

- `esptool erase_flash`, then `pio run -e dfrobot_firebeetle2_esp32e_debug -t upload`
- running `99390e1`, **no `-dirty`** (tree fully committed), **no PPK2_DEBUG**
  (no selftest line in the boot log), no `HISTORY_BASE_EVERY_WAKE`
- archive: `0 hourly, 1 sparkline, 0 drift`, base seq 1 at cursor 0x000000
- drift block at defaults: `resync_interval_s 86400`, `ppm_hist` all zero,
  `drift_ppm_count 0`, `last_sync_time` from a real NTP sync on this boot

Repeat that recipe if the board ever needs resetting again — anything injected
by `hstest --inject` must be erased before a real measurement run, or the
fabricated drift sample joins the retained ring and the first genuine
measurement is computed against an invented `last_sync_time`.

Rig: `firebeetle` (Z90 + BMP390L). This run predates `custom_rig`, so at the time
it was selected by hand-editing `include/local-secrets.h`.

## When the archive stops recording

The store degrades rather than panicking a battery device, so nothing else on
screen changes — the device keeps measuring, charting and refreshing perfectly
while every hour it should have kept is lost for good. The `! NOARCH` badge is
the only signal that reaches the panel; `DISABLE_SERIAL` removes the log line
from release builds.

| Badge | Meaning | What to do |
|---|---|---|
| `! NOARCH fmt<N>` | on-flash format N, this firmware speaks another | `history.py backup --full`, then `esptool erase_flash` and reflash |
| `! NOARCH nopart` | no `history` partition — device is on an old table | reflash; the upload rewrites the partition table |
| `! NOARCH io` | an erase or write failed | suspect the flash part; back up if it still reads |

Rendered by `tools/sim` as `mock_*_noarch.png`. It is ranked ahead of the crash
badge deliberately: a crash's payload is already saved to the coredump
partition and does not decay, whereas this condition is still destroying data
every hour it goes unnoticed.

## Known cosmetic issue

`store created` in the header is stamped during `store_format()`, which runs in
`setup()` before the first NTP sync, so on a fresh device it is an epoch-zero
value. The header sector is written once and never rewritten, so there is
nowhere to backfill it. `history.py` prints "(before first NTP sync)" rather
than a 1970 date; not worth a format change.

## Observations

| # | Date | Result | Notes |
|---|---|---|---|
| 1 | 2026-07-25 | **PASS** | Device was on the old table (`factory` 0x10000/3968K, no `history`), confirmed by `esptool read_flash 0x8000`. Upload wrote the app to its new home at 0x1f0000 and the screen came up on `b10cd29` (was `95c7b04-dirty`), so the relocation is real and the panel refreshed normally. First boot then formatted the region and wrote `base snapshot seq 1 (0 hourly, 1 sparkline, cursor 0x000010)`. The format log itself was missed — serial capture started mid-boot — so the ~475-erase timing is still unmeasured. |
| 3 | 2026-07-25 | **PASS** | `history.py backup` over the CH340 bridge at 921600. Read the right identity off the device: `firebeetle2_esp32e c4:5b:be:8c:4d:b8 (GDEH0154Z90/BMP390L)`, build `b10cd29`. Incremental read did its job — **24576 bytes, not 1920KB**. |
| 2 | 2026-07-25 | **PARTIAL** | Sparkline records accumulate: 1 → 3 → 6 → 8 over ~7 min of consecutive backups. That is the refresh path (one record per display refresh, on \|Δtemp\| ≥ 0.1°C), not the hourly one — ambient was genuinely ~28.5°C with the sensor 15cm off-board, so this is real noise driving real refreshes, not a tethered-board artifact. `0 hourly` throughout, correctly: the first hourly entry needs a clock-hour boundary. **Hourly accumulation still unverified.** |
| 4 | 2026-07-25 | **PASS** | The one that matters. Made airtight rather than inferred: `esptool ... --after no_reset write_flash 0x1000/0x8000/0x1f0000`, then the reset pulsed by hand while already capturing, so the log starts at byte zero of the new image's first boot. Result: `RTC history version mismatch — resetting history` / `History restored: 0 hourly, 8 sparkline (base seq 1, +0/7 replayed)`. An earlier capture of a plain `pio run -t upload` had missed the line by starting mid-boot — the restore had worked then too. |
| 5 | 2026-07-25 | **PARTIAL** | A DTR/RTS reset presents as `rst:0x1 (POWERON_RESET)` and wipes RTC (boot_count back to 1), and restore repopulated 6 sparkline points spanning two flashes. So restore-after-RTC-loss is proven. The `HOURLY_NO_DATA` gap fill is **not** yet exercised — it needs hourly entries to exist first. |
| 7 | 2026-07-25 | **PARTIAL** | 921600 works on this bridge (CH340, `1a86:` by-id, not the CP2102 the docs assume) for both `read_flash` and `write_flash`. The 115200-vs-921600 timing claim is unmeasured, and the incremental read makes it mostly moot here. |
| 2 | 2026-07-25 | **PASS** | Hourly path confirmed once the clock crossed 15:00Z: `1 hourly` covering `2026-07-25 14:00:00Z` at 29.0/29.2/29.1 °C — min, max and avg all distinct, so the accumulator works, not just the append. |
| — | 2026-07-25 | **PASS** | Format 2 (hourly-only journaling) re-formats on first boot as intended, and restores with the sparkline sourced wholly from the base: `History restored: 0 hourly (+0 replayed), 9 sparkline, base seq 13`. |
| — | 2026-07-25 | **PASS** | **Synthetic archive injection.** `hstest --inject <size> <mac> <now> <file>` builds a full 1920KB image with the *real* store code — so it cannot disagree with what the firmware writes — filled from `MockData.h` and stamped with this board's MAC. `history.py restore` accepted it (MAC matched), and the device came up with `History restored: 720 hourly (+0 replayed), 62 sparkline, base seq 1` and refreshed. Reading it back gives 720 rows spanning 2026-06-25 15:00Z .. 2026-07-25 14:00Z with sane values. This is how to get a populated 30-day chart without waiting 30 days. |
| — | 2026-07-25 | **PASS** | **30-day chart confirmed against the injected series.** On-screen dip reported at "around July 8"; the coldest day in the injected data is 2026-07-08 at 19.3°C daily avg. Daily aggregates (what the 200x200 panel plots) run 16.8-26.1°C, consistent with the observed 24°C gridline. |
| — | 2026-07-25 | **PASS** | **24h sparkline confirmed via a ramp.** `--inject ... ramp` replaces the sparkline with a 10.0→30.0°C diagonal at fixed 30min spacing — a shape neither the room nor `MockData.h` produces. Restored as 48 points (100→300 x10, 1800s apart) and observed as a clean diagonal on the panel. Settles that the 24h chart is fed from flash, not from anything compiled in. |
| — | 2026-07-25 | note | Two earlier observations on the mock sparkline were **not** faults: the flat stretch "up to 0h" is `MockData.h`'s deliberate 6h flat carry-in (a spline regression case; 21:41Z = 23:41 CEST, hence 0h on screen), and >1 point/hour is correct — the 24h chart records per display refresh, only the 30-day chart is hourly. |
| — | 2026-07-25 | **PASS** | **Restore keeps its anchor and marks the outage it spans** (`1f6552d`). `hstest --inject 1966080 <mac> $(date +%s)-259200` built a 30-day archive whose newest hour is 2026-07-22 17:00Z; `history.py restore` took it and the board booted `f050bfc` with `History restored: 720 hourly (+0 replayed), 62 sparkline, base seq 1`, NTP-syncing at 2026-07-25 18:55:51Z. Read back: 792 hourly rows — the 720 injected ones **still dated 2026-06-22 18:00Z .. 2026-07-22 17:00Z**, unmoved — followed by exactly **72 contiguous `HOURLY_NO_DATA` rows covering the outage**, ending adjacent to the in-progress hour. The decisive part is decoding the base snapshot ring *on its own*, since that is what `Display.h` dates every entry from: the anchor moved 2026-07-22 17:00Z → 2026-07-25 17:00Z while the newest real entry stayed at 2026-07-22 17:00Z / 24.7-24.9-24.8 °C and the ring rolled 72h. The old code made the same anchor move with no fills, re-dating all 720 readings 3 days forward. |
| — | 2026-07-25 | **PASS** | **A format bump no longer erases the archive** (`19dde9f`). `HS_FORMAT` 2→3, nothing else changed, uploaded, reset pulsed while already capturing: `HistoryStore: on-flash format 2, firmware speaks 3 — archive left intact and DISABLED. Back it up (tools/history.py backup), then erase_flash to start a new one.` No `formatting`, no `restored`, no base write — on that boot or the two after. The partition is **byte-identical** across the exercise: sha256 `bd49a1a6…c774b2`, 1966080 bytes, `cmp` clean. The "before" image was read with `esptool --after no_reset` deliberately — a normal backup's trailing reset lets the working firmware cold-boot and append a legitimate record, which would have confounded the hash. `history.py backup --full` still decoded the disabled archive off the device (792 hourly), so the recovery path the log points at works. |
| — | 2026-07-25 | **BUG FOUND** | **The journal rebuild boot-looped the device.** Scanning slot by slot meant ~119k `esp_partition_read` calls per pass, which blew the 5s task watchdog: `task_wdt: IDLE0 (CPU 0)` → panic → reboot → repeat, on every cold boot with no base (i.e. every boot after `erase_flash`). Symptom on the bench was subtle: the panel kept a stale frame and `history.py backup` showed `base (none — journal only)`, which reads like "hasn't slept yet" rather than "looping". Fixed by reading 512-byte chunks, skipping all-0xFF chunks outright (an erased journal now costs one read per chunk and no CRC), and yielding to IDLE0 every 256 chunks so the margin does not depend on an estimate. `tools/hstest` now bounds flash *calls*, not bytes — it fails at `2051 flash reads over 2048 slots` if the per-slot scan returns. |
| — | 2026-07-25 | **PASS** | **Real rebuild measured.** Injected a 720-hour archive, clobbered both base slots, restored: `no base — rebuilt 720 hours from 720 journal records in 2444ms`, then `sparkline backfilled with 24 hourly points`, then a normal boot — no watchdog. 2444ms is ~3x the estimate that replaced a 10x-wrong one, which is why it is logged at runtime now. Dominated by per-call read overhead (~320µs per 512-byte read), so a full journal adds CRC for ~122k slots per pass on top; the yield is what keeps that safe rather than the arithmetic. |
| — | 2026-07-25 | note | `! NOARCH fmt2` was **not** visually confirmed on the panel — no camera on the bench. The plumbing is verified (serial line correct; `s_flash_format` carries the *on-flash* value, so it reads `fmt2` not `fmt3`) and `tools/sim` renders the badge at all four sizes, but the physical frame is inference. |
| — | 2026-07-25 | **BUG FOUND** | Injection exposed that `drift_state_load()` trusted flash: an injected `resync_interval_s = 0` puts `next_resync_time` on `now`, so **every wake would bring up WiFi** (1.5-4.5C per failed attempt). Now clamped, and drift samples with a zero measurement window are dropped rather than inflating the on-screen `nN`. Badge went `+0ppm n1` → `-5265ppm n1`. |
| — | 2026-07-26 | flash | **Different rig: XIAO ESP32-C6 + BMP581 + Seeed ePaper driver board (GDEW029I6FD), `/dev/ttyACM0` (USB-Serial-JTAG, MAC 58:E6:C5:16:1F:08), PPK2-powered at 4.2V via the shield JST.** Env `seeed_xiao_esp32c6_epaper_release`, `PLATFORMIO_BUILD_FLAGS="-DPPK2_DEBUG"`, hash `4c0bbef`. `local-secrets.h` moved from `USE_154_Z90`+`USE_BMP390L` (the FireBeetle rig) to `USE_290_I6FD`+`USE_BMP58x`; original backed up for restore. Previous firmware was `1ed89a3` (2026-07-06) on the **old** table — `factory` at 0x10000, no `history` — after a 19d23h basement run, so this upload is the relocation to `factory` 0x1f0000 and the archive's first appearance on this board. Written with `--before no_reset --after no_reset` so the chip stayed halted in download mode and boot #1 lands on a PPK2 capture rather than on the USB session. No `erase_flash`: the old app's bytes are simply inside the new `history` region, the same starting state as observation #1 on the E. Boot #1 result pending. |
| — | 2026-07-26 | note | **Probe the XIAO's soldered BAT connector, not the hat's JST2.** JST2 is not the battery input: energising it gives a 0.2ms ~14mA inrush into its own input capacitance and then nothing, which reads exactly like a dead board. Measured on the BAT pads the supply bypasses the shield's ETA9740 path, so the ~330-500µA that path idles at is absent and a sleep-floor figure *is* valid from this wiring — compare against the 22µA @ 4.2V battery-direct datapoint in [`docs/notes.md`](notes.md). |
| — | 2026-07-26 | flash | Re-armed the first-boot measurement on the C6 ePaper rig: `erase_flash` then reflash of the same `4c0bbef` / `seeed_xiao_esp32c6_epaper_release` / `-DPPK2_DEBUG`, both with `--before no_reset --after no_reset` so one BOOT+RESET covered both operations. Needed because an unpowered PPK2 lead (hat JST2, see note below) meant the board first booted on USB, consuming the one-time format. **Full-chip erase of 4MB took 1.7s**, which argues the archive format is erase-block bound (30 aligned 64KB blocks) rather than the 480 sector erases the ~26s projection assumes — expect single-digit seconds. Unmeasured either way until the trace comes back. |
| — | 2026-07-26 | flash | C6 ePaper rig to `f07d2c9` (`seeed_xiao_esp32c6_epaper_release`, `-DPPK2_DEBUG`), `--before default_reset --after no_reset`, **no** `erase_flash` — so the archive formatted on the previous boot survives and the one-time format will not recur. Two operational lessons: **nrfconnect holds serial ports exclusively and resets whatever it opens**, which knocked the chip out of download mode mid-session; and **the ttyACM number is not stable** — when the ESP32 dropped off the bus the PPK2 inherited `ttyACM0`, so a hardcoded node sent esptool sync bytes to the PPK2 (harmless, connect failed). Resolve via `find /dev/serial/by-id -name '*Espressif*'`. A poll-and-retry loop on that path flashed successfully with `default_reset` alone the moment the device enumerated, so the BOOT hold is not always needed. |
| — | 2026-07-26 | flash | C6 ePaper rig to `91f08eb`, `seeed_xiao_esp32c6_epaper_release`, **no `PLATFORMIO_BUILD_FLAGS`** — a true production build: no `PPK2_DEBUG`, so no D0/D1 markers, no `ppk2_selftest()`, GPIO16/17 never touched, and `power_efficient` true so no `! DEBUG` badge. Flashed to test whether the sleep-floor hump seen on `f07d2c9` exists in shipping firmware or is confined to the debug build's pad handling. Analysis must be current-only; the marker-driven paths in `tools/ppk2.py` have nothing to key off. |
| — | 2026-07-26 | flash | C6 ePaper rig to `e8fb31e`, `seeed_xiao_esp32c6_epaper_release`, `PLATFORMIO_BUILD_FLAGS="-DPPK2_DEBUG"` (1000402 B; the same env without the flag is 1000114 B, which is how to tell the two apart — the selftest's `LOGI` string is eliminated under `DISABLE_SERIAL`, so its absence proves nothing). Verification flash for the code-review fixes: the marker fingerprint is now 80 ms and emitted every wake rather than 400 ms on the first boot only, the unbounded USB flash-hold is gone, and `tools/ppk2.py` reports floor/mean/excess per sleep region with a non-homogeneity warning. Analyse marker captures with `--decimate 1`; the short fingerprint does not survive decimation. |
| — | 2026-07-26 | flash | **Clean state.** `esptool erase_flash` (full chip, 1.5 s) then `2d90340`, `seeed_xiao_esp32c6_epaper_release`, **no `PLATFORMIO_BUILD_FLAGS`** (1000114 B — the same env with `-DPPK2_DEBUG` is 1000402 B, which is how to tell them apart). Erased deliberately: a sensor ground came loose and a spurious **127.5 °C** reading had been recorded, and with no temperature plausibility gate in the firmware it reached the hourly ring, the sparkline, the boot min/max and `previous_temp` — and through the base snapshot, flash. Archive starts empty; the 30-day chart rebuilds from here. Write verified by esptool exit status, not by pipeline exit status — a watcher loop of the form `esptool ... \| tail && echo OK` reports success unconditionally, because it tests `tail`. |
| — | 2026-07-26 | **PASS** | **Temperature plausibility gate and unattended sensor recovery.** C6 ePaper rig, `seeed_xiao_esp32c6_epaper_release`, no `PLATFORMIO_BUILD_FLAGS`. Flashed from an uncommitted working tree, so the panel hash was `-dirty` and resolves to no commit — an early version of the gate, before the identity check and the recovery rework. Sensor ground pulled with the device running: panel showed `--.-` with `! SENSOR`, status line `#5 r2 lp1 u4 0d w:ULP mx4.3V`. **Two refreshes across five wakes** — one into the fault, one on recovery, the three intervening wakes silent. `u4` climbing once per wake identifies the failure as a NACKing sensor rather than one returning zeros: both LP-core I2C error paths call `ulp_lp_core_wakeup_main_processor()` unconditionally, so a dead bus costs one CPU wake and one LP program reload per `SLEEP_INTERVAL_S` (60 s on a release build). Left unbounded by decision — rare, and either self-clearing or terminal. |
| — | 2026-07-26 | **BUG FOUND** | **`lp1` after nine reloads: LP counters cannot survive a reload on their own.** Measured on the C6 ePaper rig during a sustained sensor fault (`u9`, `lp1`). `ulp_lp_core_load_binary()` memsets the whole `CONFIG_ULP_COPROC_RESERVE_MEM` region before copying the program — that is how it initialises `.bss` — so two comments claiming the loader leaves `.bss` alone were wrong, and confining the driver's own zeroing to cold boots changed nothing. The counters are now saved and written back around the load; `prev_temp_c` deliberately is not, because a zero reference is what guarantees the next sample wakes the CPU. |
| — | 2026-07-26 | **BUG FOUND** | **A preserved LP delta reference stranded a repaired sensor.** Carrying `prev_temp_c` across a reload left it holding a value the LP core had latched from a floating bus during the fault, within `TEMP_DELTA_THRESHOLD_C` of the real room. Ground reconnected, sensor reading correctly, no delta produced, CPU never woken, panel blanked — until warming the sensor by hand supplied a change large enough to wake it. Recovery would otherwise have waited on the hourly safety net. Wakes are delta-triggered, not periodic, which is also why nothing that counts consecutive wakes can be used to confirm recovery. |
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

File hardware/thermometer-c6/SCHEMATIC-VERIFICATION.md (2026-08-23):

# Schematic verification record — rev A pre-order sign-off

**Date:** 2026-07-20. **Scope:** schematic only (PCB/DRC covered by the
`make fab` gate, see ORDERING.md). **Verdict: no order-blocking error found.**

Method: `make check` (mechanical gate) plus four independent review passes
(power chain / MCU+sensors / EPD interface / meta cross-check), each working
from the exported netlist and **primary sources only** — device datasheets,
the DESPI-C02 reference schematic, Espressif documentation, LCSC part pages —
never from README tables, code comments, or `verify/` scripts. Every symbol
pin-number→function mapping used by the netlist was re-derived from its
device datasheet (a wrong symbol passes every automated check at once).

## Mechanical gate

- ERC clean at `--severity-all` (0 violations); netlist golden match
  (35 named + 25 anonymous nets, 298 pin connections); all invariants pass;
  all footprints resolve.
- Regenerating from `generator/` produced a **byte-identical**
  `thermometer-c6.kicad_sch` to the committed file.

## Requirements — all PROVEN

| Req | Proof (primary sources) |
|---|---|
| R1 MCU boots/runs | All 22 module GND pins + pin 3=3V3 pin-by-pin vs ESP32-C6-MINI-1 datasheet Table 3-1 (verified independently twice); EN RC 10k/1µF = Espressif HDG exact; BOOT pulls GPIO9 low (SPI boot needs high, Table 4-3); strap audit GPIO4/5/8/9/15; USB D+/D− traced unswapped J3 A6/B6→USBLC6 3↔4→GPIO13, A7/B7→1↔6→GPIO12 (ST USBLC6 p.2 + C6 datasheet); UART0 on module pins 31/30 |
| R2 EPD drive | 24/24 J4 pin functions match the DESPI-C02 reference transcription (rendered PDF); BUSY/RES/DC/CS/SCLK/SDI → module pins 29–24 = GPIO23–18; booster topology + all three MBR0530 orientations verified against the reference AND first principles (per-diode reverse stress ~20V vs 30V rating); Si1308EDL G/S/D per SC-70 datasheet; all panel power on gated EPD_VCC — no J4 pin touches always-on 3V3; RES pull-up to EPD_VCC; BS→GND = 4-wire SPI per SSD1677; XUNPU FPC-05FB rated 50V between adjacent terminals (VGH/VGL on pins 4/5 span ~40V — inside rating), 0.5A/contact |
| R3 BMP58x @0x47, LP core | LP_I2C fixed to GPIO6/7 (C6 datasheet) = U1.15/16 = firmware pins (`include/app_common.h`, `ulp/lp_core_main.c`); BMP581 symbol == Bosch Table 28, BMP585 == Table 26 (pinouts differ, checked separately); CSB→VDDIO = I2C, SDO→VDDIO = 0x47 per both datasheets; INT-floating sanctioned by Bosch §6.2 |
| R4 Battery/charging/measurement | MCP73831 PROG 10k → 100mA (DS20001984H §5.1.2 + EC table); -2ACI = 4.20V; load-share proven by Vgs analysis (USB present → Q1 off → charger terminates on true cell current); Q6 reverse-battery blocks by body-diode analysis (AO3401A); divider level-shift GPIO3→2N7002→Q4 correct; VBAT/2 ≤2.1V on ADC1_CH2, VBUS/2 on ADC1_CH4 (channel map per C6 datasheet) |
| R5 Sleep leakage | Every VBAT/VBUS/3V3→GND path walked in the sleep state: divider dead (Q4 Vgs=0), VBUS nets dead unplugged, STAT floats, no pull-up carries standing current (I2C idles high), EPD gate held off by R12. Floor = RT9080 Iq (2µA typ) + MCP73831 reverse drain (≤2µA max) — consistent with the measured ~15.8µA C6 rig floor |
| R6 Bench/debug | JP1/J2 series-break correct (default bridged); TP1–TP11 nets confirmed; debug header order asserted 1–10, GND-first, no VBAT beside 3V3; TP4 probe-only per RT9080 active-discharge spec |

## Key facts verified (source)

- RT9080-33GJ5: pinout, EN polarity, 600mA/ILIM 610mA min, Iq 2µA, output-cap
  requirement (DS9080-09 p.1/4/6). MCP73831: pinout, tri-state STAT, PROG
  formula (DS20001984H). SS14 Vf 0.5V typ (Vishay 88746). AO3401A 30V P-ch,
  1=G/2=S/3=D, all four instances by function. USBLC6-2SC6 1/6=I/O1, 3/4=I/O2,
  2=GND, 5=VBUS (ST p.2). FC-135 CL=12.5pF → 2×20pF (Epson/LCSC C32346).
- BOM == circuit.py == netlist across all 75 populated lines; DNP flags
  consistent; jumpers/TPs/holes correctly absent from the BOM.
- LCSC C-numbers spot-checked against product pages: C5736265 (MINI-1-N4,
  4MB, PCB antenna), C5362283, C18184976, C32346, C98192 (4.7µF **50V**),
  C28323 (1µF **50V**), C424093, C841192, C15127, C8545, C2480, C165948,
  C7519, C2856831 (FPC-05FB dual-contact), C2930220 (FOJAN FRL0805FR470TS =
  0.47Ω 1% 0805 current-sense).

## Findings and dispositions

1. **GPIO8 has no pull-up** — BOOT-button serial download relies on floating
   GPIO8 reading high (Espressif: unreliable). USB-Serial-JTAG download works
   regardless; README documents "header only" as the intent. **Accepted for
   rev A** (rev B candidate: 10k pull-up mirroring R7).
2. **EPD control pins (GPIO18–23, always-on domain) can back-power the
   gated-off panel** through its ESD diodes unless firmware tri-states them
   before sleep. Matches DESPI (no series resistors, README open item 4).
   **Firmware obligation** — float EPD pins before deep sleep.
3. **LDO dropout at EOL battery**: worst-case RT9080 needs VIN ≥~3.71V to
   hold 3.3V at the 465mA EPD peak — right at the 3.7V cutoff.
   **First-article bench item**: measure 3V3 sag at 3.7V supply during
   refresh (feeds the planned cutoff re-derivation).
   **Closed 2026-07-31**: BOD probe measured ~300mV droop at the peak; cutoff
   re-derived to 3550/3500mV (`1e1048e`).
4. **Boost transient vs 610mA ILIM**: pulsed inductor current could brush
   the LDO limit. **First-article bench item** (PPK2 peak capture).
5. **Physical FPC cable pin-1 orientation** — logically proven pin-for-pin;
   dual-contact part removes the flip failure mode; end-for-end cable fold
   is only checkable against the real panel. **Closed on hardware**: BRINGUP
   Phase 0 continuity, all 24 nets to the right adapter pins, then board 1's
   first render.
6. **Crystal 20pF load assumes ~2.5pF stray** — correct nominal; cold-start
   already a first-article item (7pF FC-135 variant is the fallback).
7. **`datasheets/XUNPU_FPC-05FB-NPH20.pdf` was corrupted** (circular xref)
   — replaced 2026-07-20 with the ghostscript-repaired LCSC copy
   (C2856831 datasheet = the same FPC-05FB-NPH20 manufacture drawing;
   confirms pads 0.30×1.20 @0.5mm, tabs 2.0×1.8 at 14.6mm c-t-c, body 5.40,
   rear-flip dual contact).
8. **Verification-harness coverage gaps** — closed 2026-07-20:
   `check_netlist.py` now also verifies component value/footprint/LCSC/dnp/
   exclude_from_bom against circuit.py and that every declared-NC pin is
   really unconnected on the sheet (NC is now bidirectional); `invariants.py`
   now asserts the charger PROG node + 10k value, LDO VOUT + output caps,
   and the datasheet-derived critical values (EN RC, 32k load caps, I2C
   pull-ups, CC Rd, divider pair, RESE ladder, inductors, 50V boost caps,
   DNP roster / populate-exactly-one). Fault-injection tested (wrong value,
   wrong LCSC, wrongly-NC'd pin all fail the gate).
9. **FPC anchor tabs are netless** — common practice, left as-is.

Remaining independent-coverage note: the BOM shares circuit.py as its source,
so a wrong-but-self-consistent circuit.py value can only be caught by
invariants.py's hand-written value list (keep it in sync with datasheet
reasoning, per the three-files rule in CLAUDE.md).

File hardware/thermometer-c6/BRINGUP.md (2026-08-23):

# BRINGUP.md — rev A first-article checklist

Consolidates the bring-up items from README (Bench procedures, open items),
REVIEW-KICAD-HAPPY.md (○ OPEN rows), SCHEMATIC-VERIFICATION.md (first-article
adds), and the placement verification in
[`archive/order-2026-07-20/jlc-production-files/`](archive/order-2026-07-20/jlc-production-files/).
Run Phases 0–2 in order on the first board; Phase 3 measurements once; then a
quick Phase 0–1 pass on the remaining boards. Bench ground rules (README): **never back-feed TP4 (3V3)** —
RT9080 forbids VOUT > VIN + 0.3V and EN=0 active-discharges at ~80Ω; inject
bench power only at the J2/JP1 battery-side break.

Test points (back side): VBAT, VBAT_ADC, 3V3 (probe-only), EPD_VCC, PREVGH,
PREVGL, VCOM, GDR, RESE, GND ×2. J2 (the `IBAT` header) spans the JP1
break: pin 1 = battery side (VBAT_RAW), pin 2 = system side (VBAT — the
charger output node, *not* VSYS). VSYS has no TP or header — probe D2's
cathode (band/west) pad, Q1's source, or C1/C2.

## 2026-07-27 — JLC first-article X-rays (taken pre-arrival; boards landed 2026-07-29)

Four frames in [`archive/order-2026-07-20/xray/`](archive/order-2026-07-20/xray/),
one per assembled board — distinct solder micro-features per frame prove they
are not re-shots, but the frame↔board mapping is unknowable. Per-part
identification is proven, not eyeballed:
[`xray/annotated/`](archive/order-2026-07-20/xray/annotated/) overlays every
top-side footprint's bbox projected from the board file (transform +
per-part verdict table in
[`xray/README.md`](archive/order-2026-07-20/xray/README.md);
`xray/annotate.py` regenerates). Findings, consistent across all four:

- U5 (BMP581 LGA-10): all 10 joints wetted and uniform, package centered,
  no bridging.
- U1 (MINI-1): castellations evenly wetted, no bridges, module centered.
  Center GND pads unreadable through the module's internal layers — fine,
  no thermal load. The 45°-rotated QFN is the C6 die inside the module.
- J3 (USB-C): 0.5mm pin row resolves individually, no bridging; shell
  through-legs filled. **J4 is off-frame in all four images** (frames cover
  x≲38mm of the 48mm board; J4's row sits at x≈41.5) — the X-rays say
  nothing about it, so the Phase 0 optical bridge check on J4 is the only
  inspection it gets.
- Satellite solder micro-balls (~50–100µm) near U5 on 2–3 frames — see the
  Phase 0 item below. The fuzzy round blob top-right in two frames is off
  the board at (x≈−6.1, y≈−2.8)mm — on the panel rail/carrier, and too
  faint to be solder at its ~0.9mm diameter.

X-ray confirms geometry only (no bridges, nothing missing or shifted); it
proves neither electrical contact on the LGA nor passive values — Phases 0–2
remain the gate.

## Phase 0 — before any power (per board)

Board numbering (2026-07-29, boards in hand): the four assembled boards are
hand-marked 1–4 on the back below the USB port — the fab put no serials on
them, so the numbers map to neither JLC's internal count nor the X-ray
frames. The lone unassembled board carries a factory 0005 datamatrix and is
board 5. Board 1 is the first-article board for Phases 0–2.

- [x] Visual pass against the JLC renders / placement-verification table:
      J4 0.5mm-pitch row for bridges, U1 module fillets, U5 seated (vent
      pinhole NW, pin 1 SW), **U6 pads empty**, every diode band per the
      table (D1/D3 cathode E, D2 W, D4/D5 S, D6 W).
      2026-07-29: pass on all four assembled boards. Board 4's U5 sits
      slightly skewed (rotation). The X-rays showed all four packages
      centered, but the frame↔board mapping is unknowable, so they can't
      clear board 4 specifically; slight LGA skew is normally benign
      (reflow self-alignment). Arbitrate at the Phase 2 BMP581 detect —
      run board 4 through that check early.
- [x] Loupe + brush pass around U5: the X-rays show satellite solder
      micro-balls near the package on 2–3 boards — dislodge anything loose
      (vent-port neighborhood; harmless once confirmed not mobile).
      2026-07-29: nothing visible under the loupe on any board; finish
      very clean. Treating the micro-balls as under-package/immobile.
- [x] Jumper state as shipped: JP1 bridged (copper), JP2+JP5 bridged
      (0.47Ω RESE + 10µH — universal default), JP3/JP4/JP6 open.
      2026-07-29: confirmed on all boards. Bridges are factory copper
      (must be cut before first use as NO), matching the KiCad model.
- [x] DNP provisions empty: D7 (TVS), R9 (10M 32k bias), U6; J2/J5 headers
      unstuffed; TPs bare. C29 (10nF ADC reservoir) IS populated.
      2026-07-29: confirmed. (R9 is an 0402 across the Y1 pads — bench-
      stuff only if the 32k cold-start item bites.)
- [x] DMM resistance to GND, no dead short: VBAT, VSYS (J2.2), 3V3 (TP4),
      EPD_VCC, PREVGH, PREVGL, VCOM.
      2026-07-29: boards 1 and 5 clear on all seven rails. The RESE TP is
      *not* in this list and must not be added: TP9 sits on EPD_RESE,
      which is R14 (0.47Ω) through bridged JP2 straight to GND — board
      1's 0.60Ω there is the sense resistor plus jumper/probe resistance,
      by design. Board 5 reads open at RESE only because the bare board
      has no R14. **Boards 2–4 never got this pass, and as of 2026-08-12 they
      never will — skipped deliberately, not forgotten.** All three went
      straight to flash on the strength of board 1's pass: same reflow, all
      four X-rayed, boards 1 and 5 clear on all seven rails. What that trades
      is a dead-short check on the four gated booster rails (EPD_VCC, PREVGH,
      PREVGL, VCOM), which no boot log can cover because they are off until a
      render — but a short there fails the first refresh visibly and now raises
      the LED fault blink, so it cannot pass silently. All three have since
      rendered. Reinstate the pass for any board that is reworked or that
      arrives from a different fab run.
- [x] Diode-mode sanity (red probe = +):
      - D2 conducts **VBUS→VSYS** — anode is the east pad, cathode band
        west on VSYS (an earlier revision of this line said "VSYS→VBUS";
        that was backwards). Red on the anode pad, black on the band:
        expect a 0.2–0.35V Schottky drop.
        2026-07-29 board 1: **0.2142V forward — pass.** (The 1.96V first
        measured red-on-VSYS was the blocked direction reading through
        peripheral paths.)
      - Q6 body diode: red on J1 pin 1 (the `+` pad), black on the VBAT
        TP (bridged JP1 makes it the same node): expect ~0.4–0.7V —
        AO3401A D→S body diode, BAT_IN→VBAT_RAW. Swapped: no drop.
        2026-07-29 board 1: **0.4259V — pass** (low end is normal at a
        DMM's ~0.3mA test current; datasheet Vf figures are at 1A).
      - LP I2C pull-ups: Ω mode straight across R10 and R11 (or from
        U6's empty SDA/SCL pads to the 3V3 TP): ~4.7k each.
        2026-07-29 board 1: **4.67kΩ both — pass** (nominal −0.6%,
        within the 1% tolerance). Consistent with the earlier matched
        1.4849V diode-mode readings (≈316µA test current × 4.7k).
- [x] J4↔panel adapter pin-1 continuity (mouth EAST, pin 1 at the NORTH end
      of the row) — the respun footprint's first physical verification.
      Method: J4's nets are probeable at back TPs (GDR→2, RESE→3,
      EPD_VCC→15/16, PREVGH→21, PREVGL→23, VCOM→24, GND→8/17) or at
      front-side component pads on the same nets. Seat the rig's 24-pin
      FFC in J4 with the panel NOT attached at the far end, then beep
      each net against the adapter's matching pin. RESE (pin 3, north
      end) plus VCOM (pin 24, south end) is an asymmetric pair that
      catches a flipped row immediately.
      2026-07-29 board 1: **all continuous and on the right adapter
      pins** — RESE, GDR, GND ×2, EPD_VCC ×2, PREVGH, PREVGL, VCOM.
      The respun footprint (pin 1 north, mouth east) is verified on
      hardware. Bench note: back TPs are impractical when the reference
      is on the front face (FFC seated topside) — coordinating probes on
      both faces mid-air doesn't work; front component pads on the same
      nets were used instead. TPs remain fine for single-face probing
      (powered floor/scope work with the board face-down or on edge).
- [x] **JST pigtail polarity vs the `+` silk before first battery plug**
      (JST vs Adafruit pigtail convention differs — README open item 5).
      2026-07-29: confirmed by DMM on the loose plug — the red wire /
      + contact mates with J1's `+`-marked pad. Shell orientation also
      matches the existing devices' pigtails.

**Phase 0 complete on board 1 (2026-07-29).**

**Board 2 skipped the pre-flash steps entirely, deliberately** — board 1 had
passed cleanly, so the first article was taken as evidence for the batch rather
than each board being re-proven. It worked on first power and has been the bench
board since (2026-08-05 and 2026-08-09, `docs/history-store-validation.md`).
That is the precedent for boards 3–4: a clean first article earns the rest of
the batch a straight-to-flash.

**Board 4 is the exception to that.** Its U5 placement skew was flagged at
X-ray, which is exactly the kind of per-board defect the first article cannot
speak for — run it through the Phase 2 BMP581 detect early rather than
discovering it as a sensor fault later.
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

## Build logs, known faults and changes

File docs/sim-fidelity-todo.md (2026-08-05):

# Simulator fidelity — follow-ups

Gaps where `tools/sim` renders a narrower or different path than the real
device, so a display bug can pass the emulator. Surfaced while fixing the
stale-font oversized-temperature bug (commit "Fix stale font_config.h …").

## Resolved

### Tri-color red (was: sim can't show red, and red was dead on device)

Fixed in "Restore tri-color red…" and "Collocate per-panel attributes…":
- `EPD_RED` now has a single definition in `DisplayRenderer.cpp`, gated by
  `DISPLAY_HAS_RED` (from `include/displays.h`) — the low-battery icon renders
  red on the Z90 again, and temperatures ≥30 °C render red too.
- The sim renders into a 16-bit color canvas (`GFXcanvas16` → PPM → PNG via
  ImageMagick), so red is visible; a `_hot` scenario exercises it.

One binary renders all four sizes, so it compiles a single `DISPLAY_HAS_RED` —
every size is drawn as if it were the tri-color panel. That is deliberate: it is
what keeps the red path exercised at all. It also means the sim cannot show you
how a bi-color panel degrades the same frame. Until 2026-08-05 the flag followed
whichever rig the developer had last built for a device, and `make screenshots`
had been quietly emitting mono PNGs while this section claimed otherwise;
`tools/sim/stubs/generated/rig_config.h` now pins the rig.

## Open

### 1. Sim only ever renders a couple of temperatures

`sim_main.cpp` now covers 22.3 °C and a 31.5 °C hot case, but still never
exercises negative (`-5.2C`), single-digit (`5.9C`), or 3-digit (`100.0C`)
strings. The font width heuristic in `generate_font.py`
(`width_pt = temp_zone_w * 0.9 / 4.8`) assumes an `XX.XC` width, so a
wider/narrower string could clip or misalign on-device and the sim would never
reveal it — the same layout blind spot as the font bug.

- [ ] Add temperature variants to the sim scenarios (negative, 1-digit,
      3-digit, and a max-width case) across all panel sizes.

### 2. Native 64-bit g++ vs 32-bit target

The sim compiles with host g++: `long`/pointers are 8 bytes vs 4 on the ESP32.
Chart/time-axis arithmetic and any `long`-based math can diverge. Low risk for
pure pixel layout, real for time math.

- [ ] Consider `-m32`, or fixed-width types (`int32_t`) in time/axis math, so
      the sim exercises the same integer widths as the device.

### 3. The sim's panel table is still a separate copy

`include/displays.h` holds each panel's tri-color flag and rotation, and
on-device `static_assert`s tie the generated font's dimensions and
`displays.h`'s tri-color flag to the GxEPD2 panel class — so font ↔ GxEPD2 (and
has_red) can't drift silently. Panel dimensions themselves still live in two
places outside that net: `generate_font.py`'s `DISPLAYS` dict (Python) and
`sim_main.cpp`'s `displays[]`. The sim table in particular is unchecked — a
wrong entry there only ever shows in the sim.

- [ ] Feed `sim_main.cpp` (and ideally `generate_font.py`) from a single source
      — e.g. parse `displays.h`, or emit a small generated table — so a
      new/rotated panel can't drift between them.

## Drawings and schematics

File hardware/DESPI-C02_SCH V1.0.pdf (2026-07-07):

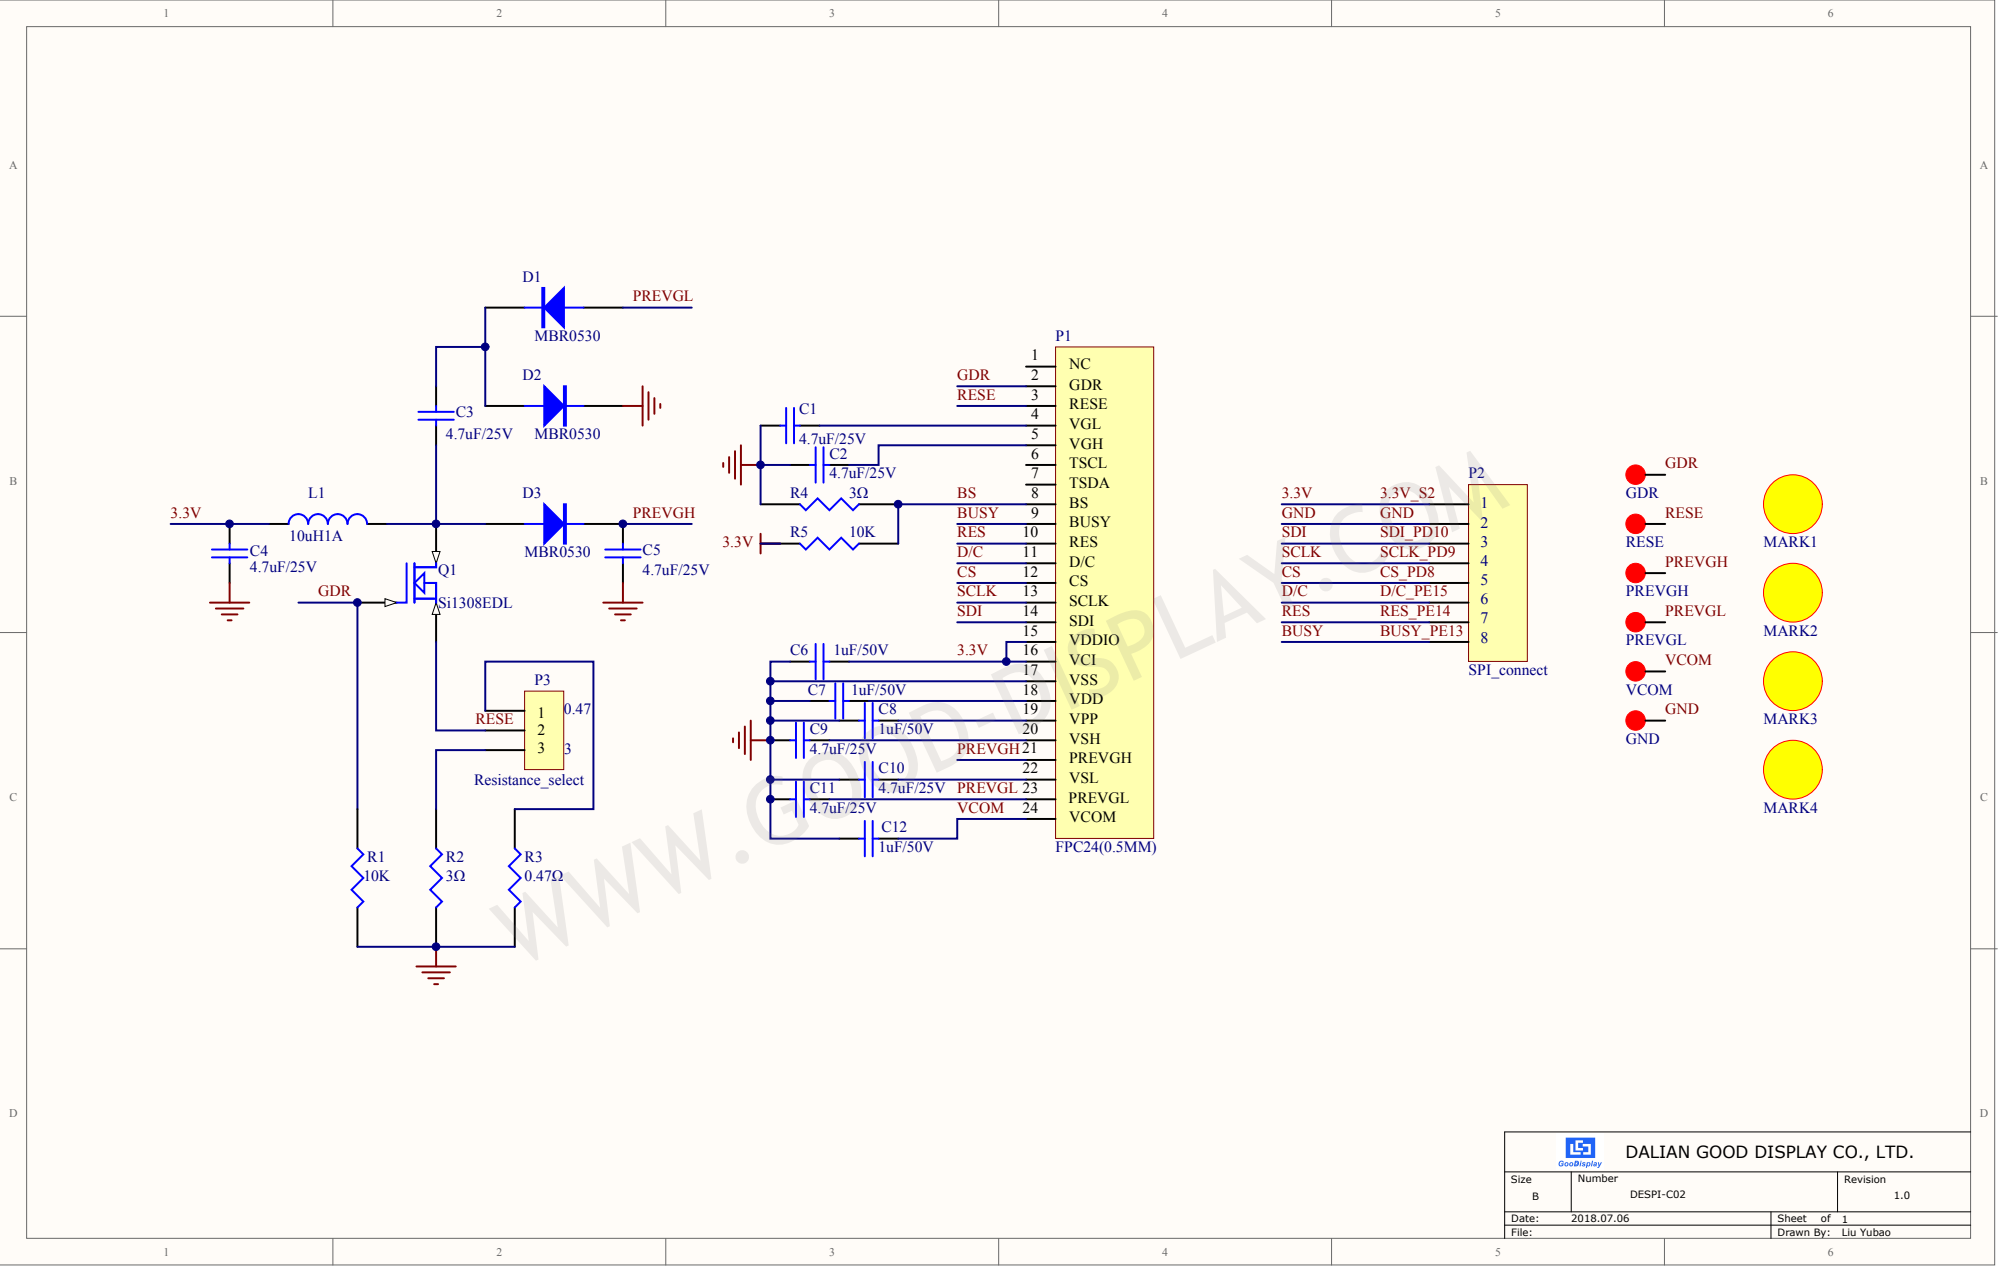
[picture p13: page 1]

C7 | P0P1016 P0P1016 P0P1016 1uF/50V 18 P0P1017 P0P1017 P0P1017
P0P1018 | C8 19
C9 | P0P1019 P0P1020 | 1uF/50V 20

DALIAN GOOD DISPLAY CO., LTD.

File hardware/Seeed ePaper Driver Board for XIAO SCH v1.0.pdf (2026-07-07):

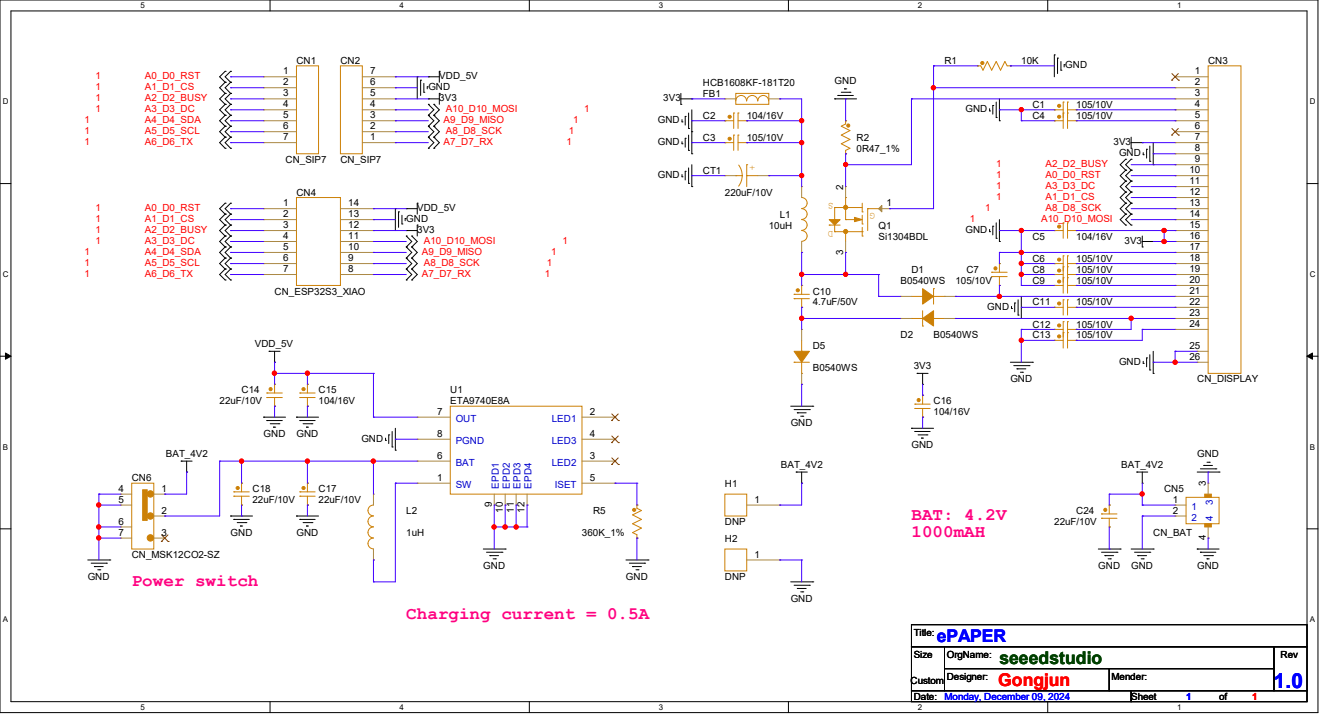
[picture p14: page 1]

C1 | 105/10V 4
C4 | 105/10V 5

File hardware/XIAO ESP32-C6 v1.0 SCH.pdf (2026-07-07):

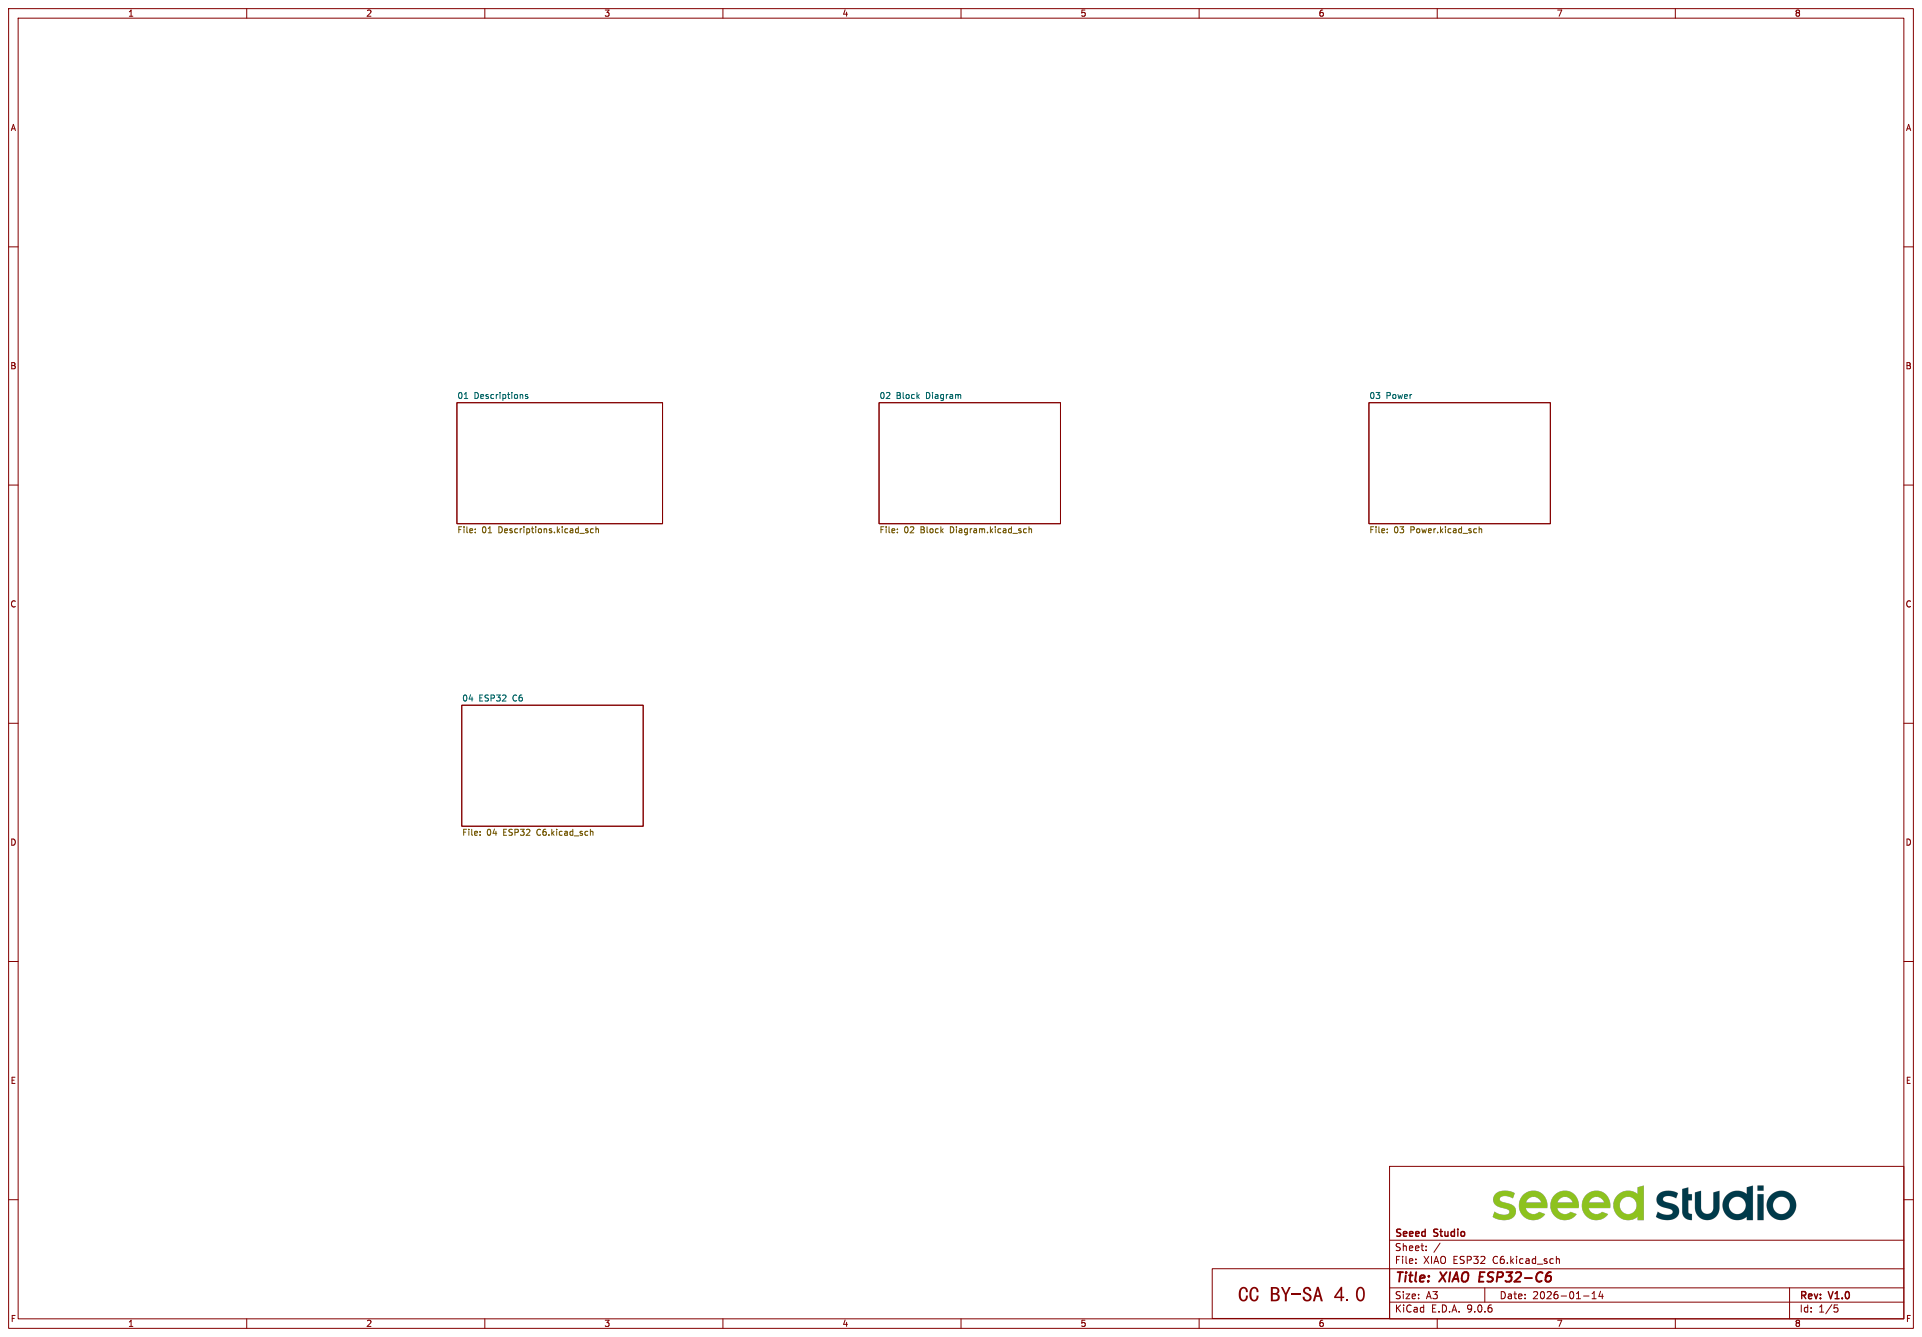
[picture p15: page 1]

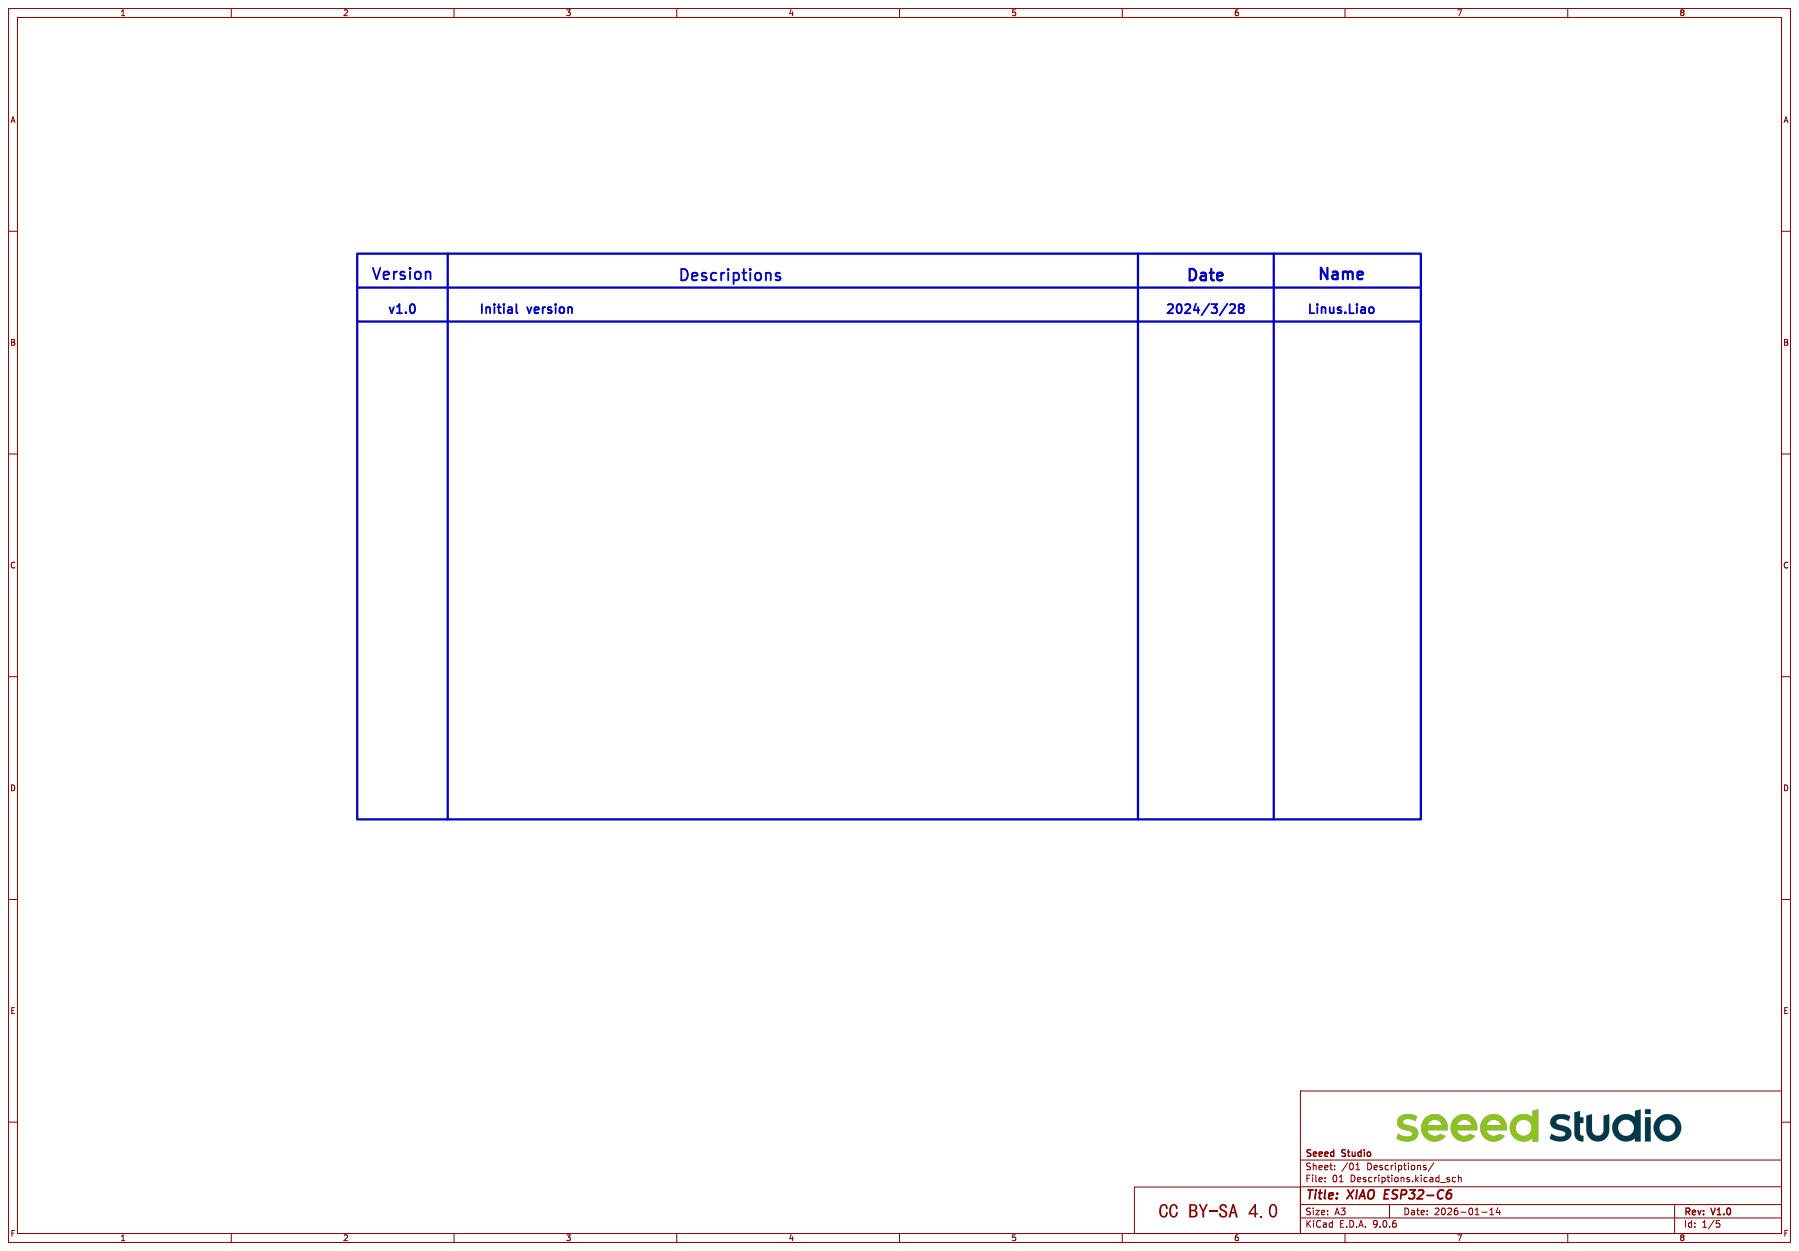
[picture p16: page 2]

Date | | Name

2024/3/28 | Linus.Liao

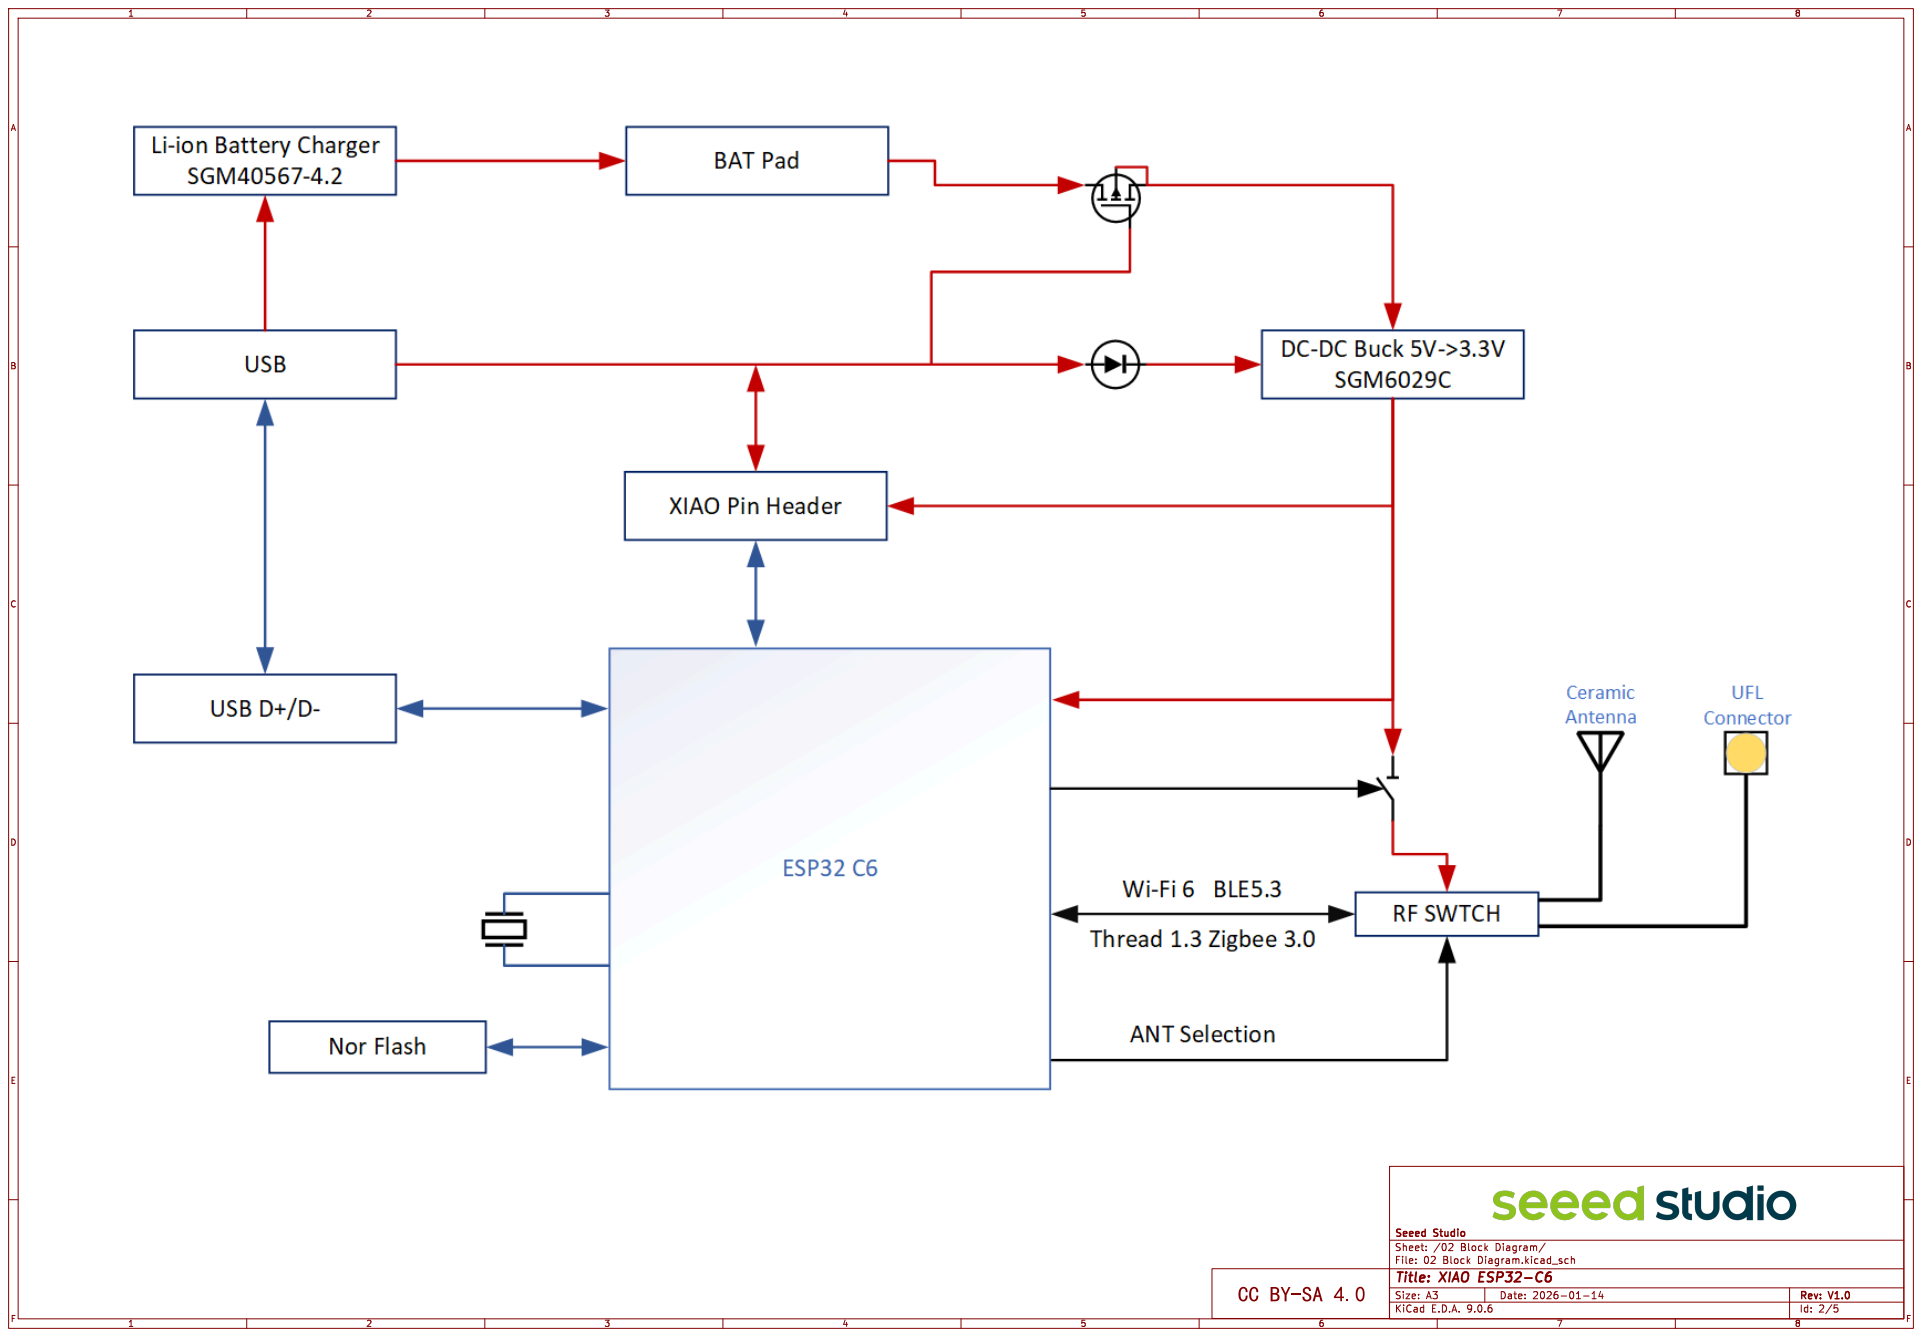
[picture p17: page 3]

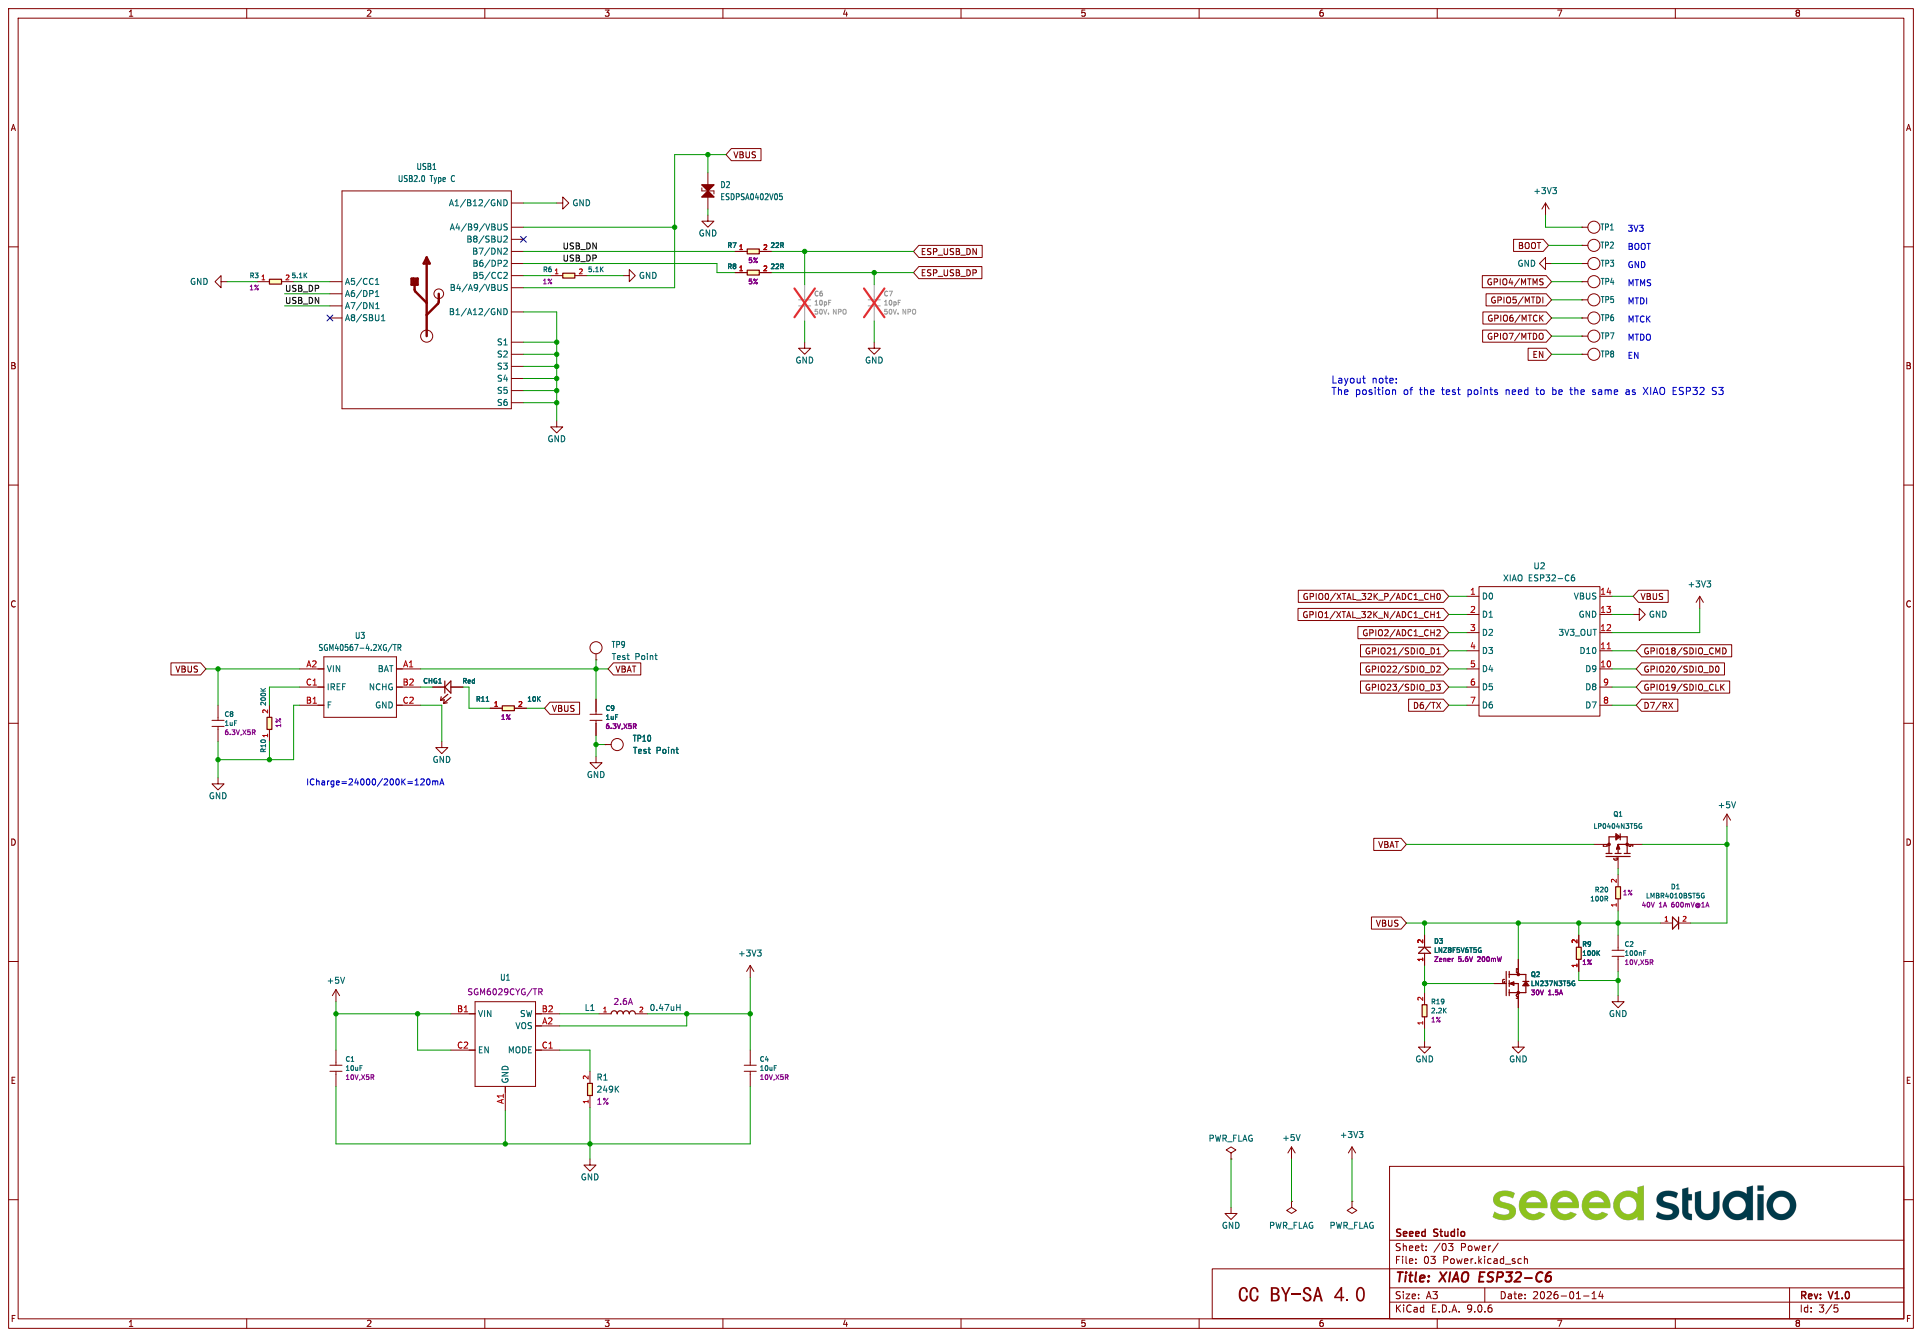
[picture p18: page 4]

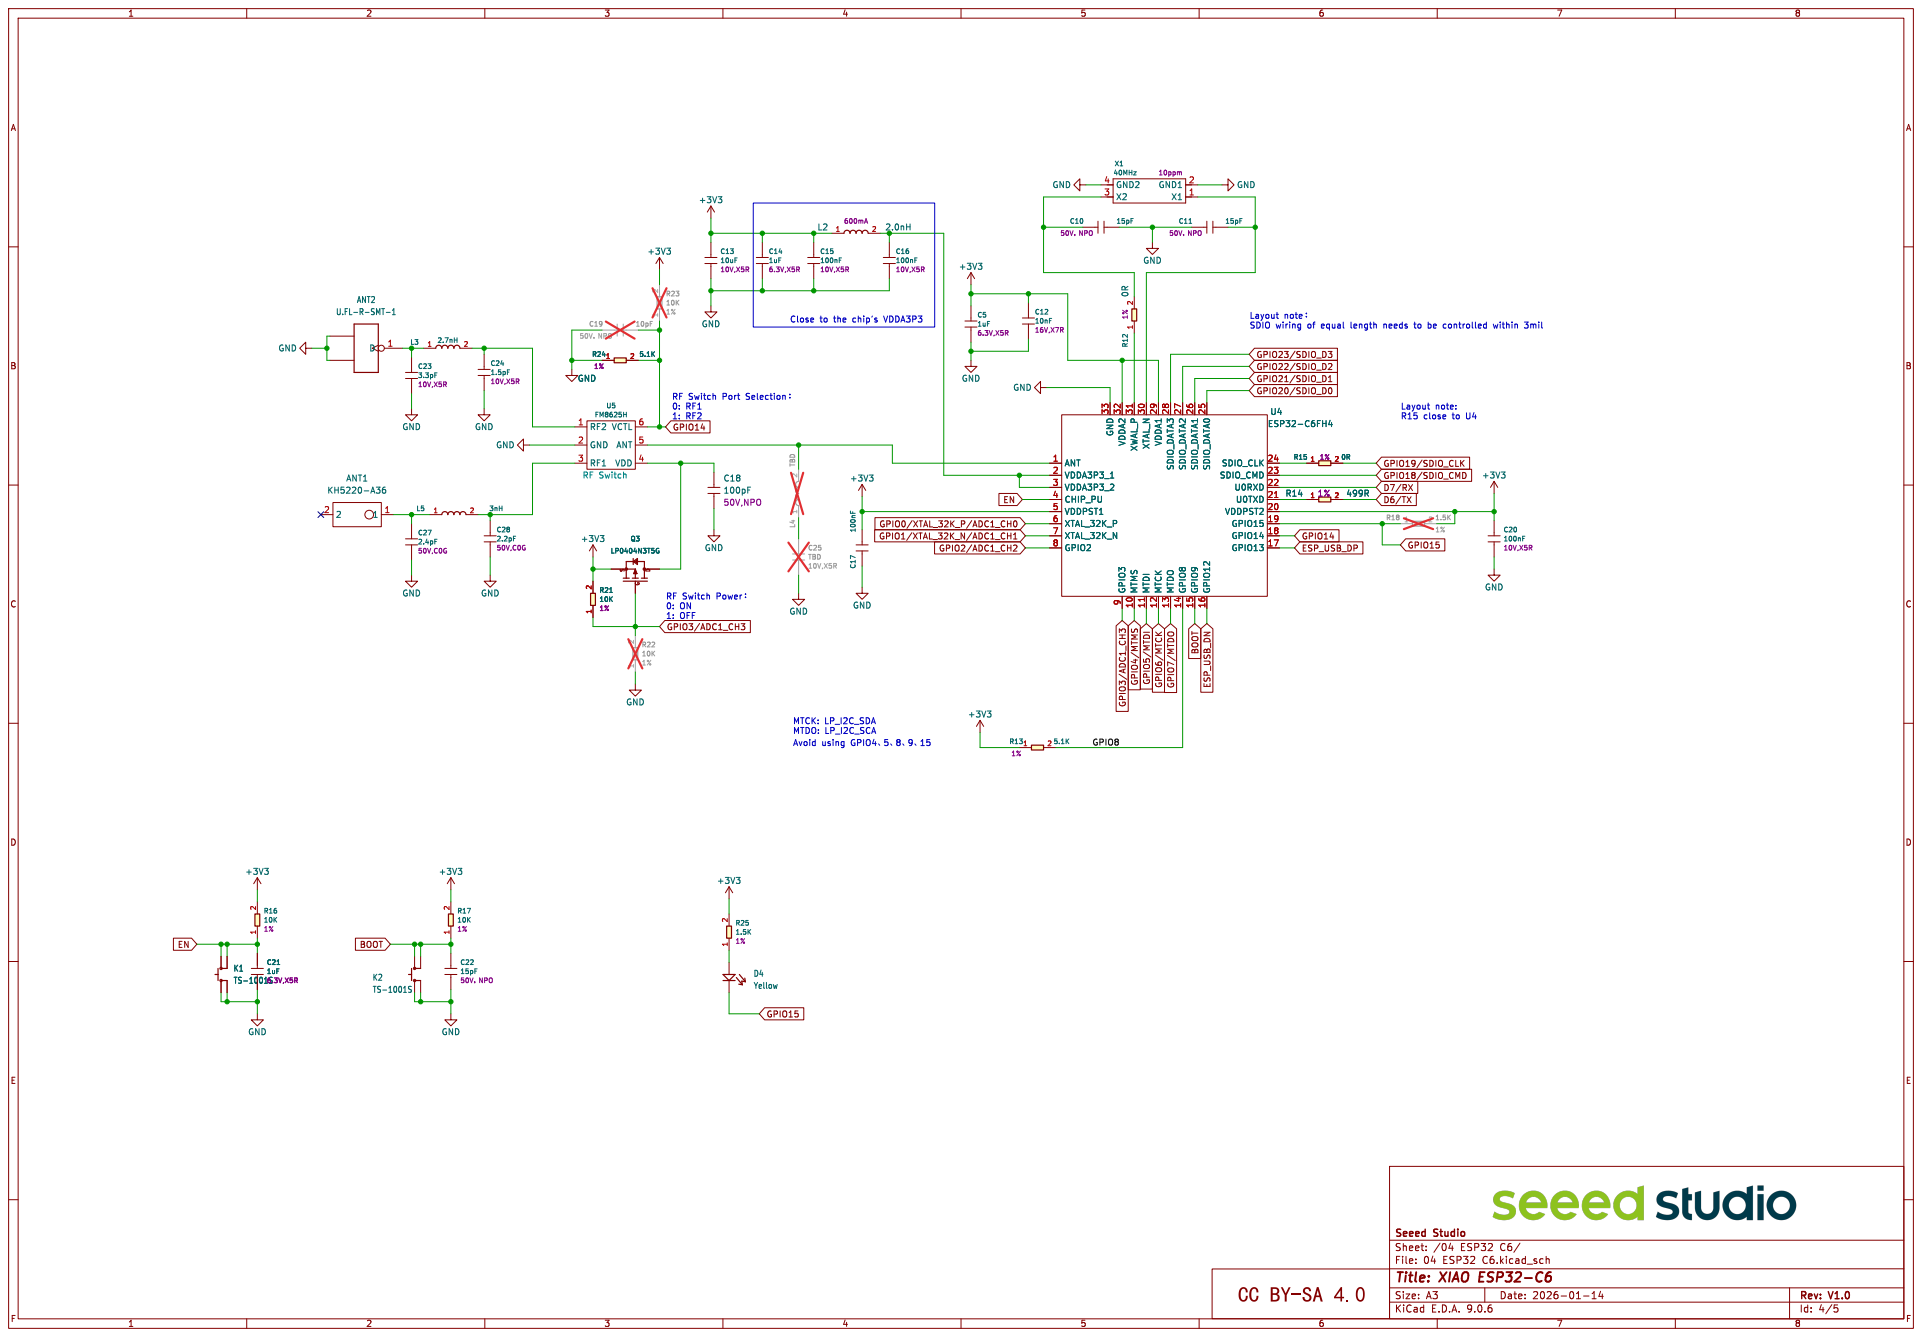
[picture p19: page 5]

1: OFF RF Switch Port þÿSelectionÿ 0: RF1

9 XWAL_P 31 MTMS 10 XTAL_N 30 MTDI 11 VDDA1 29 MTCK 12 SDIO_DATA3 28 MTDO 13 SDIO_DATA2 27 GPIO8 14 SDIO_DATA1 26 GPIO9 15 SDIO_DATA0 25 GPIO12 16 SDIO_CLK 24 SDIO_CMD 23 U0RXD 22 U0TXD 21 VDDPST2 20 GPIO15 19 GPIO14 18 GPIO13 17U4 ESP32-C6FH4 +3V3 R15 1 1% 2 0R R14 1 1% 2 499R

9 XWAL_P 31 MTMS 10 XTAL_N 30 MTDI 11 VDDA1 29 MTCK 12 SDIO_DATA3 28 MTDO 13 SDIO_DATA2 27 GPIO8 14 SDIO_DATA1 26 GPIO9 15 SDIO_DATA0 25 GPIO12 16 SDIO_CLK 24 SDIO_CMD 23 U0RXD 22 U0TXD 21 VDDPST2 20 GPIO15 19 GPIO14 18 GPIO13 17 R15 1 1% 2 0R R14 1 1% 2 499R

Layout note: R15 close to U4

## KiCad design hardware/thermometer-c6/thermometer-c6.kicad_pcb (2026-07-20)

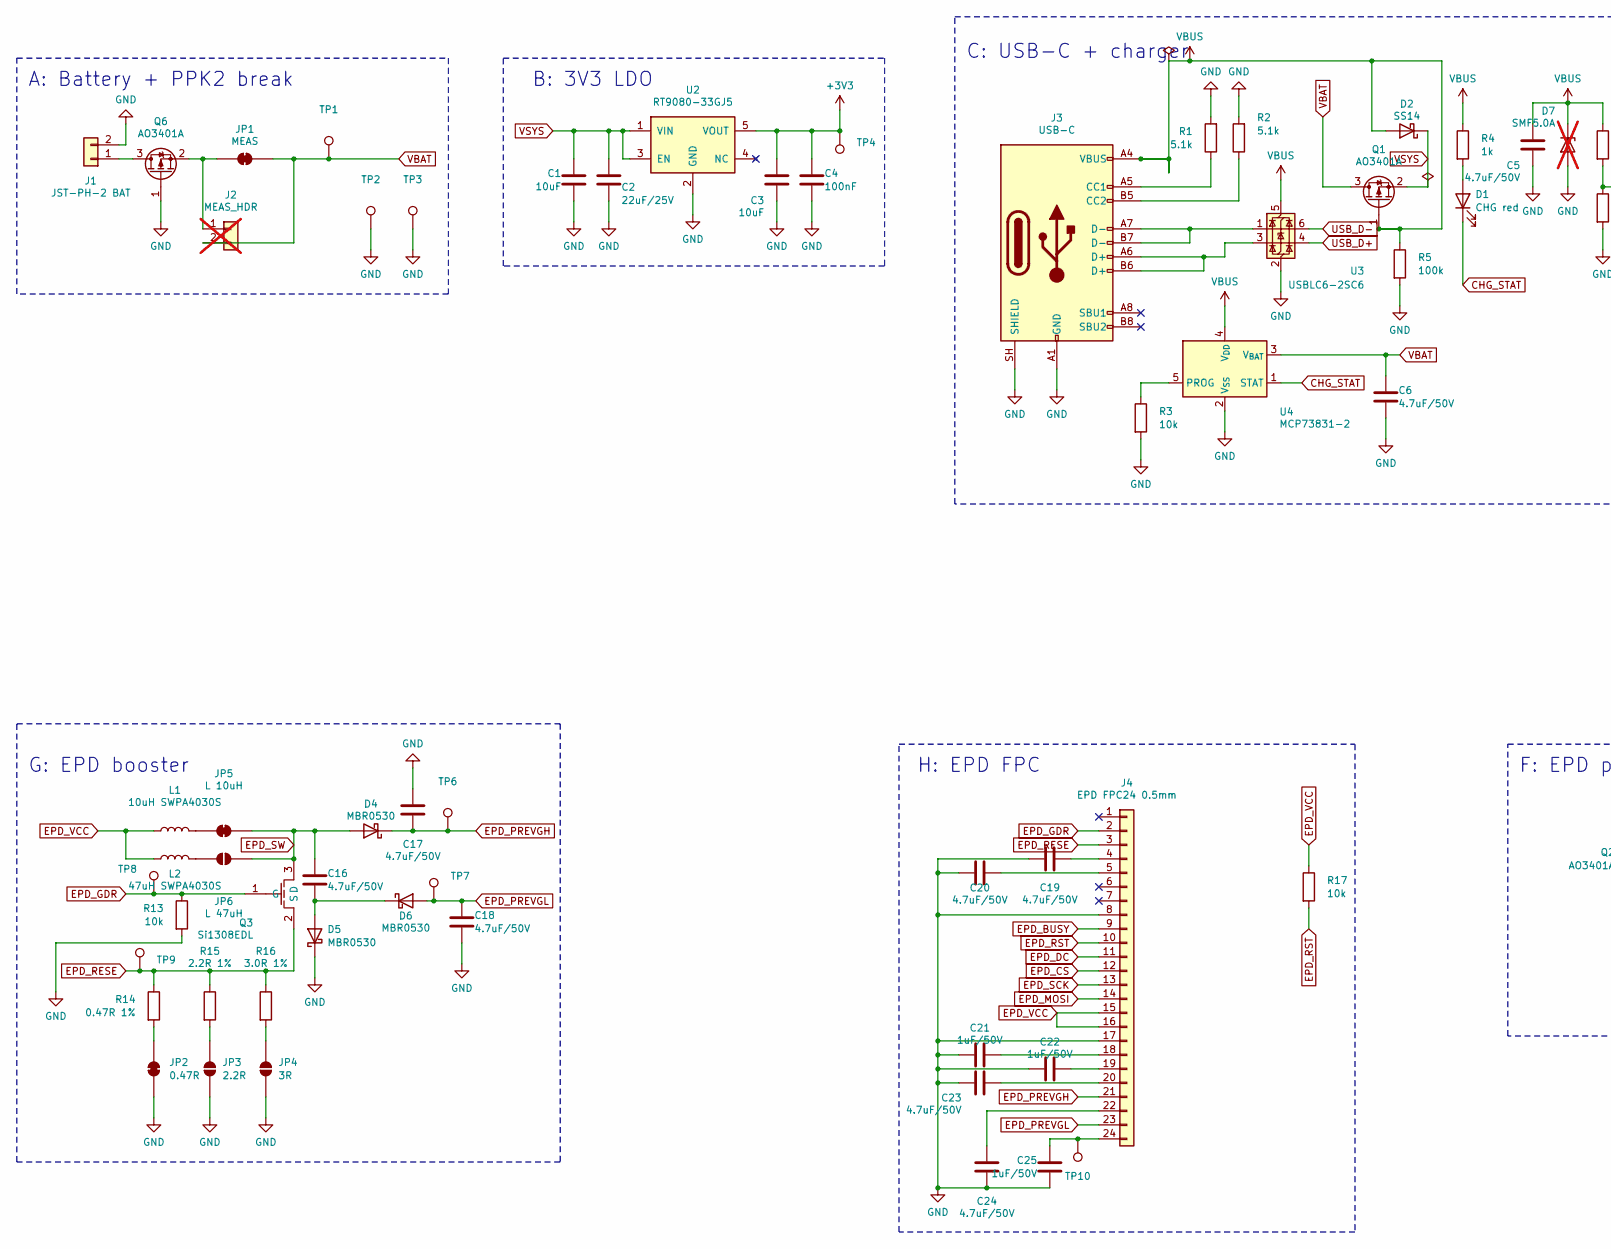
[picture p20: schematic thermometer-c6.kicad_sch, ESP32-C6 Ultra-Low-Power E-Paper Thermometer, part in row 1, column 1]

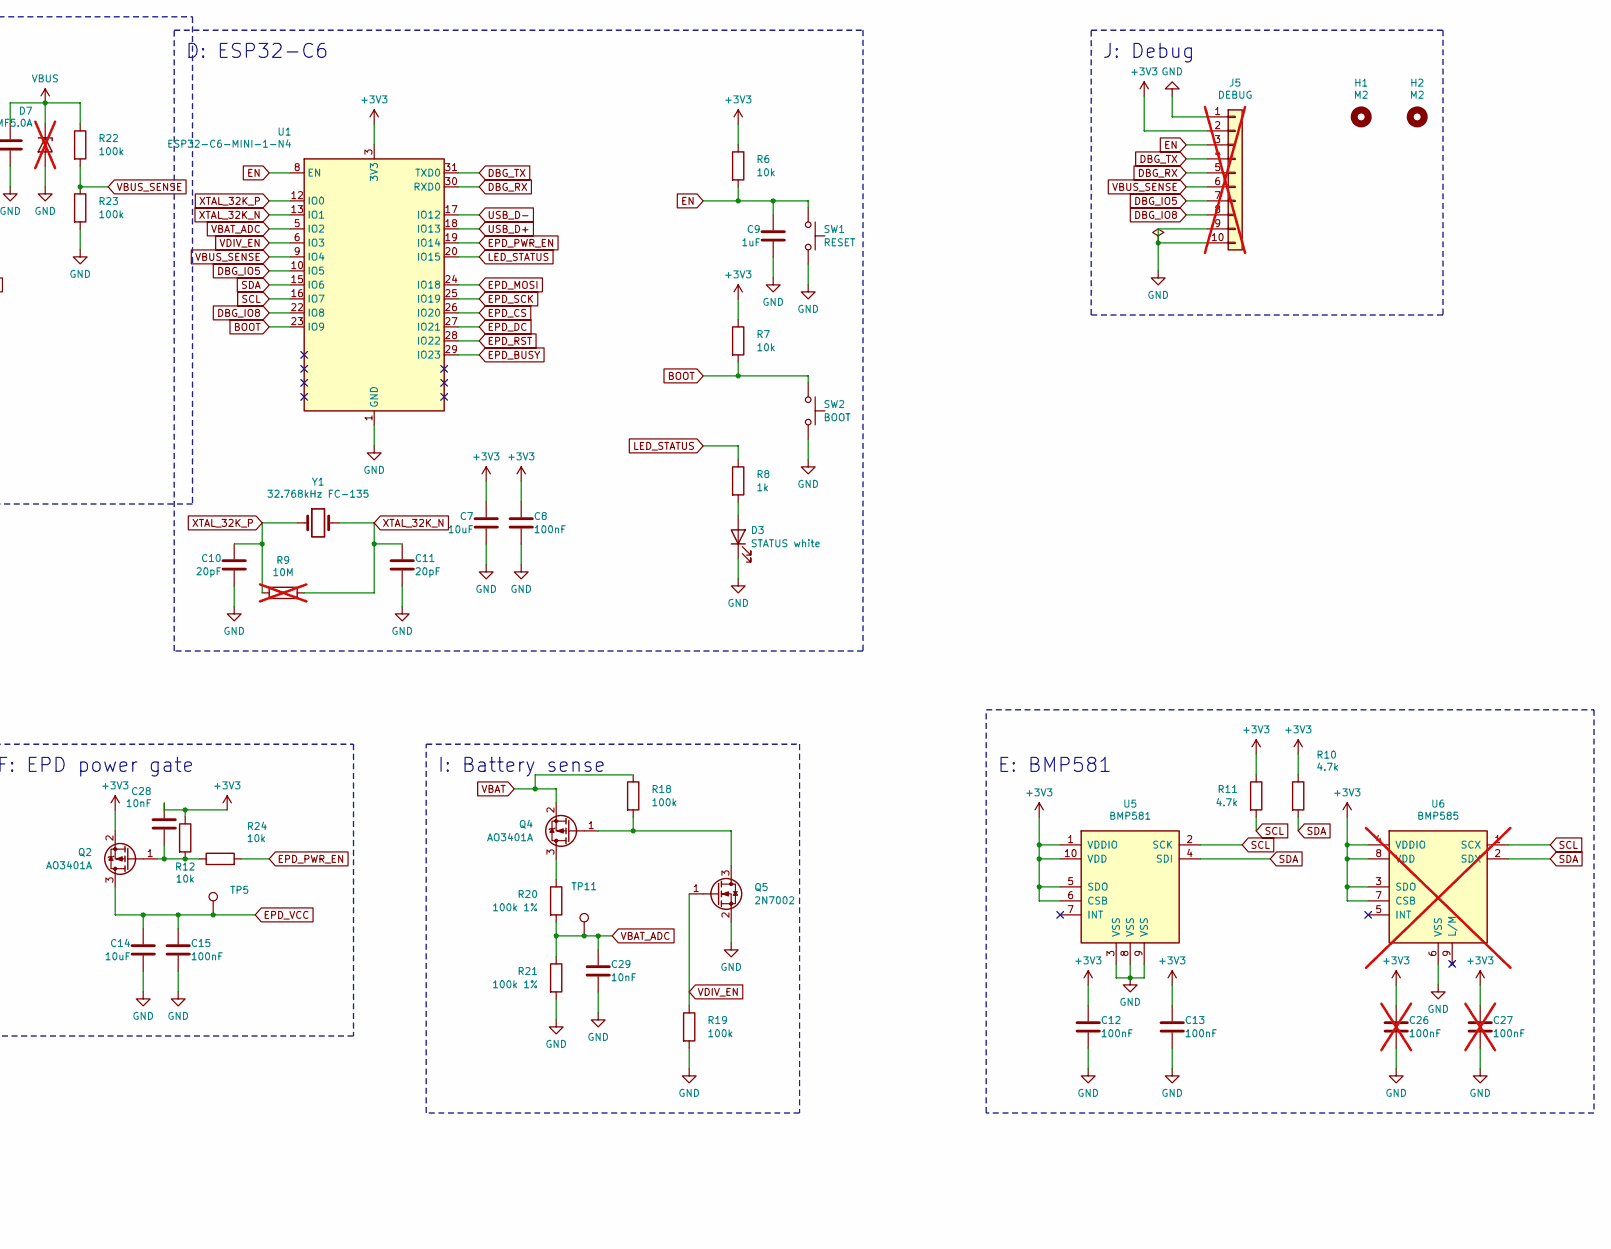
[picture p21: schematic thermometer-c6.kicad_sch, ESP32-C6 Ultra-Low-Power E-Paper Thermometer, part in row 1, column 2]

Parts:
C1, C3, C7, C14: 10uF; C_0603_1608Metric; LCSC C19702
C2: 22uF/25V; C_0805_2012Metric; LCSC C45783
C4, C8, C12, C13, C15: 100nF; C_0402_1005Metric; LCSC C1525
C5, C6, C16, C17, C18, C19, C20, C23, C24: 4.7uF/50V; C_0805_2012Metric; LCSC C98192
C9: 1uF; C_0402_1005Metric; LCSC C52923
C10, C11: 20pF; C_0402_1005Metric; LCSC C1554
C21, C22, C25: 1uF/50V; C_0805_2012Metric; LCSC C28323
C26, C27: 100nF; C_0402_1005Metric; LCSC C1525; not fitted
C28, C29: 10nF; C_0402_1005Metric; LCSC C15195
D1: CHG red; LED_0603_1608Metric; LCSC C2286
D2: SS14; D_SMA; LCSC C2480
D3: STATUS white; LED_0603_1608Metric; LCSC C2290
D4, D5, D6: MBR0530; D_SOD-123; LCSC C5204746
D7: SMF5.0A; D_SOD-123F; not fitted
H1, H2: M2; MountingHole_2.2mm_M2
J1: JST-PH-2 BAT; JST_PH_S2B-PH-SM4-TB_1x02-1MP_P2.00mm_Horizontal; LCSC C295747
J2: MEAS_HDR; PinHeader_1x02_P2.54mm_Vertical; not fitted
J3: USB-C; USB_C_Receptacle_HRO_TYPE-C-31-M-12; LCSC C165948
J4: EPD FPC24 0.5mm; XUNPU_FPC-05FB-24PH20; LCSC C2856831
J5: DEBUG; PinHeader_2x05_P2.54mm_Vertical; not fitted
JP1: MEAS; SolderJumper-2_P1.3mm_Bridged_RoundedPad1.0x1.5mm
JP2: 0.47R; SolderJumper-2_P1.3mm_Bridged_RoundedPad1.0x1.5mm
JP3: 2.2R; SolderJumper-2_P1.3mm_Open_RoundedPad1.0x1.5mm
JP4: 3R; SolderJumper-2_P1.3mm_Open_RoundedPad1.0x1.5mm
JP5: L 10uH; SolderJumper-2_P1.3mm_Bridged_RoundedPad1.0x1.5mm
JP6: L 47uH; SolderJumper-2_P1.3mm_Open_RoundedPad1.0x1.5mm
L1: 10uH SWPA4030S; L_Sunlord_SWPA4030S; LCSC C38117
L2: 47uH SWPA4030S; L_Sunlord_SWPA4030S; LCSC C54731
Q1, Q2, Q4, Q6: AO3401A; SOT-23; LCSC C15127
Q3: Si1308EDL; SOT-323_SC-70; LCSC C469327
Q5: 2N7002; SOT-23; LCSC C8545
R1, R2: 5.1k; R_0402_1005Metric; LCSC C25905
R3, R6, R7, R12, R13, R17, R24: 10k; R_0402_1005Metric; LCSC C25744
R4, R8: 1k; R_0402_1005Metric; LCSC C11702
R5, R18, R19, R22, R23: 100k; R_0402_1005Metric; LCSC C25741
R9: 10M; R_0402_1005Metric; not fitted
R10, R11: 4.7k; R_0402_1005Metric; LCSC C25900
R14: 0.47R 1%; R_0805_2012Metric; LCSC C2930220
R15: 2.2R 1%; R_0805_2012Metric; LCSC C17521
R16: 3.0R 1%; R_0805_2012Metric; LCSC C17660
R20, R21: 100k 1%; R_0402_1005Metric; LCSC C25741
SW1: RESET; SW_TS-1187A; LCSC C318884
SW2: BOOT; SW_TS-1187A; LCSC C318884
TP1: VBAT; TestPoint_Pad_D1.5mm
TP2, TP3: GND; TestPoint_Pad_D1.5mm
TP4: 3V3; TestPoint_Pad_D1.5mm
TP5: EPD_VCC; TestPoint_Pad_D1.5mm
TP6: PREVGH; TestPoint_Pad_D1.5mm
TP7: PREVGL; TestPoint_Pad_D1.5mm
TP8: GDR; TestPoint_Pad_D1.5mm
TP9: RESE; TestPoint_Pad_D1.5mm
TP10: VCOM; TestPoint_Pad_D1.5mm
TP11: VBAT_ADC; TestPoint_Pad_D1.5mm
U1: ESP32-C6-MINI-1-N4; ESP32-C6-MINI-1; LCSC C5736265
U2: RT9080-33GJ5; TSOT-23-5; LCSC C841192
U3: USBLC6-2SC6; SOT-23-6; LCSC C7519
U4: MCP73831-2; SOT-23-5; LCSC C424093
U5: BMP581; Bosch_LGA-10_2x2mm; LCSC C5362283
U6: BMP585; Bosch_LGA-9_3.25x3.25mm; LCSC C18184976; not fitted
Y1: 32.768kHz FC-135; Crystal_SMD_3215-2Pin_3.2x1.5mm; LCSC C32346

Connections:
+3V3: C3.1, C4.1, C7.1, C8.1, C12.1, C13.1, C26.1, C27.1, C28.1, J5.2, Q2.2 (S), R6.1, R7.1, R10.1, R11.1, R12.1, TP4.1, U1.3 (3V3), U2.5 (VOUT), U5.1 (VDDIO), U5.5 (SDO), U5.6 (CSB), U5.10 (VDD), U6.3 (SDO), U6.4 (VDDIO), U6.7 (CSB), U6.8 (VDD)
BOOT: R7.2, SW2.1, U1.23 (IO9)
CHG_STAT: D1.1 (K), U4.1 (STAT)
DBG_IO5: J5.7, U1.10 (IO5)
DBG_IO8: J5.8, U1.22 (IO8)
DBG_RX: J5.5, U1.30 (RXD0)
DBG_TX: J5.4, U1.31 (TXD0)
EN: C9.1, J5.3, R6.2, SW1.1, U1.8 (EN)
EPD_BUSY: J4.9, U1.29 (IO23)
EPD_CS: J4.12, U1.26 (IO20)
EPD_DC: J4.11, U1.27 (IO21)
EPD_GDR: J4.2, Q3.1 (G), R13.1, TP8.1
EPD_MOSI: J4.14, U1.24 (IO18)
EPD_PREVGH: C17.1, D4.1 (K), J4.21, TP6.1
EPD_PREVGL: C18.1, D6.2 (A), J4.23, TP7.1
EPD_PWR_EN: R24.2, U1.19 (IO14)
EPD_RESE: J4.3, Q3.2 (S), R14.1, R15.1, R16.1, TP9.1
EPD_RST: J4.10, R17.2, U1.28 (IO22)
EPD_SCK: J4.13, U1.25 (IO19)
EPD_SW: C16.1, D4.2 (A), JP5.2 (B), JP6.2 (B), Q3.3 (D)
EPD_VCC: C14.1, C15.1, J4.15, J4.16, L1.1, L2.1, Q2.3 (D), R17.1, TP5.1
GND: C1.2, C2.2, C3.2, C4.2, C5.2, C6.2, C7.2, C8.2, C9.2, C10.2, C11.2, C12.2, C13.2, C14.2, C15.2, C17.2, C18.2, C19.2, C20.2, C21.2, C22.2, C23.2, C24.2, C25.2, C26.2, C27.2, C29.2, D3.1 (K), D5.1 (K), D7.2 (A), J1.2, J3.A1 (GND), J3.A12 (GND), J3.B1 (GND), J3.B12 (GND), J3.SH (SHIELD), J4.8, J4.17, J5.1, J5.9, J5.10, JP2.2 (B), JP3.2 (B), JP4.2 (B), Q5.2 (S), Q6.1 (G), R1.2, R2.2, R3.2, R5.2, R13.2, R19.2, R21.2, R23.2, SW1.2, SW2.2, TP2.1, TP3.1, U1.1 (GND), U1.2 (GND), U1.11 (GND), U1.14 (GND), U1.36 (GND), U1.37 (GND), U1.38 (GND), U1.39 (GND), U1.40 (GND), U1.41 (GND), U1.42 (GND), U1.43 (GND), U1.44 (GND), U1.45 (GND), U1.46 (GND), U1.47 (GND), U1.48 (GND), U1.49 (GND), U1.50 (GND), U1.51 (GND), U1.52 (GND), U1.53 (GND), U2.2 (GND), U3.2 (GND), U4.2 (V_{SS}), U5.3 (VSS), U5.8 (VSS), U5.9 (VSS), U6.6 (VSS)
LED_STATUS: R8.1, U1.20 (IO15)
unnamed: D1.2 (A), R4.2
unnamed: D3.2 (A), R8.2
unnamed: C16.2, D5.2 (A), D6.1 (K)
unnamed: J1.1, Q6.3 (D)
unnamed: J2.1, JP1.1 (A), Q6.2 (S)
unnamed: J3.A5 (CC1), R1.1
unnamed: J3.B5 (CC2), R2.1
unnamed: J3.A6 (D+), J3.B6 (D+), U3.3 (I/O2)
unnamed: J3.A7 (D-), J3.B7 (D-), U3.1 (I/O1)
unnamed: C19.1, J4.4
unnamed: C20.1, J4.5
unnamed: C21.1, J4.18
unnamed: C22.1, J4.19
unnamed: C23.1, J4.20
unnamed: C24.1, J4.22
unnamed: C25.1, J4.24, TP10.1
unnamed: JP2.1 (A), R14.2
unnamed: JP3.1 (A), R15.2
unnamed: JP4.1 (A), R16.2
unnamed: JP5.1 (A), L1.2
unnamed: JP6.1 (A), L2.2
unnamed: C28.2, Q2.1 (G), R12.2, R24.1
unnamed: Q4.3 (D), R20.1
unnamed: Q4.1 (G), Q5.3 (D), R18.2
unnamed: R3.1, U4.5 (PROG)
SCL: R11.2, U1.16 (IO7), U5.2 (SCK), U6.1 (SCX)
SDA: R10.2, U1.15 (IO6), U5.4 (SDI), U6.2 (SDX)
USB_D+: U1.18 (IO13), U3.4 (I/O2)
USB_D-: U1.17 (IO12), U3.6 (I/O1)
VBAT: C6.1, J2.2, JP1.2 (B), Q1.3 (D), Q4.2 (S), R18.1, TP1.1, U4.3 (V_{BAT})
VBAT_ADC: C29.1, R20.2, R21.1, TP11.1, U1.5 (IO2)
VBUS: C5.1, D2.2 (A), D7.1 (K), J3.A4 (VBUS), J3.A9 (VBUS), J3.B4 (VBUS), J3.B9 (VBUS), Q1.1 (G), R4.1, R5.1, R22.1, U3.5 (VBUS), U4.4 (V_{DD})
VBUS_SENSE: J5.6, R22.2, R23.1, U1.9 (IO4)
VDIV_EN: Q5.1 (G), R19.1, U1.6 (IO3)
VSYS: C1.1, C2.1, D2.1 (K), Q1.2 (S), U2.1 (VIN), U2.3 (EN)
XTAL_32K_N: C11.1, R9.2, U1.13 (IO1), Y1.2
XTAL_32K_P: C10.1, R9.1, U1.12 (IO0), Y1.1

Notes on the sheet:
A: Battery + PPK2 break
B: 3V3 LDO
C: USB-C + charger
D: ESP32-C6
J: Debug
G: EPD booster
H: EPD FPC
F: EPD power gate
I: Battery sense
E: BMP581

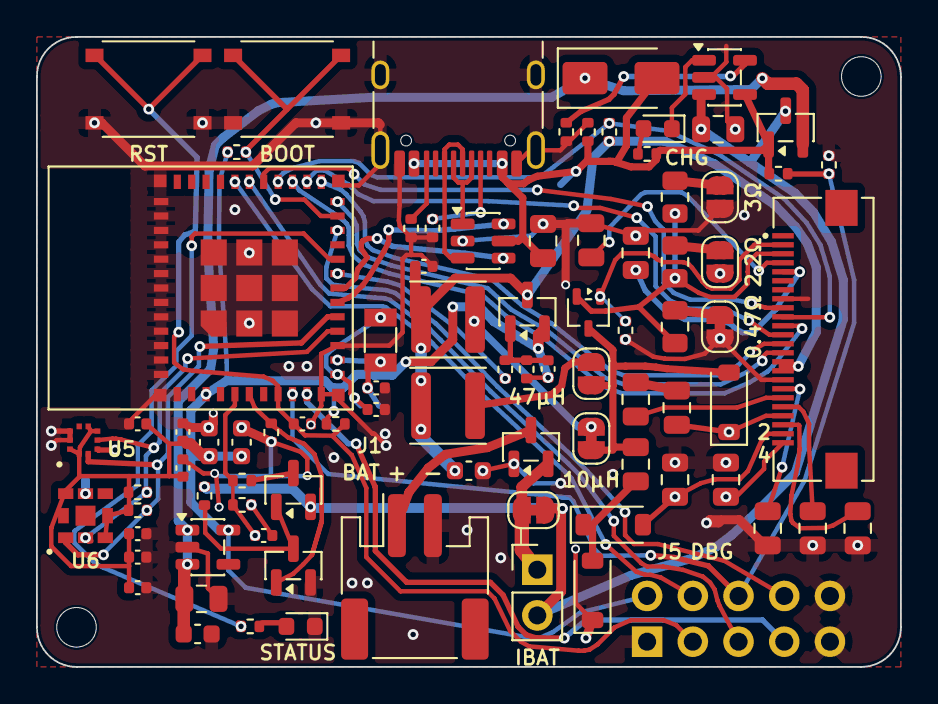
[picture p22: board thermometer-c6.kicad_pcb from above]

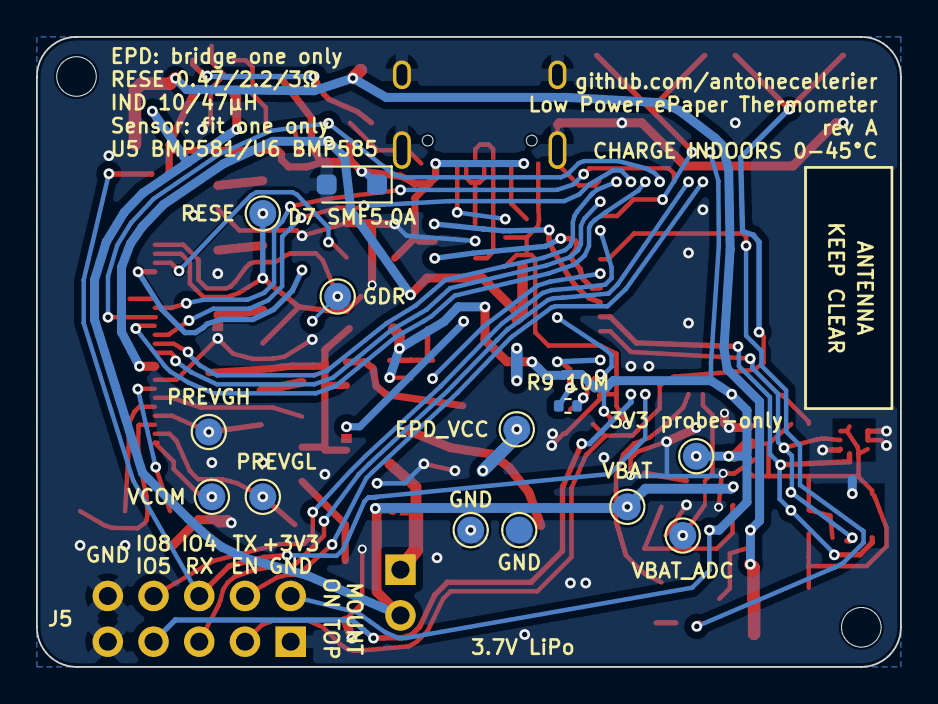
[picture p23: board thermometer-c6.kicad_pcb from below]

Board: 2 copper layers, 48.0 x 35.0 mm, 101 parts (13 on the bottom side), 60 nets.

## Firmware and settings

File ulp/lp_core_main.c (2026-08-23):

// LP core program for ESP32-C6
//
// __riscv guard: PlatformIO's espidf builder feeds every file in ulp/ to the
// active ULP toolchain. On the ESP32-E that is the FSM assembler (HULP builds
// its program at runtime instead — see src/UlpProgram*.cpp), so this file must
// preprocess to nothing there.
#ifdef __riscv
// Sensor implementations are in separate headers, selected at compile time.
// The LP core build does NOT inherit the main project's build_flags, but a
// relative #include reaches the generated rig selector, so the mode derives
// from the same USE_* the HP build uses — they can't disagree. The rig header
// rather than device-config.h: the sensor is all this needs, and it keeps the
// WiFi credentials out of the LP translation unit.
//
// Modes:
//   LP_CORE_IDLE     — power measurement: no I2C, wakes main CPU every N loops
//   LP_CORE_BMP390L  — BMP390L temperature polling via LP I2C
//   LP_CORE_BMP58X   — BMP58x (BMP581/BMP585) temperature polling via LP I2C
//
// Uncomment to override the sensor selection for power measurements:
//#define LP_CORE_IDLE

#include "../include/generated/rig_config.h"
#ifndef LP_CORE_IDLE
#if defined(USE_BMP58x)
#define LP_CORE_BMP58X
#elif defined(USE_BMP390L)
#define LP_CORE_BMP390L
#else
#define LP_CORE_IDLE // no ULP-capable sensor selected; binary embedded but never loaded
#endif
#endif

#include <stdint.h>
#include "ulp_lp_core_utils.h"

// Shared variables — accessible from main CPU via ulp_ prefixed symbols
volatile uint32_t temp_raw_0 = 0;
volatile uint32_t temp_raw_1 = 0;
volatile uint32_t temp_raw_2 = 0;
volatile uint32_t prev_temp_msb = 0;   // BMP390L path (single-byte reference; TODO: byte-wrap bug)
volatile float    prev_temp_c = 0.0f;  // BMP58x path (full °C, no byte-wrap issues)
volatile uint32_t wake_reason = 0;     // 0=none, 1=temp change, 2=I2C error
volatile uint32_t sample_count = 0;    // reset by HP each wake
volatile uint32_t lp_wake_count = 0;   // cumulative; HP reads for lp/hp ratio diagnostic
volatile uint32_t lp_error_count = 0;  // cumulative I2C / sensor failures
volatile int32_t  last_lp_error = 0;   // most recent esp_err_t from a failed LP op
// Identifies which step of the LP routine failed (0 = none yet):
//   1 = trigger / command write   2 = data read
volatile uint32_t last_lp_op    = 0;

// The three sensor programs live inline below rather than in ulp/lp_core_*.h.
// They are not headers in any useful sense — each is one int main() with a
// single includer — and as headers they were invisible to the build: the LP
// sub-build's object is keyed on this file's content, so editing one of them
// rebuilt nothing and the previously built ulp_main.bin was embedded again.
// Measured 2026-08-23, after an experiment arm was flashed with the wrong wake
// cadence while the panel badge, the ULP word count and the baked git hash all
// reported success. Keeping them here means a sensor edit changes this file.
//
// They also all reach into the shared state defined above, so splitting them
// into real .c files would need a header of extern declarations — which would
// be stale-able in precisely the same way. See .claude/rules/ulp.md.

#if defined(LP_CORE_IDLE)

// LP core idle mode: no I2C, wakes main CPU every N loops.
// Used for power measurement testing without sensor hardware.

#define WAKE_EVERY 6

int main(void)
{
    sample_count++;
    lp_wake_count++;

    // Simulate sensor read time (~7ms like BMP390L)
    ulp_lp_core_delay_us(7000);

    // Wake main CPU every N loops
    if ((sample_count % WAKE_EVERY) == 0) {
        // Alternate fake temperature to trigger delta detection
        temp_raw_1 = (sample_count / WAKE_EVERY) & 1 ? 0x80 : 0x60;
        wake_reason = 1;
        ulp_lp_core_wakeup_main_processor();
    }

    return 0;
}

#elif defined(LP_CORE_BMP390L)

// LP core BMP390L temperature polling via hardware LP I2C.
// Raw temperature bytes require compensation on the main CPU.

#include "ulp_lp_core_i2c.h"

#define BMP390L_I2C_ADDR     0x77
#define BMP390L_REG_PWR_CTRL 0x1B
#define BMP390L_REG_TEMP_0   0x07
#define BMP390L_FORCED_MODE  0x13

#define LP_I2C_TIMEOUT_CYCLES  5000
#define TEMP_DELTA_THRESHOLD   20   // ~0.1°C (each DATA_1 count ≈ 0.005°C)

int main(void)
{
    esp_err_t ret;
    lp_wake_count++;

    // 1. Trigger forced-mode measurement
    uint8_t pwr_ctrl_cmd[2] = {BMP390L_REG_PWR_CTRL, BMP390L_FORCED_MODE};
    ret = lp_core_i2c_master_write_to_device(LP_I2C_NUM_0, BMP390L_I2C_ADDR,
                                              pwr_ctrl_cmd, 2, LP_I2C_TIMEOUT_CYCLES);
    if (ret != ESP_OK) {
        last_lp_error = ret;
        last_lp_op = 1;  // trigger write
        lp_error_count++;
        wake_reason = 2;
        ulp_lp_core_wakeup_main_processor();
        return 0;
    }

    // 2. Wait ~7ms for conversion
    ulp_lp_core_delay_us(7000);

    // 3. Read 3 raw temperature bytes (DATA_0, DATA_1, DATA_2 are contiguous)
    uint8_t reg_addr = BMP390L_REG_TEMP_0;
    uint8_t data[3];
    ret = lp_core_i2c_master_write_read_device(LP_I2C_NUM_0, BMP390L_I2C_ADDR,
                                                &reg_addr, 1, data, 3,
                                                LP_I2C_TIMEOUT_CYCLES);
    if (ret != ESP_OK) {
        last_lp_error = ret;
        last_lp_op = 2;  // data read
        lp_error_count++;
        wake_reason = 2;
        ulp_lp_core_wakeup_main_processor();
        return 0;
    }

    // 4. Store raw temperature
    temp_raw_0 = data[0];
    temp_raw_1 = data[1];
    temp_raw_2 = data[2];
    sample_count++;

    // 5. Delta comparison on DATA_1 byte (~0.005°C resolution per count).
    // TODO: byte-wise compare wraps at ~1.28°C intervals. BMP390L raw needs
    // compensation before comparing in °C (unlike BMP58x). Fix once BMP390L
    // is re-enabled on C6.
    uint32_t current_msb = data[1];
    int32_t delta = (int32_t)current_msb - (int32_t)prev_temp_msb;
    if (delta < 0) delta = -delta;

    if (delta >= TEMP_DELTA_THRESHOLD) {
        prev_temp_msb = current_msb;
        wake_reason = 1;
        ulp_lp_core_wakeup_main_processor();
    }

    return 0;
}

#elif defined(LP_CORE_BMP58X)

// LP core BMP58x (BMP581/BMP585) temperature polling via hardware LP I2C.
// BMP58x output is already compensated — no NVM calibration needed.
// OSR_CONFIG is written once by the main CPU in Initialize(); this loop only
// triggers forced-mode measurements.

#include "ulp_lp_core_i2c.h"

#define BMP58X_I2C_ADDR       0x47
#define BMP58X_REG_ODR_CONFIG 0x37
#define BMP58X_REG_TEMP_XLSB  0x1D

#define LP_I2C_TIMEOUT_CYCLES  5000
// Wake HP when temperature has moved this far from the last reference.
// Overridable so a bench build can decouple the wake cadence from the room: 0
// wakes on every poll (the LP-core counterpart of ULP_ALWAYS_WAKE), a large
// value never wakes on delta and leaves the safety net as the only wake source.
#ifndef TEMP_DELTA_THRESHOLD_C
#define TEMP_DELTA_THRESHOLD_C 0.1f
#endif

int main(void)
{
    esp_err_t ret;

    // Counter reflects every wake attempt, so it increments even when an I2C
    // failure later short-circuits to wake_reason = 2.
    lp_wake_count++;

    // 1. Trigger forced-mode measurement (pwr_mode = BMP5_POWERMODE_FORCED)
    uint8_t odr_cmd[2] = {BMP58X_REG_ODR_CONFIG, 0x02};
    ret = lp_core_i2c_master_write_to_device(LP_I2C_NUM_0, BMP58X_I2C_ADDR,
                                              odr_cmd, 2, LP_I2C_TIMEOUT_CYCLES);
    if (ret != ESP_OK) {
        last_lp_error = ret;
        last_lp_op = 1;  // trigger write
        lp_error_count++;
        wake_reason = 2;
        ulp_lp_core_wakeup_main_processor();
        return 0;
    }

    // 2. Wait ~2ms for conversion (1x OSR, ~1.6ms typical)
    ulp_lp_core_delay_us(3000);

    // 3. Read 3 temperature bytes (XLSB, LSB, MSB are contiguous from 0x1D)
    uint8_t reg_addr = BMP58X_REG_TEMP_XLSB;
    uint8_t data[3];
    ret = lp_core_i2c_master_write_read_device(LP_I2C_NUM_0, BMP58X_I2C_ADDR,
                                                &reg_addr, 1, data, 3,
                                                LP_I2C_TIMEOUT_CYCLES);
    if (ret != ESP_OK) {
        last_lp_error = ret;
        last_lp_op = 2;  // data read
        lp_error_count++;
        wake_reason = 2;
        ulp_lp_core_wakeup_main_processor();
        return 0;
    }

    // 4. Store raw temperature
    temp_raw_0 = data[0];
    temp_raw_1 = data[1];
    temp_raw_2 = data[2];
    sample_count++;

    // 5. Delta comparison in °C. BMP58x output is already compensated:
    // 24-bit signed, 1/65536 °C per LSB. Avoid byte-wise compare (wraps at
    // every whole-degree boundary and spuriously wakes HP).
    int32_t raw = ((int32_t)data[2] << 16) | ((int32_t)data[1] << 8) | data[0];
    if (raw & 0x800000) raw |= 0xFF000000;  // sign-extend 24→32
    float current_c = (float)raw / 65536.0f;

    float delta = current_c - prev_temp_c;
    if (delta < 0.0f) delta = -delta;

    if (delta >= TEMP_DELTA_THRESHOLD_C) {
        prev_temp_c = current_c;
        wake_reason = 1;
        ulp_lp_core_wakeup_main_processor();
    }

    return 0;
}

#else

#error "No LP core mode selected — define LP_CORE_IDLE, LP_CORE_BMP390L, or LP_CORE_BMP58X"

#endif

#endif // __riscv

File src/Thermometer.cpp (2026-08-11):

#include "app_common.h"
#include "git_hash.h"

// needed for setenv and tzset :-/
#undef __STRICT_ANSI__
#include "time.h"
#include "stdlib.h"

#include "esp_sleep.h"
#include "esp_log.h"
#include "esp_system.h"  // esp_reset_reason
#include "esp_adc/adc_oneshot.h"
#include "esp_adc/adc_cali.h"
#include "esp_adc/adc_cali_scheme.h"
#include <math.h>
#include <string.h>
#ifdef CONFIG_ESP_COREDUMP_ENABLE_TO_FLASH
#include "esp_core_dump.h"
#endif
#ifndef DISABLE_WIFI
#include "esp_wifi.h"
#include "esp_mac.h"   // esp_efuse_mac_get_default, for the DHCP hostname
#include "esp_netif.h"
#include "esp_netif_sntp.h"
#include "esp_event.h"
#include "nvs_flash.h"
#include "freertos/event_groups.h"
#endif

#include "Display.h"
#include "TempHistory.h"
#include "RtcHistory.h"
#include "HistoryStore.h"

// Used for JTAG. Avoid for other purposes if possible
// Firebeetle Pin | JTAG PIN
//            12  |  TDI
//            13  |  TCK
//            14  |  TMS
//            15  |  TDO
// JTAG init and deep sleep don't seem to play well together
// openocd errors when trying to init JTAG during deep sleep:
//   Error: JTAG scan chain interrogation failed: all ones
//   Error: Check JTAG interface, timings, target power, etc.
//   Error: Trying to use configured scan chain anyway...
//   Error: esp32.cpu0: IR capture error; saw 0x1f not 0x01
// when that error is hit you might need to kill the openocd process even if debugging is stopped in VS code
// Repro cmd
// ~/.platformio/packages/tool-openocd-esp32/bin/openocd -s ~/.platformio/packages/tool-openocd-esp32 -c "gdb_port pipe; tcl_port disabled; telnet_port disabled" -s ~/.platformio/packages/tool-openocd-esp32/share/openocd/scripts -f interface/ftdi/esp32_devkitj_v1.cfg -f board/esp-wroom-32.cfg -c "adapter_khz 5000"

#if defined(USE_DS18B20_PAR)
  #include "sensors/DS18B20Sensor.hpp"
  DS18B20Sensor sensor;
#elif defined(USE_BMP390L)
  #include "sensors/BMP390LSensor.hpp"
  BMP390LSensor sensor;
#elif defined(USE_BMP58x)
  #include "sensors/BMP58xSensor.hpp"
  BMP58xSensor sensor;
#elif defined(USE_DUMMY_SENSOR)
  #include "sensors/DummySensor.hpp"
  DummySensor sensor;
#else
  #error "Unknown sensor type"
#endif

#if defined(HAS_ULP_SUPPORT) && defined(SOC_ULP_FSM_SUPPORTED)
void ulp_check_data_overlap();
#endif

#if defined(HAS_ULP_SUPPORT) && defined(SOC_LP_CORE_SUPPORTED) && SOC_LP_CORE_SUPPORTED
#include "ulp_main.h"  // exposes ulp_lp_wake_count and other LP-core globals
#endif

// The wake cycle lives next to setup(), where the sequence reads in the order a
// boot performs it.
static void begin_wake_cycle(void);
static void run_wake_cycle(bool ulp_sample_available);
bool vbus_present();

#ifdef HAS_USB_SERVICE_WINDOW
#include "driver/usb_serial_jtag.h"  // usb_serial_jtag_is_connected()
static void usb_service_window(void);
#endif

// --- RTC memory layout ---
// RTC memory survives deep sleep but NOT power-on reset (firmware upload,
// battery swap, reset button). More precisely: the bootloader reloads
// .rtc.data and startup zeroes .rtc.bss on ANY reset that isn't a deep-sleep
// wake (esp_image_format.c / cpu_start.c) — so RTC_DATA_ATTR state, including
// boot_count and all history, does not survive a panic/WDT/brownout reset
// either. .rtc_noinit is exempt from both, which is what CrashLog (below)
// relies on; it dies only with the RTC power domain (battery swap, or the
// FireBeetle's reset button, whose circuit power-cycles RTC).
//
// The history itself outlives all of that: HistoryStore mirrors it to the
// `history` flash partition, which an upload does not touch. What lands here on
// a cold boot is a restore from flash, not an empty buffer.
//
// RtcHistory, RTC_HISTORY_VERSION and the self_addr scheme live in
// include/RtcHistory.h so HistoryStore.cpp can serialize the same layout.
// Bump RTC_STATE_VERSION when changing operational state variables below.
#define RTC_STATE_VERSION   0xDA050009

// Initial min/max temperature sentinels (float).
// Any real reading will replace these on first comparison.
#define TEMP_INIT_MIN  999.0f
#define TEMP_INIT_MAX (-999.0f)

// Minimum temperature change (C) to trigger a display refresh.
// Overridable so a bench build can decouple the refresh cadence from the room:
// set it past any real swing and REFRESH_EVERY_N_WAKES becomes the only
// temperature-independent repaint source.
#ifdef DISPLAY_TEMP_DELTA
// Already defined means a build override is in force. Flagged so the panel can
// say so: refresh cadence is the dominant term in the power budget, and a build
// that decouples it from the room renders identically to production.
#define DISPLAY_TEMP_DELTA_OVERRIDDEN 1
#else
#define DISPLAY_TEMP_DELTA 0.1f
#endif

RTC_DATA_ATTR RtcHistory historical_data;

// Operational state — changes here are caught by self_addr if the linker
// shifts historical_data, and by RTC_STATE_VERSION for format changes.
RTC_DATA_ATTR uint32_t rtc_state_version = 0;

RTC_DATA_ATTR int boot_count = 0;
RTC_DATA_ATTR int display_refresh_count = 0;

// InitializeUlp() calls this power cycle. Healthy value is exactly 1 (first
// boot); anything higher means ULP/LP state (wake counters, delta reference)
// is being wiped in the field — rendered as "uN" in the footer when > 1.
RTC_DATA_ATTR uint32_t ulp_reinit_count = 0;

// Wakeup cause, cached before anything can light-sleep: esp_sleep reports the
// cause of the MOST RECENT sleep, and the EPD busy-wait light sleep
// (epd_busy_light_sleep) replaces the deep-sleep cause with its GPIO wake.
// Querying live after a display refresh misread every refresh boot as a fresh
// boot and reloaded the LP core each time (wiping its counters and delta
// reference). Always use these, never app_wakeup_cause(), past setup() entry.
static esp_sleep_wakeup_cause_t s_wake_cause = ESP_SLEEP_WAKEUP_UNDEFINED;
static uint32_t s_wake_causes_raw = 0;
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

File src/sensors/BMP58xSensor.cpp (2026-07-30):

#include "sensors/BMP58xSensor.hpp"
#include "app_common.h"

#include <math.h>

// BMP58x register map
#define BMP58X_I2C_ADDR       0x47
#define BMP58X_REG_CHIP_ID    0x01
#define BMP58X_REG_INT_CONFIG 0x14
#define BMP58X_REG_TEMP_XLSB  0x1D
#define BMP58X_REG_OSR_CONFIG 0x36
#define BMP58X_REG_ODR_CONFIG 0x37

// Chip IDs
#define BMP581_CHIP_ID 0x50
#define BMP585_CHIP_ID 0x51

// OSR_CONFIG: 1x temperature oversampling, pressure disabled
#define BMP58X_OSR_TEMP_1X 0x00
// ODR_CONFIG: forced mode (pwr_mode = BMP5_POWERMODE_FORCED per Bosch bmp5_defs.h)
#define BMP58X_FORCED_MODE 0x02
// INT_CONFIG: int_en=1 + push-pull + active-high + pad_int_drv=0. With no
// sources routed (INT_SOURCE stays 0) the pad is actively parked at its
// inactive level (low) — required on the custom thermometer-c6 board where
// INT is unconnected (hardware/thermometer-c6/README.md bench notes), and
// harmless on breakouts that ground INT (parked low = GND).
#define BMP58X_INT_PARKED 0x0A

// --- ULP FSM path (ESP32 original, HULP bit-bang I2C) ---
#if defined(HAS_ULP_SUPPORT) && defined(SOC_ULP_FSM_SUPPORTED)
#include "UlpProgram.h"
#include "driver/rtc_io.h"
#endif

// --- LP core path (ESP32-C6, hardware LP I2C) ---
#if defined(HAS_ULP_SUPPORT) && defined(SOC_LP_CORE_SUPPORTED) && SOC_LP_CORE_SUPPORTED && defined(USE_BMP58x)
#include "ulp_lp_core.h"
#include "lp_core_i2c.h"
#include "driver/rtc_io.h"  // rtc_gpio_deinit(), to take the pads back from LP I2C
#include "ulp_main.h"

extern const uint8_t ulp_main_bin_start[] asm("_binary_ulp_main_bin_start");
extern const uint8_t ulp_main_bin_end[]   asm("_binary_ulp_main_bin_end");
#endif


BMP58xSensor::BMP58xSensor()
{}

bool BMP58xSensor::ReadRegister(uint8_t reg, uint8_t *buf, size_t len)
{
    return _i2c.readReg(BMP58X_I2C_ADDR, reg, buf, len);
}

bool BMP58xSensor::WriteRegister(uint8_t reg, uint8_t value)
{
    return _i2c.writeReg(BMP58X_I2C_ADDR, reg, value);
}

// BMP58x outputs already-compensated temperature as 24-bit signed, 1/65536 °C per LSB.
//
// Every path converts here — direct read, ULP FSM and LP core — so this is the one
// place that has to recognise a raw code no live sensor produces. Returning the
// sentinel lets the plausibility gate the callers already apply reject it, instead
// of each path needing its own copy of the test.
float BMP58xSensor::RawToTempC(uint8_t xlsb, uint8_t lsb, uint8_t msb)
{
    uint32_t raw = (uint32_t)xlsb | ((uint32_t)lsb << 8) | ((uint32_t)msb << 16);
    if (TEMP_RAW24_IS_BUS_ARTIFACT(raw))
        return TEMP_NO_PREVIOUS;
    if (raw & 0x800000)
        raw |= 0xFF000000; // sign-extend 24→32 bits
    return (int32_t)raw / 65536.0f;
}

void BMP58xSensor::Initialize()
{
    if (_isInitialized)
        return;

    _i2c.begin(I2C_SDA_PIN, I2C_SCL_PIN);
    sleep_ms(5); // BMP58x needs ~2ms after power-up before I2C is ready

    // The chip ID is the only positive evidence that a BMP58x is on the bus, and
    // it is what separates a real measurement from a number an undriven bus
    // produced. A floating SDA yields values that pass every range and artifact
    // test — 0x7F8000 reads as a perfectly formed 127.5 °C — so identity has to
    // gate the reading rather than merely be logged.
    uint8_t chip_id;
    _identified = false;
    bool got_id = ReadRegister(BMP58X_REG_CHIP_ID, &chip_id, 1);

#if defined(HAS_ULP_SUPPORT) && defined(SOC_LP_CORE_SUPPORTED) && SOC_LP_CORE_SUPPORTED && defined(USE_BMP58x)
    if (!got_id)
    {
        // The bus may not be ours. lp_core_i2c_master_init() routes these pads to
        // the LP domain (rtc_gpio_init -> LP_AON_GPIO_MUX_SEL) and that routing
        // lives in the always-on domain, so it outlives a chip reset: after a
        // reflash the first direct read finds no sensor at all, and the frame
        // renders "--.-" on a board whose sensor is fine. rtc_gpio_deinit() is the
        // exact inverse of what LP init did; there is no lp_core_i2c_master_deinit().
        //
        // Only ever reached when a read has already failed, and every path to a
        // direct read has the LP core stopped or never started — so this cannot
        // take the bus away from a coprocessor that is using it. If the pads were
        // not the problem the retry fails too, and the caller still gets the
        // honest "no reading" answer rather than a fabricated one.
        LOGI("Chip ID read failed — reclaiming I2C pads from the LP domain and retrying");
        rtc_gpio_deinit((gpio_num_t)I2C_SDA_PIN);
        rtc_gpio_deinit((gpio_num_t)I2C_SCL_PIN);
        _i2c.begin(I2C_SDA_PIN, I2C_SCL_PIN);
        sleep_ms(5);
        got_id = ReadRegister(BMP58X_REG_CHIP_ID, &chip_id, 1);
    }
#endif

    if (got_id)
    {
        if (chip_id == BMP581_CHIP_ID)
        {
            LOGI("BMP581 detected (chip ID 0x%02x)", chip_id);
            _identified = true;
        }
        else if (chip_id == BMP585_CHIP_ID)
        {
            LOGI("BMP585 detected (chip ID 0x%02x)", chip_id);
            _identified = true;
        }
        else
        {
            LOGI("WARNING: unexpected BMP58x chip ID 0x%02x — not trusting readings",
                 chip_id);
        }
    }
    else
    {
        LOGI("WARNING: failed to read BMP58x chip ID — not trusting readings");
    }

    WriteRegister(BMP58X_REG_OSR_CONFIG, BMP58X_OSR_TEMP_1X);
    WriteRegister(BMP58X_REG_INT_CONFIG, BMP58X_INT_PARKED);

    _isInitialized = true;
}

float BMP58xSensor::GetTemperatureC()
{
    Initialize();

    if (!_identified)
        return TEMP_NO_PREVIOUS;

    // Trigger forced-mode measurement (OSR configured once in Initialize())
    WriteRegister(BMP58X_REG_ODR_CONFIG, BMP58X_FORCED_MODE);
    sleep_ms(3); // conversion ~1.6ms at 1x OSR

    uint8_t data[3];
    if (!ReadRegister(BMP58X_REG_TEMP_XLSB, data, 3))
    {
        // The sentinel, not 0.0f: 0.0 °C is a plausible room temperature, so a
        // failed read returning it is indistinguishable from a real measurement.
        LOGI("ERROR: failed to read BMP58x temperature");
        return TEMP_NO_PREVIOUS;
    }

    return RawToTempC(data[0], data[1], data[2]);
}

bool BMP58xSensor::SupportsUlp()
{
#ifdef HAS_ULP_SUPPORT
    return true;
#else
    return false;
#endif
}

// ============================================================
// InitializeUlp — two implementations, selected at compile time
// ============================================================

#if defined(HAS_ULP_SUPPORT) && defined(SOC_ULP_FSM_SUPPORTED)
// --- ESP32 ULP FSM path (HULP bit-bang I2C) ---
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

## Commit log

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2021-12-05 Fix empty battery screen on 212x104 sreen
    Also adds a max battery mV value for debugging purposes
    [Thermometer.cpp]
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2026-03-06 feat: ULP coprocessor reads BMP390L temperature via bit-bang I2C
    Implement ULP-based temperature monitoring using HULP library's bit-bang
    I2C to poll BMP390L sensor during deep sleep. The main CPU only wakes
    when temperature changes by ≥0.1°C, dramatically reducing wake frequency.
    Key components:
    - ULP program: forced-mode trigger, 7ms wait, 3-byte temp read, delta compare
    - BMP390L compensation: calibration cached in RTC memory, applied on wake
    - Bus recovery: 9 SCL clocks + STOP after Wire.end() prevents stuck bus
    - Fixed ULP_DATA_BASE=200 addressing (workaround for M_MOVL label bug)
    Hardware RTC I2C peripheral could not be made to work (BUS_BUSY stuck);
    see docs/rtc-i2c-research.md f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
    [BMP390LCompensation.cpp, BMP390LSensor.cpp, Thermometer.cpp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]
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2026-03-07 Fix typo, stale define, duplicate pins, and misleading comments
    - Fix DISBALE_WIFI → DISABLE_WIFI typo in WiFi include guard
    (WiFi.h was always included regardless of the flag)
    - Remove stale SRAM_CS comment (now conflicts with EPD_CS on GPIO14)
    - Derive I2C_BB_SCL/SDA from common.h I2C_SCL_PIN/SDA_PIN instead
    of duplicating the pin numbers
    - Fix UlpProgram.h comments: "RTC I2C" → "bit-bang I2C (HULP)"
    (hardware RTC I2C could not be made to work)
    [Thermometer.cpp, UlpProgram.cpp]
2026-03-07 Clean up dead Adafruit display path, fix ULP API, decouple safety net timer
    - Remove dead Adafruit ThinkInk display code path: USE_GXEPD was always
    defined, and the Adafruit path referenced undefined SRAM_CS. Also remove
    #if 0 partial update block and unused Adafruit lib deps from platformio.ini.
    - Remove unused data_offset parameter from ulp_start() — ULP always starts
    at address 0, and callers use ULP_DATA_BASE directly for read/write ops.
    - Replace SLEEP_INTERVAL_S * 60 safety net with dedicated ULP_SAFETY_NET_US
    constant (1 hour). Eliminates confusing dual meaning of SLEEP_INTERVAL_S
    and fixes the log message which relied on a numerical coincidence.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
    [Thermometer.cpp, UlpProgram.cpp]
2026-03-08 Refactor setup() to unify ULP and normal boot paths, fix 0.0°C reads
    Extract refresh_and_sleep() and try_read_ulp_temperature() so both
    wakeup paths share the same display-update / ULP-init / sleep tail.
    Explicitly re-trigger BMP390L forced-mode conversion before each
    readTempC() call — without this the data registers can contain stale
    zeros, producing a spurious 0.0 °C reading.
    [BMP390LSensor.cpp, Thermometer.cpp]
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2026-03-09 Migrate ESP32-E to Arduino Core 3.x (pioarduino / ESP-IDF 5.x)
    Both ESP32-E and Xiao ESP32C6 now share the same pioarduino platform,
    eliminating the version split between Arduino Core 2.x and 3.x.
    Changes required for Core 3.x compatibility:
    - Replace FastLED with Adafruit NeoPixel to avoid legacy RMT/ADC/touch
    driver conflicts at static init (only 1 status LED is used)
    - Replace touchRead() with digitalRead()+INPUT_PULLUP for button detection
    (avoids legacy vs new touch driver conflict)
    - Replace ESP_PD_DOMAIN_MAX loop with explicit domain list (ESP-IDF 5.x
    added new power domains)
    - Use HULP fork with ADC code gated behind HULP_USE_ADC to avoid legacy
    ADC driver conflict (we only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
    [Thermometer.cpp]
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2026-03-11 Refactor LP core build to use framework-espidf, add DummySensor ULP support
    Major changes:
    - Replace auto-download of ESP-IDF sources with framework-espidf package
    - Move generated headers to .pio/lp_core_build/generated/ (was include/generated/)
    - Patch memory.ld to reserve LP SRAM (pioarduino bug workaround)
    - Add DummySensor LP core support (idle mode for power testing)
    - Refactor LP core main into lp_core_main.c with idle/BMP390L modes
    - Use LP interrupt path for timer (lp_timer_ll_clear_lp_alarm_intr_status)
    - Remove HP_CPU trigger — LP core waits for first LP timer alarm
    - Remove timer safety net from deep sleep (ULP wakeup only)
    - Document USB CDC power issue and C6 power measuremen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
    [BMP390LSensor.cpp, Thermometer.cpp, lp_core_main.c]
2026-03-11 Migrate C6 LP core build to platform fork, remove custom build system
    Replace the custom LP core build script and loader with the platform
    fork's auto-configured ULP support. The fork (feature/lp-core-ulp-arduino)
    auto-detects ulp/, handles sdkconfig injection, memory.ld patching,
    binary embedding, and provides libulp.a with standard ESP-IDF APIs.
    Deleted:
    - scripts/build_lp_core.py (369-line custom build script)
    - src/LpCoreProgram.cpp (187-line custom loader)
    - include/LpCoreProgram.h
    - ulp/sdkconfig.h (platform auto-generates)
    Changed:
    - BMP390LSensor.cpp, DummySensor.cpp: use standard ESP-IDF APIs
    (ulp_lp_core_load_binary, ulp_lp_core_run, lp_core_i2c_master_init)
    - platformio.ini: C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
    [BMP390LSensor.cpp]
2026-03-22 Add support for three new GooDisplay e-paper displays
    - GDEW029I6FD: 2.9" flexible B/W (296x128, UC8151D)
    - GDEM0154I61: 1.54" flexible B/W (200x200, SSD1681 via GDEY0154D67 compat driver)
    - GDEH0576T81: 5.76" HD B/W (920x680, SSD2677, custom GxEPD2 driver fork)
    The 5.76" display buffer (78KB) is heap-allocated since it overflows
    static BSS, and uses TEXT_SCALE 6x for readable text on the large panel.
    Paged rendering is not supported by the SSD2677 controller.
    Also switches GxEPD2 to fork with GDEH0576T81 driver, and fixes
    BMP390LSensor.hpp include order so NO_ULP is visible before the
    HAS_ULP_SUPPORT check.
    [Display.cpp]
2026-03-22 Redesign e-paper display with dashboard layout and trend charts
    Replace the text-only CP437 display with a modern dashboard:
    - Large temperature reading (80pt native font on big displays, no aliasing)
    - 24h Catmull-Rom sparkline with adaptive gridlines and hour labels
    - 30-day min/avg/max spline curves replacing the old bar chart
    - Battery icon with fill level, compact info bar, debug footer
    - Responsive layout: landscape (296x128, 212x104) vs stacked (200x200, 920x680)
    Architecture:
    - Extract rendering into DisplayRenderer.cpp shared by device and simulator
    - render_dashboard() takes Adafruit_GFX& — same code renders to GxEPD2 or GFXcanvas1
    - Mock data in MockData.h shared between device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
    [Display.cpp, Display.h, DisplayRenderer.cpp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]
2026-03-22 Add error indicators, WiFi timeout, and polish status bars
    Error visibility:
    - Add ! NO WIFI, ! NO NTP, ! SENSOR indicators in top-left of temp zone
    - Track wifi_ok, ntp_synced, last_sensor_ok as RTC flags
    - Suppress ! NO WIFI on DISABLE_WIFI builds (deliberate, not an error)
    WiFi timeout fix:
    - Add 15s timeout to WiFi connection loop (was blocking forever)
    - Detect NTP sync failure separately (time still near epoch)
    Display polish:
    - Use FreeSans12pt for all secondary text on large displays (info bar,
    footer, status indicators) — consistent stroke width with chart labels
    - Footer shows "mx" prefix on max battery voltage, boot date includes year
    - Properly center info bar and footer te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
    [Display.cpp, Display.h, DisplayRenderer.cpp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]
2026-03-22 Add build-time font generation for optimal display-specific sizing
    Replace hardcoded font sizes with a build-time system that computes
    the optimal temperature and alert font point sizes from the configured
    display resolution:
    - scripts/generate_font.py wraps Adafruit fontconvert, computes optimal
    pt sizes based on display zone dimensions (height and width constraints),
    generates fonts to include/generated/, and writes font_config.h with
    inline get_temp_font()/get_alert_font() selectors
    - scripts/pre_build_fonts.py hooks into PlatformIO as a pre-build step
    - Device builds include only the fonts for the configured display
    - Simulator generates all display sizes via --all flag
    - Temp fon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
    [DisplayRenderer.cpp]
2026-03-23 Replace daily summaries with hourly resolution for 30-day chart
    Replace the 31-entry DailySummary buffer (min/max per day) with a
    720-entry HourlyEntry buffer (min/max/avg per hour, 30 days × 24h).
    Each hour's entry is accumulated from all wakes (delta-triggered +
    safety-net), finalized with avg=sum/count on hour boundary change.
    Skipped hours are filled with last known value (stable temperature).
    Large displays render all hourly points directly — solid thick avg
    curve with arc-length-dotted min/max envelope showing daily cycles
    and transient events. Small displays derive daily summaries from
    the hourly data at render time.
    Also adds draw_spline_dotted() for true distance-based dot spac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
    [Display.h, DisplayRenderer.cpp, MockData.h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]
2026-03-23 Add mock/dummy sensor indicators and fix sim font regeneration
    Show "! DUMMY" and "! MOCK" in the display's top-left corner when
    USE_DUMMY_SENSOR or MOCK_DISPLAY_DATA are configured, making it easy
    to spot configuration errors on production builds.
    Also fix the simulator Makefile to detect when PlatformIO overwrites
    font_config.h (single-display mode clobbers the --all output), by
    adding font_config.h as a dependency of the font stamp.
    [Display.h, DisplayRenderer.cpp, MockData.h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]
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2026-03-23 Name magic numbers for temperature sentinels and thresholds
    Replace bare 9990/-9990, 999.0f/-999.0f, and 0.1f with named
    constants (TEMP_INIT_MIN_X10, TEMP_INIT_MAX_X10, TEMP_INIT_MIN,
    TEMP_INIT_MAX, DISPLAY_TEMP_DELTA) for clarity and single-point
    maintenance. Deduplicate identical battery threshold definitions.
    [Display.h, DisplayRenderer.cpp, Thermometer.cpp]
2026-03-23 Extract reset_rtc_state() to centralize RTC variable initialization
    The inline reset block in setup() manually assigned 24 RTC globals.
    Extracting to a function makes it easier to keep in sync when adding
    new RTC variables and clarifies the purpose at the call site.
    [Thermometer.cpp]
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2026-03-23 Restore ULP safety-net timer for periodic housekeeping wakeups
    The safety-net timer (1 hour) was accidentally left removed after a
    debugging session in c37b1c6 — it was disabled to test a hypothesis
    about LP timer conflicts, confirmed NOT to be the cause, but never
    restored during cleanup. Without it, the main CPU never wakes for
    housekeeping (daily display clear, battery check) when temperature
    is stable and the ULP doesn't trigger a delta wake.
    Restore esp_sleep_enable_timer_wakeup(ULP_SAFETY_NET_US) alongside
    the ULP wakeup source, matching the original behavior from 4ae9a28.
    [Thermometer.cpp]
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2026-03-23 Extract shared helpers to deduplicate DisplayRenderer
    - File-scope month_abbr[] replaces three identical local arrays
    - pad_y_range() replaces duplicated Y-range padding in sparkline and monthly hourly
    - get_hourly_entry() replaces duplicated circular buffer accessor
    - Unify render_empty_battery text loop across large/small branches
    - Remove dead dotted parameter from draw_spline (all callers pass 0)
    - Remove unused large variable from render_temperature
    - Fold daily chart Y-range tracking into aggregation loop, use pad_y_range
    [DisplayRenderer.cpp]
2026-03-23 Heap-allocate monthly chart spline arrays to fix boot crash
    The three static int16_t[721] arrays in render_monthly_hourly() consumed
    4.3KB of permanent BSS. pioarduino's precompiled ESP32 libs are built
    with CONFIG_SPIRAM=y which creates a ~48KB BSS ceiling on boards without
    PSRAM — beyond that, pvPortMalloc fails for the FreeRTOS timer task and
    the device crash-loops on boot.
    Moving these to heap (malloc/free around render) keeps BSS under the
    threshold while avoiding stack overflow on the 8KB Arduino task stack.
    [DisplayRenderer.cpp]
2026-03-24 Power-gate DESPI-C02 via P-FET to eliminate 534µA deep sleep drain
    FDN340P on GPIO13/D7 cuts display adapter VCC during deep sleep.
    Measured ~18µA avg (down from ~562µA). Gated behind EPD_POWER_GATE
    define. Also fix font regeneration when switching displays.
    [Display.cpp]
2026-03-25 Use ULP temperature on timer wake, fix forced-mode read race
    On timer wake (safety-net), read the ULP's last completed measurement
    from RTC memory instead of doing a fresh I2C read that races with the
    still-running ULP. Also add 10ms delay after triggering forced mode in
    GetTemperatureC() to cover the fallback path (ULP I2C error, first
    boot, non-ULP boards) where readTempC() was returning 0°C from
    in-progress registers.
    [BMP390LSensor.cpp, Thermometer.cpp]
2026-03-25 Fix temperature "C" suffix wrapping to second line on small displays
    Replace cursor-advance-based "C" placement with explicit gap sizing
    using setTextWrap(false) to prevent overflow. The gap between the
    number and "C" is now 40% of the "C" glyph width, giving a consistent
    thin space that scales with font size across all display resolutions.
    Also add GIT_HASH fallback define for the native simulator build.
    [DisplayRenderer.cpp]
2026-03-25 Center temperature vertically using combined bounding box
    The centering formula was approximate — it assumed the text bounding
    box ended exactly at the baseline (tby == -tbh). Use the proper
    (zone_h - text_h) / 2 - tby formula and account for the "C" glyph
    being taller than digits for correct vertical centering in the zone.
    [DisplayRenderer.cpp]
2026-04-05 Add periodic NTP resync with adaptive interval and drift indicator
    The internal 150 kHz RC oscillator (CONFIG_RTC_CLK_SRC_INT_RC) drifts
    significantly without periodic correction — ~50 minutes over 11 days
    observed in practice. Resync weekly via NTP, measure drift, and adapt:
    shorten interval if drift >= 1 minute, double if negligible (floor 1 day,
    ceiling 4 weeks). Display "! DRIFT +Ns/Xd" indicator when significant.
    [Display.h, DisplayRenderer.cpp, MockData.h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]
2026-04-05 Verify suspicious ULP temperature readings with direct I2C re-read
    If a ULP/LP core temperature jumps more than 5°C from the previous
    reading, reclaim the I2C bus and do a forced-mode sensor read to
    confirm. Corrupt ULP transfers (e.g. non-atomic 3-byte read) are
    caught and replaced with the verified value. Tested on device with
    TEST_CORRUPT_ULP_TEMP flag that injects +50°C offset.
    [BMP390LCompensation.cpp, BMP390LSensor.cpp, Thermometer.cpp]
2026-04-05 Backfill sparkline gaps from stable temperature periods
    When temperature is stable overnight, no delta wakes occur and no
    sparkline entries are recorded. The renderer previously broke the line
    at 4-hour gaps, leaving a visible hole in the chart. Instead, backfill
    a point at the previous temperature just before the new reading to
    anchor the flat region. Also bump TEMP_HISTORY_SIZE from 96 to 192 to
    handle full daily temperature cycles with 0.1C threshold.
    [Display.h, DisplayRenderer.cpp, Thermometer.cpp]
2026-04-05 Group RTC history into struct with version and address checks
    Pack TempReading (6 vs 8 bytes), split RTC versioning into
    RTC_HISTORY_VERSION and RTC_STATE_VERSION so non-history changes
    can preserve temperature data across deep sleep. Add self_addr
    field to detect linker address shifts between firmware versions.
    Tested on device: RTC memory does not survive power-on reset on the
    FireBeetle board (both USB and button reset cause full RTC power
    cycle), so cross-upload persistence is not possible without flash
    storage. The version checks remain useful for OTA updates and
    boards with different reset behavior.
    [Display.h, Thermometer.cpp]
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2026-04-06 Fix sparkline zigzag by interpolating only Y in Catmull-Rom spline
    The sparkline used a parametric Catmull-Rom that interpolated both X
    and Y as functions of t. With backfill points clustered 1 second apart
    (from gap-filling), the spline tangents caused massive X-overshoot,
    making the chart line zigzag back and forth in time. Switch to linear
    X interpolation with Catmull-Rom only on Y, matching what the monthly
    chart helpers already do. Remove unused pt_arr (leftover from removed
    gap-breaking logic).
    [DisplayRenderer.cpp]
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2026-04-08 Fix ULP shared variables overlapping sparkline buffer in RTC memory
    ULP_DATA_BASE was set to word 200 (addr 0x50000320), which landed
    inside the .rtc.data section where historical_data.temp[25] lives.
    The ULP overwrote 6 words of the sparkline buffer every sleep cycle —
    ULP_VAR_SAMPLE_COUNT (=11) showed up as temp_x10=11 in the trace,
    confirming the overlap.
    Root cause: ULP program memory and RTC_DATA_ATTR variables share the
    same 8KB physical memory at 0x50000000. The old ULP_DATA_BASE (200)
    was chosen to clear the ULP program (~110 instructions) but didn't
    account for the .rtc.data section starting at word 128.
    Fix: move ULP_DATA_BASE to 1800 (past .rtc.force_slow which ends at
    word ~1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
    [Display.h, DisplayRenderer.cpp, Thermometer.cpp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]
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2026-04-10 Enable display and BMP58x on Xiao ESP32C6, fix platform build issues
    - Add board-conditional EPD pin mapping (C6: D6/D7/D9/D2/D3 → GPIO16/17/20/2/21)
    - Work around C6 SPI pin conflicts: GPIO20 (MISO) steals D/C, GPIO21 (SS)
    steals BUSY — pre-init SPI with MISO=-1 and SS=-1
    - Link ROM memcpy on C6 to fix misaligned flash read crash in WPA3 SAE
    (recompiled newlib memcpy uses word loads without checking source alignment)
    - Replace LP_CORE_I2C_DEFAULT_CONFIG() with explicit C++ struct init
    (designated initializers not valid in C++)
    - Skip ULP_DATA_BASE overlap check on C6 (only applies to ULP FSM, not LP core)
    - Switch LP core from LP_CORE_IDLE to LP_CORE_BMP58X
    - Fix USB CDC blocking: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
    [BMP390LSensor.cpp, BMP58xSensor.cpp, Display.cpp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]
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2026-04-19 Suppress sparkline backfill on drift-sized deltas
    Commit fa0d7c5 anchors the prior temperature whenever the gap since the
    last history entry exceeds one hour. On slow monotonic drift — where
    each 0.1°C ULP wake happens to sit past that cutoff — this inserts a
    near-vertical edge before every new point, producing a staircase in the
    rendered spline. 0.1°C is our sampling resolution, not a real step.
    Require both a long gap *and* a delta ≥ 0.2°C before backfilling, so
    slow drift renders as a smooth curve while genuine jumps (window open,
    heating cycle) still get their flat pre-jump period anchored.
    [Thermometer.cpp]
2026-04-19 Fix BMP58x forced-mode register value, move OSR write to init
    ODR_CONFIG was being written 0x01 which is BMP5_POWERMODE_NORMAL per
    Bosch bmp5_defs.h, not forced. The sensor was sampling continuously at
    default ODR 240 Hz between wakes (~200 µA) instead of returning to
    standby after each forced read. Change to 0x02 (BMP5_POWERMODE_FORCED).
    Once returned to standby and with all deep-standby entry conditions
    holding (deep_dis=0, FIFO off, IIR off, ODR=0), the sensor auto-enters
    deep standby (~0.5 µA) between wakes with no extra code.
    Also move the static OSR_CONFIG write out of the per-wake path (both
    ULP FSM and LP core programs as well as GetTemperatureC) into
    Initialize(), and call Initia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
    [BMP58xSensor.cpp, UlpProgramBMP58x.cpp]
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2026-04-20 Adapt monthly chart x-label stride to data span
    Shorten stride below 14 days of data so cold-start charts always show
    >=2 date labels for scale: 7d/3d/2d/1d at 14d/6d/3d/<3d thresholds.
    Weekly cadence is preserved once enough data has accumulated.
    [DisplayRenderer.cpp]
2026-04-20 Fix LP core BMP58x delta-wake byte-wrap, add lp wake count to footer
    LP core compared only data[1] (the middle byte of BMP58x output, 1/256°C
    per count) against a cached reference. When temperature crossed a whole-
    degree boundary data[1] wrapped 0xFF→0x00 producing a spurious 255-count
    delta and waking HP on essentially every LP cycle — observed as a large
    sustained HP burst every 60s in PPK2 traces even when the room
    temperature was steady enough that the display refresh was skipped.
    Switch the comparison to °C. LP core has no FPU but softfloat fits: the
    24-bit signed raw is sign-extended, divided by 65536 and compared
    against prev_temp_c with a 0.1°C threshold — same semantic as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
    [Display.h, DisplayRenderer.cpp, MockData.h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]
2026-04-20 Move lp_wake_count to start of LP routine, surface LP errors in UI
    lp_wake_count used to increment only after the sensor I2C read
    succeeded, so any wake that exited via wake_reason = 2 (LP I2C
    failure) woke HP without bumping the counter. That produced counts
    like #5 r3 lp1 where 4 of 5 HP wakes came from LP errors and were
    invisible. Increment at the top of the main loop so every wake
    attempt counts.
    To actually diagnose the errors, capture in LP shared memory:
    lp_error_count — cumulative wake_reason = 2 count
    last_lp_error — most recent esp_err_t
    last_lp_op — which step failed (1 = trigger write, 2 = data read)
    Footer now shows `e<N>` next to `lp<N>` when errors have occ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
    [Display.h, DisplayRenderer.cpp, MockData.h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]
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2026-04-21 Show date alongside time in info bar when space allows
    Picks the longest variant that fits between the battery text and the
    right edge: "Apr 21 2026 14:10" → "Apr 21 14:10" → "14:10". Large
    portrait displays get the full date with year; smaller/landscape
    layouts degrade gracefully to date-only or time-only. Skipped entirely
    before NTP sync (year < 2024).
    [DisplayRenderer.cpp]
2026-05-25 Wait for fresh SNTP response on resync, show last-sync age in footer
    Resync relied on getLocalTime(), which only checks tm_year and returns
    immediately on the already-set (drifted) clock — so it never waited for a
    new NTP packet. Drift measured ~0, the interval doubled toward the 4-week
    cap, and WiFi was torn down before SNTP responded, leaving the clock
    uncorrected. On the C6 (internal RC oscillator for deep-sleep timekeeping)
    this let the clock free-run hours fast over weeks.
    Add wait_for_sntp() polling sntp_get_sync_status(), and reset the sync
    status before waiting so the resync blocks for a genuinely fresh response.
    Track last_sync_time and render its age in the footer (s<N>m/h/d) so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
    [Display.h, DisplayRenderer.cpp, MockData.h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]
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2026-07-01 Fix stale font_config.h rendering oversized temperature text
    Font generation ran in a buildprog pre-action (link time), after
    DisplayRenderer.o was already compiled, so switching displays left the
    object bound to the previous panel's font — e.g. an 80pt glyph on a
    200x200 panel, clipped to fragments. get_temp_font() also silently fell
    through to a same-size default, masking the mismatch.
    - pre_build_fonts.py: regenerate fonts at script-eval time so the fresh
    font_config.h exists before compilation and SCons recompiles dependents
    in the same build (also fixes cold builds, where the header is absent)
    - generate_font.py: emit FONT_CONFIG_W/H for single-display builds
    - Display.cpp: log a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
    [Display.cpp]
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
